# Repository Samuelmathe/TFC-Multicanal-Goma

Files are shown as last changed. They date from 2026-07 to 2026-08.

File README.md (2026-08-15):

# TFC Multicanal Goma

Système embarqué IoT de sous-comptage électrique multicanal (ESP32),
développé dans le cadre d'un Travail de Fin de Cycle (ULPGL) : un boîtier
mesure et facture séparément la consommation électrique de plusieurs
locataires branchés sur une même installation, avec coupure automatique par
crédit prépayé et consultation via une application mobile Flutter.

## État du projet

- **Maquette physique** : construite, soudée sur carte perforée et
  **validée sur matériel réel** (4 canaux : 1 bailleur + 3 locataires,
  capteurs simulés par des potentiomètres). C'est cette maquette qui a servi
  à la validation présentée dans le mémoire.
- **Application mobile Flutter** : développée et testée en conditions
  réelles (connexion Wi-Fi à l'ESP32 depuis un téléphone Android).
- **PCB (circuit imprimé, 8 canaux, capteurs ACS712/ZMPT101B réels)** :
  conçu sous KiCad (dossier `kicad/`) — **routage non terminé, il reste 10
  pistes à tracer** ; non encore fabriqué ni assemblé. Le firmware cible pour
  ce PCB (`firmware_pcb_capteurs_reels/`) est écrit et compile, mais n'a donc
  pas pu être testé sur le matériel réel.

## Structure du dépôt

```
firmware/                      -> firmware de la maquette physique (4 canaux,
                                   potentiometres) - construit et valide
firmware_pcb_capteurs_reels/    -> firmware cible pour le PCB (8 canaux,
                                    ACS712 + ZMPT101B) - PCB pas encore
                                    fabrique, code non teste sur materiel reel
application/                     -> application mobile Flutter (Android/iOS)
kicad/                            -> conception du circuit imprime (PCB, 8 canaux)
rapport/                           -> memoire de TFC
presentation/                       -> support de soutenance
```

Chaque dossier de firmware a son propre `README.md` avec le détail de ce qui
a été testé ou non.

## Démarrer

- Firmware maquette : `cd firmware && pio run --target upload` (ESP32 branché
  en USB) — voir `GUIDE_ASSEMBLAGE_ET_FLASH.md` et `GUIDE_MAQUETTE_BOITIER.md`
  à la racine pour le montage physique.
- Application mobile : `cd application && flutter run` (ou `build_apk.sh`
  pour générer un APK).

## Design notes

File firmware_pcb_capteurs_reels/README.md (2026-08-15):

# Firmware "capteurs reels" (ACS712 + ZMPT101B, 8 canaux) — PCB

**Statut : non testé sur matériel réel.** Le circuit imprimé conçu sous
KiCad (dossier `../kicad/`) n'a pas encore été fabriqué ni assemblé. Ce
firmware est le design cible pour ce PCB à 8 canaux (chapitre 2 du mémoire),
écrit et documenté, mais jamais exécuté sur les vrais capteurs ACS712 /
ZMPT101B.

Pour la version **réellement construite et validée** (maquette sur carte
perforée, 4 canaux, potentiomètres simulant les capteurs, cf. rapport
chapitre 3), voir le dossier voisin [`../firmware/`](../firmware/).

## Ce qui diffère de la maquette

| | `firmware/` (maquette, validée) | `firmware_pcb_capteurs_reels/` (ce dossier) |
|---|---|---|
| Canaux | 4 (1 bailleur + 3 locataires) | 8 (1 bailleur + 7 locataires) |
| Capteur de courant | Potentiomètre (tension DC proportionnelle) | ACS712-20A (signal AC réel, RMS calculé sur 40 échantillons/cycle 50 Hz) |
| Capteur de tension | Potentiomètre | ZMPT101B |
| cos(φ) | Fixé à 1 (simplification assumée) | Calculé réellement : `P/S` à partir de `P`, `S = I_eff x V_eff`, `Q = √(S²-P²)` |
| Broches ADC | Toutes sur ADC1 | Canaux 1 et 2 + tension sur ADC2 (cf. Tableau 2.2 du mémoire), avec gestion explicite du conflit ADC2/Wi-Fi (`lireADC2Securise`) |
| Matériel exécuté dessus | ESP32 réel, testé et flashé | Aucun — code seul, PCB non fabriqué |

L'algorithme d'acquisition (échantillonnage synchrone courant/tension,
calcul RMS, puissance active/apparente/réactive, cos(φ) réel) suit
exactement la description du mémoire, §2.7.

## Constantes à calibrer avant toute mise en service

Ces valeurs, dans `src/config.h`, sont des valeurs nominales de datasheet ou
des estimations — **pas des mesures faites sur le circuit réel** (qui
n'existe pas encore) :

- `ACS712_SENSIBILITE_V_PAR_A` (100 mV/A, valeur datasheet Allegro pour la
  variante 20A — la tolérance fabricant réelle peut différer de quelques %)
- `ZMPT_FACTEUR_CALIBRATION` (rapport tension secteur réelle / tension RMS
  mesurée à l'ADC — dépend du pont diviseur exact du module ZMPT101B utilisé,
  à déterminer par comparaison avec un multimètre/wattmètre une fois le PCB
  assemblé)

Les offsets DC (Vcc/2 par canal) sont recalibrés automatiquement à chaque
démarrage (`calibrerOffsets()`), en supposant qu'aucun courant ne circule
encore à l'allumage.

## Limitation connue : ADC2 et Wi-Fi

Les canaux 1, 2 et la mesure de tension (ZMPT101B) utilisent l'ADC2 de
l'ESP32, qui n'est pas utilisable pendant que le pilote Wi-Fi l'occupe (le
point d'accès de la maquette tourne en permanence). Le firmware détecte ce
cas via le code retour d'`adc2_get_raw()` et ignore simplement l'échantillon
concerné (plutôt que d'enregistrer une fausse valeur, piège classique
d'`analogRead()` sur ADC2). Cf. mémoire §1.4.3 pour la discussion complète de
cette contrainte matérielle et son impact réduit sur le PCB final par
rapport à la maquette (fenêtres ponctuelles plutôt que Wi-Fi permanent).

## Compiler

Comme pour `firmware/` : `pio run` (compilation seule, aucun upload possible
sans le matériel).

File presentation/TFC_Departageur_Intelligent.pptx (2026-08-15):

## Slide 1

UNIVERSITÉ ULPGL — FACULTÉ DE GÉNIE INFORMATIQUE

Conception d'un Système IoT de

Comptage et de Coupure Automatique

d'Énergie pour la Gestion Transparente

en Milieu Locatif Urbain

Travail de Fin de Cycle — G3 Génie Informatique

Présenté par : SAMUEL MATHE | Encadreur : Master VINGI| Année : 2025–2026

📍 Goma, RDC

Mots-clés : ESP32 — IoT — ACS712 — ZMPT101B — Énergie — Milieu locatif — Goma

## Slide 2

PLAN DE PRÉSENTATION

Problématique

Contexte énergétique en milieu locatif à Goma

01

Hypothèse

Solution proposée et résultats attendus

02

Méthodologie

Architecture, composants et implémentation

03

Résultats attendus

Validation et impact mesurable

04

Conclusion

Bilan et perspectives

05

Démonstration

Maquette et application testees en direct

06

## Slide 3

01 PROBLÉMATIQUE

CONTEXTE — GOMA

Alimentation électrique : SOCODEE / Virunga / NURU
Structure des concessions :
Un compteur principal (bailleur)
Des sous-compteurs prépayés (locataires)
Problème observé :
Le bailleur se branche AVANT les sous-compteurs — consomme sur le crédit des locataires sans être mesuré.

CONSÉQUENCES

Augmentation injustifiée des coûts de production pour les locataires

Baisse de la rentabilité des ménages locataires

Conflits récurrents bailleur–locataires non résolus

Absence totale de transparence dans la consommation partagée

Coupures imprévisibles sans notification préalable

💸

📉

⚔️

🌍

🔌

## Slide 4

01 PROBLÉMATIQUE — Question de recherche

Question de recherche

Comment la mise en place d'un système embarqué IoT
pourrait-elle assurer une gestion équitable, transparente
et automatique de la consommation électrique entre
bailleur et locataires dans une concession résidentielle ?

~$15

Coût sous-compteur actuel

sans coupure automatique

7–8

Locataires par concession

moyenne Goma

0

Outil transparent existant

marché local actuel

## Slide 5

02 HYPOTHÈSE

Hypothèse principale

Un système embarqué à base d'ESP32, équipé de capteurs ACS712 (courant) et ZMPT101B (tension), couplé à des relais optocoupleurs et une interface web locale, permet de mesurer avec précision la consommation individuelle de chaque locataire, d'assurer une coupure automatique au dépassement du crédit, et de garantir une transparence totale — sans modifier l'installation existante et pour un coût inférieur à $30.

⚡ Mesure précise

Courant (ACS712) × Tension réelle (ZMPT101B) = kWh exact

🔒 Coupure automatique

Relais ouvre quand crédit = 0 — aucune intervention manuelle

📱 Interface transparente

Locataire voit son crédit, historique et recharges en temps réel

💰 Coût accessible

<$30/unité* — partagé entre 8 personnes = <$3.75 chacun*

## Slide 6

03 MÉTHODOLOGIE — Architecture du système

⚡ ZONE 220V — Haute tension

HLK-PM01
220V→5V
$2

ZMPT101B
Mesure tension
$0.8

Relais 8ch
Pilotage ULN2003A
$2.5

Bornes sorties
À vis étiquetées
$1.5

━━━ CLOISON ISOLANTE PLASTIQUE ━━━━━━━━━━━━━━━━━━━━━━━━━━━━━━━━━━━━━━━━━━━━━━━━

Seuls les fils signal GPIO 3.3V traversent la cloison — isolation galvanique garantie

🔵 ZONE 5V — Basse tension

ESP32 DevKit
Dual Core Wi-Fi
$4

ACS712 ×8
Mesure courant
$6.4

TP4056
Charge LiPo
$0.5

LiPo 2000mAh
Alimentation cont.
$2.5

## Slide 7

03 MÉTHODOLOGIE — Composants et budget

Composant | Rôle | Qté | Prix unit. | Total
ESP32 DevKit V1 | Centrale Wi-Fi + logique | 1 | $4.00 | $4.00
Relais 8 canaux optocoupleur | Coupure automatique | 1 | $2.50 | $2.50
ACS712 20A | Mesure courant par locataire | 8 | $0.80 | $6.40
ZMPT101B | Mesure tension réseau réelle | 1 | $0.80 | $0.80
HLK-PM01 220V→5V | Alimentation isolée | 1 | $2.00 | $2.00
TP4056 + protection | Charge batterie LiPo | 1 | $0.50 | $0.50
LiPo 3.7V 2000mAh | Alimentation continue | 1 | $2.50 | $2.50
Bornes à vis + câblage | Connexions sorties | 1 kit | $3.50 | $3.50
Boîtier électrique | Protection + sécurité | 1 | $4.00 | $4.00
TOTAL MATÉRIEL | | | | ~$26.20

💡 <$3.75* / personne
*à l'échelle de 100 unités — prototype unique : 60-90$
(8 personnes : bailleur + 7 locataires)

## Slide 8

03 MÉTHODOLOGIE — Firmware et calcul kWh

kWh = P active × Temps (h) ÷ 1000 (P calculee, cos(φ) jamais suppose)

Formule de calcul — Énergie consommée

Lecture capteurs

- ZMPT101B → ADC2 GPIO25
- Tension réelle (pas 220V fixe)
- ACS712 ×8 → ADC1 GPIO36-39,32-35
- Courant par locataire
- Filtrage : moyenne de 8 mesures

Logique de coupure

- Calcul kWh chaque seconde
- Déduction du crédit locataire
- Crédit = 0 → relais OUVRE
- Coupure automatique immédiate, ou volontaire (absence)
- Alerte Wi-Fi vers interface

Sauvegarde NVS

- kWh sauvegardé toutes les 5 sec
- Batterie ≤25% → sauvegarde forcée
- Résistant aux coupures 220V
- Données jamais perdues
- Historique 30 jours conservé

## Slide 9

03 MÉTHODOLOGIE — Interface web locale

📶 ESP32 Access Point — SSID: Departageur — Aucun internet requis

🔐 Bailleur — Accès sécurisé

Route : /admin

- Mot de passe requis côté ESP32
- Ajout du courant de locataire
- Saisie crédit kWh par locataire
- Date et heure de chaque recharge
- Vue globale tous locataires
- Coupure / rétablissement manuel
- Configuration du système

👁 Locataires — Lecture seule

Route : /L1 à /L7

- Crédit restant en kWh — temps réel
- Consommation actuelle (Watts)
- Conversion kwh restant-monnaie visuelle
- Historique recharges avec dates
- Peut comparer avec facture bailleur
- Alerte crédit faible automatique
- Historique jour / semaine / mois

🔒 Sécurité : vérification mot de passe côté ESP32 (pas en JavaScript) — Reset physique si oublié — Boîtier fermé à clé

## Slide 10

04 RÉSULTATS ATTENDUS

❌ AVANT — Situation actuelle

- Bailleur consomme sans être mesuré
- Aucune transparence sur la consommation
- Coupure manuelle par le bailleur uniquement
- Conflits récurrents non résolus
- Sous-compteur $15 sans coupure auto
- Locataire ne peut pas vérifier sa consommation

✅ APRÈS — Avec le système

- Chaque consommation mesurée individuellement
- Interface web — historique transparent
- Coupure automatique au dépassement du crédit
- Conflits résolus par preuves numériques
- Coût partagé <$3.75* par personne
- Locataire voit son crédit en temps réel

→

Perspectives : V2 — 16 canaux | App Flutter (APK fonctionnel, testee sur maquette physique) | Partenariat revendeur agréé (PayIt/Fondeka) pour intégration SOCODEE/Virunga/NURU

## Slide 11

05 CONCLUSION

Ce projet démontre qu'un système IoT embarqué à faible coût peut résoudre un problème social et économique réel vécu quotidiennement à Goma — sans infrastructure internet, sans modification de l'installation existante, avec une transparence totale pour toutes les parties.

🔬

Technique

ESP32 + C++
ACS712 + ZMPT101B
Firmware complet
App Flutter (3 profils, testee)

💰

Économique

<$30/unité*
<$3.75* chacun
ROI immédiat

🤝

Social

Fin des conflits
Transparence totale
Équité énergétique

🚀

Perspective

V2 16 canaux
Notifications SMS (GSM)
Partenariat PayIt/Fondeka

Merci pour votre attention — Questions et suggestions bienvenues

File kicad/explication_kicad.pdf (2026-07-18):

# Explication et guide KiCad — TFC Système Multicanal

### Notions de base + pas-à-pas pour dessiner le schéma

### Document préparé pour Samuel Mumbere Mathe — ULPGL

### Juillet 2026

## Table des matières

Introduction | 1
Partie 1 — Les bases de KiCad et de l’électronique qu’il faut connaître | 1
Partie 2 — Guide pas-à-pas : dessiner le schéma | 3

## Introduction

Ce document a deux parties : d’abord les notions de base pour comprendre ce qu’on fait dans KiCad (utile même si tu ne dessines rien toi-même, pour répondre au jury), puis le guide pratique, pas-à-pas, pour redessiner le schéma de ton système à 8 canaux.

## Partie 1 — Les bases de KiCad et de l’électronique qu’il faut connaître

### C’est quoi KiCad ?

KiCad est un logiciel gratuit de conception électronique (on dit “EDA” : Electronic Design Automation). Il sert à transformer une idée de circuit en un vrai fichier de fabrication qu’une usine peut lire pour produire un circuit imprimé (PCB). Il y a deux grands outils dans KiCad :

1. Schematic Editor (éditeur de schéma) — où on dessine le schéma électrique : quels composants, et comment ils sont reliés entre eux (comme un plan, pas encore un objet physique).
2. PCB Editor (éditeur de circuit imprimé) — où on transforme ce schéma en un vrai dessin de plaque, avec l’emplacement physique de chaque composant et le tracé des pistes de cuivre qui les relient.

Ton mémoire (§2.5) couvre les deux : le schéma (§2.5.1-2.5.2) puis le PCB (§2.5.3-2.5.4). Ce guide se concentre sur le schéma d’abord — le PCB est l’étape suivante, une fois le schéma solide (voir le document séparé explication_pcb.pdf).

### C’est quoi un “symbole” ?

Un symbole, c’est la représentation graphique standardisée d’un composant sur un schéma — un rectangle avec des pattes numérotées pour une puce, un zigzag pour une résistance, etc. Ce n’est pas un dessin réaliste du composant, juste une convention universelle pour que n’importe quel ingénieur comprenne le schéma. Chaque symbole est identifié par un nom, rangé dans une bibliothèque (un fichier .kicad_sym qui contient plusieurs symboles apparentés, par exemple tous les microcontrôleurs Espressif).

### C’est quoi une “empreinte” (footprint) ?

Une empreinte, c’est le dessin de l’emplacement physique réel des pattes d’un composant sur le circuit imprimé (les petits rectangles de cuivre où on soudera le composant). Un même symbole électrique (par exemple une résistance) peut avoir plusieurs empreintes possibles, selon la taille physique du composant qu’on va réellement souder. On choisit l’empreinte à l’étape PCB, pas à l’étape schéma.

### C’est quoi un “netlist” ?

Une fois le schéma terminé, KiCad peut en extraire une liste de toutes les connexions électriques prévues (“la broche 3 du composant A est reliée à la broche 1 du composant B”, etc.) — c’est le netlist. C’est ce fichier qui fait le pont entre le schéma et le PCB : KiCad l’utilise pour savoir quelles pistes de cuivre tracer.

### C’est quoi l’ERC (Electrical Rules Check) ?

Un vérificateur automatique qui relit ton schéma et signale les erreurs probables : une broche qui n’est reliée à rien, deux sorties reliées directement entre elles (conflit électrique), etc. Toujours le lancer avant de continuer — c’est l’équivalent d’un correcteur orthographique, mais pour un circuit.

### Zone haute tension / basse tension, isolation galvanique

Ton système manipule à la fois du 230V (secteur) et du 3.3V/5V (électronique de l’ESP32). Physiquement séparer ces deux zones sur le schéma et sur le circuit imprimé (avec une distance de sécurité suffisante entre les pistes) est une exigence de sécurité, pas juste d’organisation — un défaut du côté 230V ne doit jamais pouvoir atteindre la partie que l’utilisateur touche (l’ESP32, le port USB…). C’est exactement ce que rappelle ton mémoire en §1.3.4 et §2.5.1, et que les capteurs ACS712/ZMPT101B assurent physiquement (isolation galvanique = aucune connexion électrique directe entre les deux côtés, seulement un couplage magnétique ou optique).

## Partie 2 — Guide pas-à-pas : dessiner le schéma

Tu peux commencer avant d’avoir l’ESP32 physique — rien ici ne demande le matériel en main.
État au 17 juillet : d’après ton fichier multical.kicad_sch, il te manque un deuxième ULN2003A (tu n’en as qu’un, avec 7 sorties pour 8 relais — voir étape 3 ci-dessous) et le câblage n’est pas encore fait — voir la correction du Tableau 2.2 à l’étape 5 avant de commencer à câbler.

### Étape 0 — Lancer KiCad

Deux installations existent sur cette machine : une snap (KiCad 9.0.7, périmée) et une flatpak (KiCad 10.0.4, la version stable actuelle, vérifiée en juillet 2026). Utilise la flatpak :

flatpak run org.kicad.KiCad

(ou depuis le menu applications — si deux icônes “KiCad” apparaissent, vérifie dans Aide → À propos que tu ouvres bien la 10.0.4)

### Étape 1 — Créer le projet

1. Fichier → Nouveau projet
2. Nomme-le multicanal_goma (évite les espaces/accents dans le nom de fichier — KiCad n’aime pas toujours ça)
3. Sauvegarde-le directement dans : ~/Documents/TFC-Multicanal-Goma/kicad/ (là où se trouve déjà ce guide et le symbole zmpt101b.kicad_sym, à côté du firmware et de l’application)
4. Double-clique sur l’icône Schematic Editor (feuille bleue) dans la fenêtre du projet

### Étape 2 — Format de feuille

Fichier → Propriétés de la feuille → choisis A3 (le schéma a beaucoup de composants, A4 sera trop serré). Remplis le cartouche (titre, date, ton nom, “Encadreur: Patrick Nzanzu Vingi” — retrouvé dans un ancien fichier de travail).

### Étape 3 — Placer les composants

Touche A (ou icône “Placer un symbole”) ouvre le sélecteur. Tape le nom exact ci-dessous dans la barre de recherche.

Important : un ancien fichier de travail contenait des noms de composants qui n’existent pas réellement dans les bibliothèques KiCad — c’est probablement pour ça qu’il ne s’ouvrait plus. Chaque nom ci-dessous a été vérifié individuellement contre les vraies bibliothèques installées sur ta machine, dans les deux versions de KiCad présentes (9.0.7 et 10.0.4 — identiques sur ce point).

Cherche exactement | Bibliothèque réelle | Combien | Où le placer
ESP32-WROOM-32 | RF_Module | 1 | Centre
ACS712xLCTR-20A | Sensor_Current | 8 | Colonne de gauche,
| | | zone BT

Cherche exactement | Bibliothèque réelle | Combien | Où le placer
ULN2003A | Transistor_Array | 2 | Entre ESP32 et
| | | relais (chacun pilote
| | | jusqu’à 7 sorties, 2
| | | suffisent pour 8
| | | relais — tu n’en as
| | | qu’1 pour l’instant)
Relay_SPDT | Relay | 8 | Colonne de droite,
| | | zone HT (voir note
| | | ci-dessous)
HLK-PM01 | Converter_ACDC | 1 | Zone HT →
| | | alimentation
AMS1117-3.3 | Regulator_Linear | 1 | Zone BT, juste après
| | | le HLK-PM01
D (diode générique) | Device | 8 | Une en parallèle de
| | | chaque relais (roue
| | | libre)
R | Device | 5 | Pull-up strapping
| | | pins + limitation
| | | courant
C | Device | 5 | Découplage (près
| | | des VCC ACS712 et
| | | ESP32)
Conn_01x02_Pin | Connector | 9 | Un par canal +
| | | alimentation secteur

ZMPT101B — pas dans les bibliothèques standard

Ce capteur n’existe dans aucune bibliothèque KiCad officielle (normal, c’est un module très “communauté Arduino”, pas un composant industriel référencé). Un symbole personnalisé valide existe déjà dans ~/Documents/TFC-Multicanal-Goma/kicad/zmpt101b.kicad_sym (6 broches : L, N, GND, GND, VCC, OUT — correspond au vrai module), et tu l’as déjà importé avec succès (visible sur ton schéma actuel, U12).

Relais SLA-05VDC-SL-A — pas de symbole exact non plus

Le nom précis “SLA-05VDC-SL-A” (celui des modules relais tout faits pour Arduino) n’a pas de symbole officiel KiCad. Le symbole générique Relay_SPDT (déjà utilisé sur ton schéma pour K1-K8) est fonctionnellement identique — bobine 5V + contact inverseur. Pense à changer le champ Valeur de “Relay_SPDT” à “SLA-05VDC-SL-A” dans les propriétés de chaque relais pour que ta nomenclature (BOM) reste exacte.

### Étape 4 — Séparer les zones HT et BT (§2.5.1 du mémoire)

C’est le point que ton mémoire promet déjà — respecte-le visuellement dans le schéma, pas juste dans le texte. Sur ton schéma actuel, les 8 relais/diodes sont déjà groupés à droite et l’électronique basse tension à gauche, ce qui va dans le bon sens, mais il manque encore la séparation explicite :

- Zone haute tension (230V), à droite ou en haut de la feuille : arrivée secteur (Conn_01x02_Pin), les 8 relais, le HLK-PM01.
- Zone basse tension (3.3V/5V), à gauche ou en bas : ESP32, les 8 ACS712, l’AMS1117, les ULN2003A.

- Le ZMPT101B et les ACS712 sont la frontière (isolation galvanique, cf. §1.3.4) — dessine une ligne ou une boîte en pointillés entre les deux zones sur la feuille, avec une annotation “ISOLATION GALVANIQUE” comme rappel visuel pour le jury.

### Étape 5 — Câblage : reprends le Tableau 2.2 (corrigé) du mémoire

Correction importante : contrairement à ce qui était dit dans une version précédente de ce guide, le symbole ESP32-WROOM-32 que tu utilises (vérifié directement dans la bibliothèque KiCad) n’a pas non plus les broches GPIO37/GPIO38 — elles n’existent pas sur ce module, DevKitC ou pas. Il n’y a donc que 6 broches ADC1 réellement utilisables (36, 39, 32, 33, 34,
35) pour 8 canaux. Les canaux 2 et 3 sont déplacés sur ADC2 (GPIO26, GPIO27), sur le même principe déjà utilisé pour le ZMPT101B (lecture pendant les fenêtres où le Wi-Fi est inactif, cf. §1.4.3 du mémoire — désormais 3 signaux à gérer ainsi au lieu d’1, mais aucun composant supplémentaire nécessaire) :
Canal | ACS712 → ESP32 ADC | Relais → ESP32 (via ULN2003A)
1 (bailleur) GPIO36 | ADC1 GPIO4
2 | GPIO26 | ADC2 GPIO5
3 | GPIO27 | ADC2 GPIO13
4 | GPIO39 | ADC1 GPIO14
5 | GPIO32 | ADC1 GPIO16
6 | GPIO33 | ADC1 GPIO17
7 | GPIO34 | ADC1 GPIO18
8 | GPIO35 | ADC1 GPIO19

ZMPT101B → GPIO25 (ADC2).
Évite ces broches pour toute nouvelle affectation (broches de configuration au démarrage, dites “strapping pins”, déjà notées en §2.5.2 du mémoire) : GPIO0, GPIO2, GPIO12, GPIO15.
Pour tracer un fil : touche W (wire), clique départ, clique arrivée. Pour nommer un fil (utile pour les signaux qui se répètent, ex. CANAL1_ACS) : sélectionne-le puis touche L (label). Donner le même nom à deux bouts de fil différents les relie électriquement, sans avoir à tracer un trait continu à travers toute la feuille — pratique pour éviter un schéma illisible avec des lignes qui se croisent partout.

### Étape 6 — Vérifier avant de continuer

Inspecter → Vérification des règles électriques (ERC) — lance-le, corrige les erreurs (broches non connectées, conflits de type de pin). Ne passe au routage du circuit imprimé (PCB, §2.5.3 du mémoire) qu’une fois l’ERC propre.

### Étape 7 — Sauvegarder correctement

Ctrl+S régulièrement. KiCad enregistre automatiquement les définitions complètes des symboles utilisés dans le fichier — tant que tu passes par le vrai logiciel (et pas un script), un fichier cassé comme l’ancien ne peut pas se reproduire.

### Et après ?

Une fois le schéma terminé et l’ERC propre, l’étape suivante est le routage du circuit imprimé — voir le document séparé explication_pcb.pdf, déjà prêt pour cette étape.

Reviens vers moi avec une capture d’écran ou une description si tu bloques sur un placement ou un câblage précis — je peux aussi lire un export PDF du schéma directement si tu me donnes le chemin du fichier.

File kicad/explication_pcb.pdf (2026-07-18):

# Explication et guide PCB — TFC Système Multicanal

### Notions de base + pas-à-pas pour router le circuit imprimé (§2.5.3-2.5.4)

### Document préparé pour Samuel Mumbere Mathe — ULPGL

### Juillet 2026

## Table des matières

Introduction | 1
Partie 1 — Les bases du PCB qu’il faut connaître | 1
Partie 2 — Pas-à-pas pour ta carte | 3

## Introduction

Ce guide couvre l’étape suivante du schéma déjà expliqué dans explication_kicad.pdf : transformer le schéma terminé en un vrai circuit imprimé (PCB) routé, prêt à envoyer en fabrication. Lis-le une fois ton schéma terminé et son ERC propre (cf. guide précédent, étape 6).

## Partie 1 — Les bases du PCB qu’il faut connaître

### Du schéma au PCB : le netlist

Quand tu ouvres le PCB Editor depuis un projet dont le schéma est terminé, KiCad propose Mettre à jour le PCB depuis le schéma (icône avec une flèche verte, ou Outils → Mettre à jour le PCB depuis le schéma). Cette action lit le netlist (déjà défini en Partie 1 du guide précédent) et fait apparaître, en vrac sur le côté de la feuille PCB, tous les composants du schéma sous forme d’empreintes (footprints) — reliés entre eux par des fils fantômes appelés ratsnest (“nid de rat” — les lignes droites qui indiquent quelles pattes doivent finir connectées, avant que tu traces les vraies pistes).

### Les couches (layers)

Un circuit imprimé est fait de plusieurs couches empilées. Pour un projet comme le tien, une carte 2 couches suffit largement (plus simple et moins chère qu’une carte 4+ couches, qui serait nécessaire pour un projet beaucoup plus dense) :

- F.Cu (couche cuivre du dessus) et B.Cu (couche cuivre du dessous) : où passent les pistes électriques
- F.SilkS / B.SilkS : la sérigraphie (texte et repères imprimés en blanc sur la carte, pour identifier les composants)
- F.Mask / B.Mask : le masque de soudure (la couche verte/autre couleur qui protège le cuivre, avec des trous là où on doit souder)
- Edge.Cuts : le contour de la carte (sa forme découpée)

### Empreinte (footprint) : le lien manquant

Chaque symbole du schéma doit avoir une empreinte assignée avant de passer au PCB — sinon KiCad ne sait pas quel dessin physique utiliser. Les composants “standards” (résistance, condensateur, ESP32…) ont souvent une empreinte par défaut déjà liée. Mais pour les composants génériques ou personnalisés de ton projet — le Relay_SPDT (renommé “SLA-05VDC-SL-A”) et le zmpt101b personnalisé — il faudra assigner une empreinte toi-même :
1. Outils → Attribuer les empreintes (ou Éditeur d'associations d'empreintes)
2. Pour chaque composant sans empreinte, cherche dans la bibliothèque une empreinte dont l’espacement de pattes correspond à ton composant réel (mesure au pied à coulisse si tu as le composant en main, ou regarde la fiche technique du vendeur)

### Largeur des pistes : pas la même partout

Une piste de cuivre trop fine chauffe et peut griller si elle transporte trop de courant — l’équivalent d’un fil électrique trop fin dans une installation domestique. KiCad a un outil intégré : Outils → Calculateur d’impédance des pistes / Calculateur PCB (Track Width Calculator), qui donne la largeur minimale nécessaire selon le courant à faire passer et l’échauffement toléré.

Deux catégories bien différentes sur ta carte : - Pistes de signal (GPIO, communication) : très fines, quelques dixièmes de mm suffisent, aucun souci de courant. - Pistes de puissance (230V secteur, alimentation des relais, retour des ACS712) : dimensionne-les pour le courant maximal réel du canal (rappel de ton mémoire : ACS712 20A, mais la charge réelle par canal sera probablement bien inférieure — utilise le courant que tu attends vraiment, pas la pleine échelle du capteur). Une piste plus large que nécessaire n’est jamais un problème, seulement plus étroite que nécessaire.

### Distance de sécurité HT/BT (creepage)

C’est le point le plus important de ton PCB, déjà annoncé au chapitre 2.5.1 de ton mémoire. Il n’existe pas “une seule valeur magique” — la distance nécessaire dépend de la tension, de l’épaisseur du vernis, de l’altitude, etc. (normes IEC 60664-1 / IPC-2221 pour qui veut creuser). En pratique, pour un projet de ce type (230V, usage intérieur, carte grand public) :

- Beaucoup de conception “prosumer” retiennent une distance minimale de l’ordre de 6 à

### 8 mm entre une piste 230V et n’importe quelle piste basse tension, comme point de dé-

part raisonnable et cité couramment dans la littérature hobbyiste/prosumer — vérifie et documente cette valeur dans ton mémoire comme une hypothèse de sécurité, pas comme une certification, ton travail n’ayant pas été testé/certifié par un laboratoire.
- Pour renforcer visuellement et physiquement cette séparation, une pratique courante est de découper une fente (slot) dans la carte entre les deux zones (juste un rectangle vide dans le PCB) — ça augmente la distance réelle que le courant devrait parcourir en cas de défaut, au-delà de la simple distance en ligne droite.
- Le fabricant de PCB que tu utiliseras (JLCPCB ou autre) publie ses propres règles minimales de fabrication (largeur de piste, espacement, diamètre de perçage) — vérifie-les avant de finaliser, elles peuvent être plus contraignantes que ce que KiCad accepte par défaut.

### DRC (Design Rules Check) — l’ERC du PCB

Comme l’ERC pour le schéma, le DRC vérifie le PCB : pistes trop proches, composants qui se chevauchent, trous mal dimensionnés, zones non connectées. Toujours lancer le DRC avant d’exporter les fichiers de fabrication (Inspecter → Vérification des règles de conception).

### Via

Un via, c’est un petit trou métallisé qui fait passer une piste d’une couche de cuivre à l’autre (du dessus vers le dessous de la carte). Utile quand une piste ne peut pas continuer tout droit sur la même face à cause d’un autre composant ou d’une autre piste sur son chemin.

### Fichiers de fabrication (Gerber, drill, BOM) — §2.5.4 du mémoire

Une fois le routage terminé et le DRC propre :

- Fichier → Fabrication → Fichiers Gerber : génère un fichier par couche (cuivre dessus, cuivre dessous, sérigraphie, masque de soudure…) — le format universel que toutes les usines de PCB comprennent.
- Fichier → Fabrication → Fichier de perçage : la position et le diamètre de chaque trou.
- Outils → Générer la nomenclature (BOM) : la liste de tous les composants avec leurs références, pour commander/assembler.

La plupart des fabricants (JLCPCB, PCBWay…) acceptent directement un .zip contenant tous ces fichiers.

## Partie 2 — Pas-à-pas pour ta carte

### Étape 1 — Ouvrir l’éditeur PCB et importer le schéma

Depuis la fenêtre du projet KiCad, double-clique sur PCB Editor, puis Outils → Mettre à jour le PCB depuis le schéma. Tous tes composants apparaissent en tas sur le côté, reliés par le ratsnest.

### Étape 2 — Dessiner le contour de la carte

Sélectionne la couche Edge.Cuts (en bas de la fenêtre), puis dessine un rectangle (ou la forme voulue) avec l’outil ligne/rectangle. Prévois de la place pour 8 canaux + les composants d’alimentation — commence par une carte assez grande (tu pourras réduire à une version future si besoin).

### Étape 3 — Placer les empreintes en respectant les zones HT/BT

Reprends exactement la même logique que sur le schéma (§2.5.1 du mémoire, déjà appliquée dans le guide précédent) : place les composants haute tension (relais, HLK-PM01, bornier secteur) d’un côté de la carte, et les composants basse tension (ESP32, ACS712, AMS1117, ULN2003A) de l’autre — avec une bande vide (la distance de sécurité, cf. Partie 1) qui les sépare visuellement sur la carte, pas seulement sur le schéma.

Touche M pour déplacer une empreinte sélectionnée, R pour la faire pivoter.

### Étape 4 — Router les pistes

Touche X (ou icône piste) pour commencer une piste depuis une pastille ou un ratsnest, clic pour poser un point, clic droit ou Échap pour terminer. Utilise le calculateur de largeur de piste (Partie 1) avant de router les lignes de puissance — change la largeur de piste active avant de commencer à tracer (barre d’outils en haut, “Largeur de piste actuelle”).

Conseil pratique : route d’abord les pistes de puissance (plus larges, plus contraignantes à placer), puis les pistes de signal (plus fines, plus faciles à faire passer entre les autres).

### Étape 5 — Vérifier

Inspecter → Vérification des règles de conception (DRC) — corrige tout ce qui est signalé avant de continuer. Regarde aussi la vue 3D (Affichage → Visualiseur 3D) pour repérer visuellement un composant mal placé ou qui se chevauche avec un autre.

### Étape 6 — Exporter pour la fabrication

Une fois le DRC propre : génère les Gerber, le fichier de perçage et la BOM (Partie 1). Regroupe-les dans un .zip et c’est prêt à envoyer chez le fabricant.

Reviens vers moi une fois le schéma terminé, avant de commencer le routage — je peux relire un export du PCB (image ou PDF) et repérer un souci de placement ou de distance HT/BT avant que tu envoies en fabrication.

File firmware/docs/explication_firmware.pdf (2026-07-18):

# Explication du firmware — TFC Système Multicanal

### Guide pas-à-pas pour quelqu’un qui ne connaît pas le C++

### Document préparé pour Samuel Mumbere Mathe — ULPGL

### Juillet 2026

## Table des matières

Introduction | 2
Partie 1 — Les bases du C++ qu’il faut connaître | 2
Partie 2 — config.h : les réglages du système | 3
Partie 3 — Vue d’ensemble de main.cpp | 4
Partie 4 — Explication détaillée, bloc par bloc | 5
Partie 5 — Comment tout s’articule (résumé visuel) | 11
Glossaire rapide | 12

## Introduction

Ce document explique, ligne par ligne et sans rien supposer connu, le fichier src/main.cpp du projet firmware (et son fichier de réglages src/config.h). Ce code fait tourner ton système à 5 canaux sur l’ESP32 : il lit les potentiomètres, calcule courant/puissance/énergie, gère les crédits, coupe les canaux, sauvegarde les données, et sert une API web.

Tu n’as pas besoin de tout retenir. L’objectif est qu’en relisant ton code tu puisses répondre si un membre du jury demande “qu’est-ce que fait cette ligne ?” — pas de devenir développeur C++ en une lecture.

## Partie 1 — Les bases du C++ qu’il faut connaître

Le C++ est le langage utilisé pour programmer les microcontrôleurs comme l’ESP32 (via l’environnement Arduino/PlatformIO). Voici uniquement les notions utilisées dans ton fichier — pas tout le langage.

### Une variable

Une variable, c’est une boîte étiquetée qui contient une valeur. En C++, il faut dire de quel type est la valeur avant de pouvoir l’utiliser :
int | age = 25; | // int = nombre entier
float | tension = 3.3; | // float = nombre a virgule (decimal)
bool | allume = true; | // bool = vrai ou faux (true/false)
String nom = "Samuel"; | // String = texte

Dans ton fichier, tu verras énormément int, float, bool, String — ce sont juste les types de boîtes.

### Une constante

const veut dire “cette boîte ne changera jamais après avoir été remplie”. static const int PIN_TENSION = 25; veut dire : la broche du capteur de tension, c’est GPIO25, et ça ne changera pas pendant l’exécution.

### Un tableau

Un tableau, c’est une rangée de boîtes numérotées à partir de 0 :

int notes[3] = {12, 15, 9};
// notes[0] = 12
// notes[1] = 15
// notes[2] = 9

Dans config.h, PIN_COURANT[NUM_CANAUX] est un tableau de 5 cases, une par canal, qui contient le numéro de broche GPIO de chaque potentiomètre.

### Une fonction

Une fonction, c’est une recette : elle prend des ingrédients (les “paramètres”), fait des opérations, et parfois rend un résultat.

float doubler(float x) { // "doubler" prend un float, rend un float
return x * 2;
}

void veut dire “cette fonction ne rend rien, elle fait juste une action”. La plupart des fonctions de ton fichier sont void.

### Une structure (struct)

Une structure, c’est une fiche avec plusieurs champs regroupés sous un même nom. Ton fichier définit CanalEtat : la fiche d’un canal, avec son courant, sa puissance, son crédit, etc. — tout regroupé, comme une fiche de renseignements pour chaque locataire.

struct CanalEtat {
float courant_A;
float credit_USD;
};
CanalEtat canaux[5]; | // 5 fiches, une par canal
canaux[0].credit_USD = 10; | // remplir le champ credit_USD de la fiche 0

### Boucles et conditions

- for (int i = 0; i < 5; i++) { ... } = répète ce qui est entre accolades, pour i allant de 0 à 4 (5 fois). C’est ce qui permet de traiter les 5 canaux avec un seul bout de code au lieu d’écrire 5 fois la même chose.
- if (condition) { ... } = si la condition est vraie, fais ceci.
- for (;;) { ... } = boucle infinie, ne s’arrête jamais (utilisé dans chaque tâche : elle tourne pour toujours tant que l’ESP32 est allumé).

#include

#include <WiFi.h> = “j’ai besoin des outils du Wi-Fi, va les chercher”. C’est comme importer une bibliothèque de fonctions déjà écrites par quelqu’un d’autre (Espressif, la communauté Arduino…), pour ne pas réinventer la gestion du Wi-Fi, du JSON, etc. depuis zéro.

### Le pointeur * et la référence & (juste pour ne pas être surpris)

Tu verras void *param ou AsyncWebServerRequest *request. Un pointeur, c’est une variable qui contient l’adresse d’une autre donnée, plutôt que la donnée elle-même — un peu comme une adresse postale au lieu de la maison. Tu n’as pas besoin de savoir manipuler ça toi-même pour ce TFC : retiens juste que * est présent quand une fonction accède à quelque chose d’externe (par exemple, la requête HTTP envoyée par un navigateur).

## Partie 2 — config.h : les réglages du système

Ce fichier ne fait rien tout seul — c’est une liste de constantes utilisées partout ailleurs, regroupées à un seul endroit pour être faciles à changer.

#define NUM_CANAUX 5

#define remplace littéralement NUM_CANAUX par 5 partout dans le code avant la compilation. C’est le nombre de canaux de la maquette (1 bailleur + 4 locataires, cf. mémoire §3.6.1).

static const int PIN_COURANT[NUM_CANAUX] = {36, 39, 34, 35, 32};

Le tableau des broches GPIO où sont branchés les 5 potentiomètres “courant” (qui simulent les ACS712). PIN_COURANT[0] = 36 = le canal 0 (bailleur) est lu sur la broche GPIO36. static const int PIN_TENSION = 25;

La broche du potentiomètre “tension” (qui simule le ZMPT101B) — un seul, partagé par tous les canaux.
static const int PIN_RELAIS[NUM_CANAUX] = {4, 5, 13, 14, 16};

Les broches qui commandent les LED (qui simulent les relais). static const float COURANT_MAX_A = 20.0f;
static const float TENSION_MAX_V = 250.0f;

Les valeurs maximales simulées : quand un potentiomètre est tourné à fond, on considère que ça représente 20 A (courant) ou 250 V (tension). Le f à la fin veut juste dire “c’est un float, pas un entier”.
static const float TARIF_USD_PAR_KWH = 0.20f;
static const float CREDIT_INITIAL_USD = 0.05f;

Le prix du kWh (0,20 USD) et le crédit de départ de chaque canal (volontairement très bas — 0,05 USD — pour que la coupure automatique se déclenche vite pendant une démonstration, sans avoir à attendre longtemps).

static const uint32_t PERIODE_ACQUISITION_MS = 500;

uint32_t = encore un type de nombre entier (toujours positif, sur 32 bits — détail technique sans importance ici). Cette ligne dit : on relit les capteurs toutes les 500 millisecondes (0,5 seconde).

## Partie 3 — Vue d’ensemble de main.cpp

Avant les détails, voici le plan général du fichier :

1. Includes — les bibliothèques utilisées (Wi-Fi, serveur web, JSON, système de fichiers, mémoire NVS)
2. La structure CanalEtat — la “fiche” d’un canal
3. Les variables globales — la mémoire partagée du programme
4. Deux fonctions de sauvegarde/chargement (NVS)
5. Cinq tâches FreeRTOS — les 5 “ouvriers” qui tournent en parallèle (Acquisition, Calcul, Crédits, Persistance, Serveur API) — c’est le cœur du programme, détaillé en Partie 4
6. setup() — tout ce qui se lance une seule fois, au démarrage
7. loop() — presque vide ici, parce que tout le travail se fait dans les tâches, pas dans la boucle principale classique Arduino

### C’est quoi une “tâche FreeRTOS” ?

Sur un Arduino classique, il n’y a qu’une seule boucle loop() qui répète tout, l’une après l’autre. L’ESP32 est plus puissant : il a deux cœurs de calcul, et un système appelé FreeR-TOS qui permet de faire tourner plusieurs programmes “en même temps” (en réalité, ils se partagent le temps très rapidement, comme un chef qui bascule entre 5 casseroles sur le feu). Chaque tâche est une fonction avec une boucle infinie for(;;) à l’intérieur, qui tourne indépendamment des autres.

Ton système a 5 tâches — c’est comme avoir 5 employés qui travaillent en parallèle plutôt qu’un seul qui fait tout à la suite : un lit les capteurs, un autre calcule, un autre gère les crédits, un autre sauvegarde, un autre répond aux requêtes du téléphone.

### C’est quoi un “mutex” ?

Les 5 tâches doivent parfois lire ou modifier les mêmes données (le tableau canaux). Si deux tâches essayaient d’écrire dedans exactement au même instant, ça pourrait corrompre les données (un peu comme deux personnes qui écrivent sur la même feuille en même temps).

Un mutex (mutexCanaux dans ton code) est comme une clé unique d’une salle : une tâche doit “prendre la clé” (xSemaphoreTake) avant d’entrer modifier les données, et la “rendre” (xSemaphoreGive) en sortant. Si une autre tâche veut entrer pendant ce temps, elle attend son tour. Ça garantit qu’il n’y a jamais deux tâches en train d’écrire au même moment.

## Partie 4 — Explication détaillée, bloc par bloc

### Les includes (lignes 8-16)

#include <Arduino.h> | // le coeur du framework Arduino (pinMode, digitalRead...)

#include <WiFi.h> | // gerer le point d'acces Wi-Fi de l'ESP32

#include <AsyncTCP.h> | // moteur reseau bas niveau utilise par le serveur web

#include <ESPAsyncWebServer.h>// le serveur web lui-meme (routes /admin, /api/etat...)

#include <ArduinoJson.h> | // creer et lire des donnees au format JSON

#include <LittleFS.h> | // systeme de fichiers dans la memoire flash de l'ESP32

#include <Preferences.h> | // memoire NVS (survit aux coupures/redemarrages)

#include "config.h" | // ton fichier de reglages (Partie 2)

Chaque #include avec des chevrons <...> vient d’une bibliothèque installée (par PlatformIO). #include "config.h" avec des guillemets veut dire “ce fichier est dans mon propre projet, pas une bibliothèque externe”.

### La structure CanalEtat (lignes 18-29)

struct CanalEtat {
int brutCourant;
float tensionADC_V;
float courant_A;
float puissance_W;
float energie_kWh;
float energie_prev_kWh;
float credit_USD;
bool relaisFerme;
String dernierEvenement;
unsigned long dernierHorodatageMs;
};

C’est la fiche complète d’un seul canal. Chaque champ correspond directement à une colonne du Tableau 3.1/3.2/3.5/3.6 de ton mémoire :

Champ du code | Ce que ça représente
brutCourant | La valeur brute lue sur l’ADC (0 à 4095),
| avant tout calcul
tensionADC_V | Cette valeur brute convertie en volts (0 à
| 3,3V)
courant_A | Le courant calculé en ampères
puissance_W | La puissance calculée en watts
energie_kWh | L’énergie cumulée depuis la dernière
| recharge
energie_prev_kWh | La valeur d’énergie au tour précédent (sert à
| calculer la différence)
credit_USD | Le crédit restant du canal
relaisFerme | true = alimenté, false = coupé
dernierEvenement | Texte : "recharge", "coupure",
| "retablissement", "demarrage"
dernierHorodatageMs | À quel instant (en millisecondes depuis le
| démarrage) le dernier événement a eu lieu

### Les variables globales (lignes 31-37)

static CanalEtat canaux[NUM_CANAUX];

Un tableau de 5 fiches CanalEtat — une par canal. C’est LA donnée centrale de tout le programme : toutes les tâches lisent ou modifient ce tableau.

static int brutTension = 0;
static float tensionSecteur_V = 0.0f;

La lecture brute et la valeur convertie du capteur de tension (un seul, partagé — pas besoin d’un tableau).
static float tarifCourant = TARIF_USD_PAR_KWH;

Le tarif actuel, initialisé à la valeur de config.h mais qui pourrait être modifié plus tard (pas encore fait dans ce firmware).
static SemaphoreHandle_t mutexCanaux;

La “clé unique” expliquée en Partie 3.

static AsyncWebServer server(80);

Crée le serveur web, qui écoutera sur le port 80 (le port standard du web — c’est pour ça qu’on tape juste http://192.168.4.1 sans préciser de numéro de port dans le navigateur).

### Sauvegarde et chargement NVS (lignes 42-66)

static void chargerEtatDepuisNVS() {
Preferences prefs;
for (int i = 0; i < NUM_CANAUX; i++) { char ns[16];
snprintf(ns, sizeof(ns), "canal%d", i);
prefs.begin(ns, true);
canaux[i].credit_USD = prefs.getFloat("credit", CREDIT_INITIAL_USD);

canaux[i].energie_kWh = prefs.getFloat("energie", 0.0f); prefs.end();
}
}

Au démarrage, cette fonction relit dans la mémoire NVS (une petite zone de la puce qui garde ses données même sans électricité) le crédit et l’énergie de chaque canal, pour reprendre exactement où on s’était arrêté avant la dernière coupure de courant — c’est directement lié à ton mémoire §1.5.3 : “les coupures fréquentes justifient une sauvegarde non volatile”.

- char ns[16] : une petite chaîne de caractères (16 cases) pour construire un nom du genre "canal0", "canal1"…
- snprintf(ns, sizeof(ns), "canal%d", i) : écris dans ns le texte “canal” suivi du numéro
i. C’est comme un printf (afficher du texte formaté) mais qui écrit dans une variable au lieu de l’écran.
- prefs.getFloat("credit", CREDIT_INITIAL_USD) : va chercher la valeur stockée sous le nom “credit” ; si elle n’existe pas encore (premier démarrage), utilise CRE-DIT_INITIAL_USD par défaut.

static void sauverCanalDansNVS(int i) { ... }

La fonction inverse : elle écrit le crédit et l’énergie actuels du canal i dans la mémoire NVS.

### Tâche 1 — Acquisition des capteurs (lignes 71-83)

void TacheAcquisitionCapteurs(void *param) {
for (;;) {
if (xSemaphoreTake(mutexCanaux, pdMS_TO_TICKS(50)) == pdTRUE) { for (int i = 0; i < NUM_CANAUX; i++) {
canaux[i].brutCourant = analogRead(PIN_COURANT[i]);
}
xSemaphoreGive(mutexCanaux);
}
brutTension = analogRead(PIN_TENSION); vTaskDelay(pdMS_TO_TICKS(PERIODE_ACQUISITION_MS));
}
}

Cette tâche ne fait qu’une seule chose, en boucle infinie (for(;;)) : - Elle prend la clé du mutex (attend au maximum 50 ms si quelqu’un d’autre l’a déjà) - Elle lit les 5 broches de courant avec analogRead(...) (fonction Arduino standard : lit une tension et la convertit en nombre de 0 à 4095) et range chaque résultat dans canaux[i].brutCourant - Elle rend la clé - Elle lit aussi la tension (en dehors du mutex, car un seul capteur, pas besoin de protection ici) - Elle attend 500 ms (PERIODE_ACQUISITION_MS) avant de recommencer

C’est la tâche la plus prioritaire (priorité 3 dans setup()) car acquérir les mesures régulièrement est le plus critique pour la précision.

### Tâche 2 — Calcul de la puissance (lignes 88-123)

C’est ici que les valeurs brutes deviennent des grandeurs électriques utilisables. Reprenons le calcul principal :

float v = (canaux[i].brutCourant / (float)ADC_RESOLUTION) * ADC_VREF;

Convertit la valeur brute (0-4095) en volts (0-3,3V) : c’est une simple règle de trois. (float)ADC_RESOLUTION force la division à se faire en nombres décimaux (sinon C++ ferait une division entière et perdrait la précision).

float ecart = (v - (ADC_VREF / 2.0f)) / (ADC_VREF / 2.0f);
canaux[i].courant_A = fabsf(ecart) * COURANT_MAX_A;

Le signal simulé est centré sur la moitié de la tension d’alimentation (1,65V), correspondant à 0 A — comme le vrai ACS712 (cf. mémoire §1.3.1). ecart mesure de combien on s’écarte du centre, en proportion (-1 à +1). fabsf(...) = valeur absolue (on ne garde que l’écart, sans signe, car on ne s’intéresse qu’à la magnitude du courant ici). On multiplie ensuite par le courant maximal simulé (20A) pour avoir le résultat en ampères.

canaux[i].puissance_W = tensionSecteur_V * canaux[i].courant_A;

La formule P = V × I directement (cf. mémoire §1.3.3, avec cos(φ) ≈ 1 pour une charge résistive).
float dt_h = (PERIODE_CALCUL_MS / 1000.0f) / 3600.0f;
canaux[i].energie_kWh += (canaux[i].puissance_W / 1000.0f) * dt_h;

dt_h = la durée entre deux calculs, convertie en heures (500 ms → environ 0,000139 heure). += veut dire “ajoute ceci à la valeur actuelle” — on accumule l’énergie petit bout par petit bout, à chaque passage de la boucle, exactement comme le ferait un vrai compteur électrique.

La deuxième partie de la tâche (le Serial.println/Serial.printf) affiche un tableau dans le moniteur série toutes les 2 secondes (PERIODE_AFFICHAGE_MS) — c’est ce tableau que tu lis pour remplir les Tableaux 3.5/3.6 de ton mémoire.

### Tâche 3 — Gestion des crédits (lignes 128-150)

float delta_kWh = canaux[i].energie_kWh - canaux[i].energie_prev_kWh; if (delta_kWh > 0.0f) {
canaux[i].credit_USD -= delta_kWh * tarifCourant;
canaux[i].energie_prev_kWh = canaux[i].energie_kWh;
}

Calcule combien d’énergie a été consommée depuis le dernier passage de cette tâche (delta_kWh), et déduit le coût correspondant du crédit (-= = “soustrait ceci de la valeur actuelle”). On mémorise ensuite la nouvelle valeur d’énergie pour le prochain calcul de différence.

bool doitEtreFerme = canaux[i].credit_USD > 0.0f;
if (doitEtreFerme != canaux[i].relaisFerme) {
canaux[i].relaisFerme = doitEtreFerme;
canaux[i].dernierEvenement = doitEtreFerme ? "retablissement" : "coupure"; canaux[i].dernierHorodatageMs = millis();
}
digitalWrite(PIN_RELAIS[i], canaux[i].relaisFerme ? HIGH : LOW);

Décide si le canal doit être alimenté (credit_USD > 0). != veut dire “est différent de” : si l’état a changé depuis le dernier passage (le canal vient d’être coupé ou vient d’être rétabli), on enregistre l’événement et l’heure. Enfin, digitalWrite(...) allume ou éteint physiquement la broche du relais/LED : HIGH = alimenté, LOW = coupé.

doitEtreFerme ? "retablissement" : "coupure" est un raccourci pour : “si doitEtreFerme est vrai, utilise le texte ‘retablissement’, sinon utilise ‘coupure’ ” — ça s’appelle un opérateur ternaire, c’est juste un if/else compact.

### Tâche 4 — Persistance LittleFS + NVS (lignes 155-181)

for (;;) {
vTaskDelay(pdMS_TO_TICKS(PERIODE_PERSISTANCE_MS));
for (int i = 0; i < NUM_CANAUX; i++) { sauverCanalDansNVS(i);

JsonDocument doc;
doc["canal"] = i;
doc["energie_cumulee_kWh"] = canaux[i].energie_kWh; ...
File f = LittleFS.open(path, "w");
if (f) {
serializeJson(doc, f);
f.close();
}
}
}

Toutes les 5 secondes (PERIODE_PERSISTANCE_MS), cette tâche : 1. Sauvegarde le crédit et l’énergie de chaque canal en NVS (fonction déjà vue plus haut) 2. Construit un petit objet JSON (JsonDocument doc) avec l’historique du canal (format défini en Annexe A.3 de ton mémoire) 3. Ouvre un fichier /canal0.json, /canal1.json, etc. sur LittleFS en écriture ("w"), y écrit le JSON avec serializeJson, puis le ferme

JsonDocument, doc["canal"] = i : ArduinoJson te permet de construire un objet JSON comme un dictionnaire — doc["nom_du_champ"] = valeur. Quand tu appelles serialize-Json(doc, ...), ça transforme cet objet en texte JSON classique, comme {"canal": 0, "energie_cumulee_kWh": 0.002, ...}.

construireJsonEtat() (lignes 187-209)

Cette fonction n’est pas une tâche, c’est une fonction “utilitaire” appelée par la tâche 5 à chaque fois qu’un téléphone demande l’état du système. Elle construit un seul gros JSON avec la tension secteur, le tarif, et un tableau (JsonArray) contenant la fiche complète de chaque canal. C’est exactement le JSON que lit l’application Flutter (api_client.dart, fonction fetchEtat()) et le JavaScript des pages web (app.js, fonction fetchEtat()) — les deux consomment la même source, ce qui garantit qu’ils affichent toujours les mêmes valeurs (cf. mémoire §2.10).

### Tâche 5 — Serveur API (lignes 216-271)

server.on("/api/etat", HTTP_GET, [](AsyncWebServerRequest *request) { request->send(200, "application/json", construireJsonEtat());
});

server.on(chemin, méthode, fonction) : “quand quelqu’un visite cette adresse avec cette méthode HTTP, exécute cette fonction”. Ici : si quelqu’un fait une requête GET sur /api/etat, on répond avec le code 200 (= “tout va bien”, le code HTTP standard de succès) et le JSON de construireJsonEtat().

La partie [](AsyncWebServerRequest *request) { ... } est ce qu’on appelle une fonction lambda : une fonction définie directement sur place, sans lui donner de nom, parce qu’on ne l’utilise qu’à cet endroit. C’est comme écrire “quand ça arrive, fais ceci” directement, plutôt que de devoir écrire une fonction séparée ailleurs et la nommer.

server.on("/api/recharge", HTTP_GET, [](AsyncWebServerRequest *request) {
if (!request->authenticate("bailleur", ADMIN_PASSWORD)) {
return request->requestAuthentication();
}
});

request->authenticate(...) vérifie le mot de passe côté ESP32, pas dans le navigateur — c’est le point de sécurité mentionné en mémoire §2.10 (“jamais en JavaScript”). Si le mot de passe est faux, requestAuthentication() renvoie une demande d’identification au navigateur, et le code s’arrête là (return) sans aller plus loin.

int idx = request->getParam("canal")->value().toInt();
float montant = request->getParam("montant")->value().toFloat();

Récupère les paramètres envoyés dans l’URL (par exemple /api/recharge?canal=1&montant=5) et les convertit en nombre (toInt(), toFloat()) — ils arrivent d’abord sous forme de texte.

La boucle suivante crée dynamiquement les routes /L0, /L1, … /L4 (une par canal), pour que chaque locataire ait sa propre adresse.
server.begin();
for (;;) {
vTaskDelay(pdMS_TO_TICKS(60000));
}

server.begin() démarre vraiment le serveur (une seule fois). Ensuite, cette tâche n’a plus rien à faire activement — le serveur web répond tout seul en arrière-plan dès qu’une requête arrive (c’est ce que veut dire “événementiel” dans le commentaire du code) — donc la tâche se contente d’attendre 60 secondes en boucle, juste pour rester vivante sans consommer de ressources inutilement.

### setup() — ce qui se passe au démarrage (lignes 273-309)

Serial.begin(115200);

Active la communication série (le moniteur série dans VS Code/Wokwi) à 115200 bauds (vitesse de transmission standard pour l’ESP32).
if (!LittleFS.begin(true)) { ... }

Monte le système de fichiers LittleFS. true veut dire “si ça échoue, formate automatiquement”. ! devant veut dire “si ce n’est PAS vrai” — donc ce bloc s’exécute seulement si le montage a échoué.

for (int i = 0; i < NUM_CANAUX; i++) {
pinMode(PIN_RELAIS[i], OUTPUT);
digitalWrite(PIN_RELAIS[i], LOW);
}

Configure chaque broche de relais/LED comme une sortie (OUTPUT, par opposition à une entrée qui lirait un signal), et l’éteint au démarrage par sécurité.

mutexCanaux = xSemaphoreCreateMutex();
chargerEtatDepuisNVS();

Crée la “clé” du mutex, puis recharge le crédit/énergie sauvegardés.

WiFi.softAP(WIFI_SSID, WIFI_PASSWORD);

Démarre le point d’accès Wi-Fi de l’ESP32 (il devient lui-même un routeur Wi-Fi, cf. mémoire
§2.9 — “sans dépendance à une connexion Internet externe”).

xTaskCreatePinnedToCore(TacheAcquisitionCapteurs, "Acquisition", 4096, NULL, 3, NULL, 1);

C’est la ligne qui crée et démarre chaque tâche. Les paramètres, dans l’ordre : 1. Le nom
de la fonction à exécuter en boucle 2. Un nom texte pour la reconnaître dans les outils de debug 3. La taille de la pile mémoire allouée à cette tâche (4096 octets) 4. Un paramètre optionnel passé à la tâche (NULL = aucun ici) 5. La priorité (plus le chiffre est grand, plus la tâche est prioritaire quand plusieurs veulent s’exécuter en même temps) 6. Un identifiant de tâche optionnel (NULL = non utilisé) 7. Le cœur du processeur sur lequel la coincer (0 ou 1 — l’ESP32 en a deux, cf. mémoire §1.4.2)

C’est la traduction directe de l’Annexe A.1 de ton mémoire.

### loop() — la boucle Arduino classique (lignes 311-313)

void loop() {
vTaskDelay(pdMS_TO_TICKS(1000));
}

Sur un programme Arduino simple, tout le travail se ferait ici. Mais comme tout ton travail est déjà fait par les 5 tâches créées dans setup(), loop() n’a plus rien à faire — elle attend juste 1 seconde en boucle, sans jamais s’arrêter (FreeRTOS a besoin qu’elle existe, même vide, car c’est elle-même une tâche cachée créée automatiquement par le framework Arduino).

## Partie 5 — Comment tout s’articule (résumé visuel)

┌─────────────────────────┐
│ | mutexCanaux (la cle) | │
│ | canaux[0..4] (fiches) │
└───────────┬─────────────┘
│
┌────────────────┬──────────┼──────────┬─────────────────┐
│ | | │ | │ | │ | │
▼ | | ▼ | ▼ | ▼ | ▼
Tache 1 | | Tache 2 | Tache 3 | Tache 4 | Tache 5
Acquisition | → | Calcul | → Credits | → Persistance | Serveur API
(lit ADC) | | (P, kWh) | (coupe/ | (NVS + JSON) | (repond aux
retablit) | requetes)
│
| | | | | ▼
| | | | | Flutter (api_client.dart)
| | | | | Pages web (app.js)

Chaque tâche lit et/ou modifie les mêmes fiches canaux[], toujours en passant par le mutex pour ne jamais se marcher dessus. C’est exactement l’architecture décrite au chapitre 2.6 de ton mémoire — ce document ne fait que “dérouler” en langage courant ce que le code fait ligne par ligne.

## Glossaire rapide

Mot | Signification simple
ADC | Convertisseur qui transforme une tension
| (analogique) en nombre (0-4095)
GPIO | Une broche physique de l’ESP32
Tâche (task) | Un mini-programme qui tourne en boucle, en
| parallèle des autres
Mutex | Une clé unique qui empêche deux tâches
| d’écrire en même temps
JSON | Un format texte standard pour échanger des
| données structurées
NVS | Une petite mémoire de la puce qui garde ses
| données sans électricité
LittleFS | Un vrai système de fichiers (comme des
| dossiers/fichiers) sur la puce
Route (server.on) | Une adresse web à laquelle le serveur
| répond (ex : /admin)
Lambda ([](...){...}) | Une fonction écrite directement sur place,
| sans nom
static | La variable garde sa valeur d’un appel de
| fonction à l’autre
const | La valeur ne change jamais après sa création

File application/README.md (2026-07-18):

# tfc_multicanal_app

A new Flutter project.

## Getting Started

This project is a starting point for a Flutter application.

A few resources to get you started if this is your first Flutter project:

- [Learn Flutter](https://docs.flutter.dev/get-started/learn-flutter)
- [Write your first Flutter app](https://docs.flutter.dev/get-started/codelab)
- [Flutter learning resources](https://docs.flutter.dev/reference/learning-resources)

For help getting started with Flutter development, view the
[online documentation](https://docs.flutter.dev/), which offers tutorials,
samples, guidance on mobile development, and a full API reference.

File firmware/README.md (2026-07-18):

# TFC Multicanal - Maquette Wokwi (5 canaux)

Firmware de démonstration correspondant au chapitre 2 du mémoire (architecture
FreeRTOS à 5 tâches, cf. Annexe A) et au chapitre 3, §3.1-3.6 (validation par
simulation Wokwi puis sur maquette physique). Le firmware **compile déjà**
(vérifié avec `pio run`) — il ne reste qu'à le simuler pour obtenir les
chiffres des tableaux 3.1, 3.2 et 3.5.

## Correction apportée par rapport au mémoire : broches GPIO37/GPIO38

Le Tableau 2.2 (et le Tableau 3.4) assignent les canaux 2 et 3 aux broches
**GPIO37** et **GPIO38**. Ces deux broches existent sur la puce ESP32 mais ne
sont **pas sorties sur le connecteur d'un ESP32 DevKitC standard** (ni dans
Wokwi) — ce n'est pas une erreur de câblage, c'est une limitation physique du
connecteur de ce type de carte.

- Sur le **PCB final** (chapitre 2.5, module WROOM-32 nu et non une carte
  DevKitC toute faite), tu peux tout à fait router GPIO37/38 toi-même : le
  Tableau 2.2 n'a pas besoin de changer pour cette partie-là.
- Pour la **maquette breadboard** (§3.6.2, qui utilise un "ESP32 DevKit V1")
  et pour **cette simulation Wokwi**, ces deux broches sont physiquement
  inaccessibles. J'ai donc réaffecté les canaux 2 et 3 aux broches GPIO34 et
  GPIO35 (elles aussi en ADC1, donc sans conflit Wi-Fi, cf. §1.4.3).

Nouveau mapping utilisé ici (à reporter dans le Tableau 3.4 si tu veux que le
mémoire corresponde exactement à cette maquette) :

| Canal | Rôle | Potentiomètre (courant) | LED (sortie) |
|---|---|---|---|
| 0 | Bailleur | GPIO36 (VP) | GPIO4 |
| 1 | Locataire 1 | GPIO39 (VN) | GPIO5 |
| 2 | Locataire 2 | GPIO34 | GPIO13 |
| 3 | Locataire 3 | GPIO35 | GPIO14 |
| 4 | Locataire 4 | GPIO32 | GPIO16 |

Le potentiomètre de tension (ZMPT101B simulé) reste sur GPIO25, inchangé.

## Comment lancer la simulation (VS Code + extension Wokwi)

1. Dans VS Code, installe l'extension **"Wokwi Simulator"** (en plus de
   PlatformIO déjà installé sur cette machine).
2. Ouvre le dossier `tfc-multicanal` dans VS Code.
3. `Ctrl+Shift+P` → **"Wokwi: Start Simulator"** (ou l'icône lecture en haut
   à droite du fichier `diagram.json`). Ça compile automatiquement via
   PlatformIO puis lance la simulation.
4. Ouvre le **moniteur série** intégré à Wokwi (icône dans le panneau de
   simulation) : c'est là que tu liras les valeurs pour les tableaux.

> Remarque : le simulateur Wokwi ne charge pas encore d'image LittleFS (c'est
> une limitation connue de Wokwi, pas un bug de ce firmware). Les pages web
> (`/`, `/admin`, `/L0`...) ne s'afficheront donc pas en simulation, seulement
> sur le vrai ESP32. **Ça n'empêche pas de remplir les tableaux 3.1/3.2**, qui
> se lisent entièrement depuis le moniteur série.

## Remplir le Tableau 3.1 (grandeurs électriques)

Le moniteur série affiche toutes les 2 secondes un tableau comme :

```
--- Canal | V_secteur(V) | I(A) | P(W) | E_cumulee(kWh) | Credit(USD) | Relais ---
0     | 220.50       | 3.120 | 688.29| 0.00191        | 0.0490     | FERME
...
```

Pour chaque canal : clique sur le potentiomètre correspondant dans la vue
Wokwi, fais-le glisser vers une position connue, note la valeur affichée dans
`courant_A`/`I(A)`. Le "courant attendu (calcul théorique)" du Tableau 3.1
est simplement `I = |position_pot - 50%| / 50% x 20 A` (cf. `config.h`,
`COURANT_MAX_A`) — compare-le à la valeur `I(A)` imprimée par le firmware.

## Remplir le Tableau 3.2 (coupure / rétablissement)

Le crédit initial est **volontairement bas** (`CREDIT_INITIAL_USD = 0.05` USD
dans `config.h`) pour que la coupure arrive vite en simulation. Laisse tourner
la simulation quelques dizaines de secondes en écartant un potentiomètre de
courant du centre (donc en simulant une consommation) : tu verras la colonne
`Credit(USD)` descendre puis la colonne `Relais` passer de `FERME` à
`OUVERT`, et la LED correspondante s'éteindre dans la vue Wokwi. C'est
exactement le scénario du Tableau 3.2 — note les instants observés.

## Tableau 3.5 (maquette physique réelle)

Une fois que tu as un vrai ESP32 DevKitC : même firmware, même
`platformio.ini`. Étapes supplémentaires propres au matériel réel :

```bash
pio run --target uploadfs   # copie data/ (pages HTML) sur la puce
pio run --target upload     # flashe le firmware
pio device monitor          # équivalent du moniteur série Wokwi
```

Les pages web (`http://192.168.4.1/`, `/admin`, `/L0`...) fonctionneront
cette fois, contrairement à la simulation Wokwi.

## Identifiants de démonstration

- Wi-Fi : SSID `TFC-Multicanal-Goma`, mot de passe `12345678`
- Admin HTTP (Basic Auth sur `/admin` et `/api/recharge`) : utilisateur
  `bailleur`, mot de passe `bailleur2026`

Ces valeurs sont dans `src/config.h`, à changer avant toute utilisation
au-delà de la démonstration.

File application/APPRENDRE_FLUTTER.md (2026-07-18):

# Apprendre Flutter pour ce projet (depuis zéro)

Tu connais déjà la programmation (C++ Arduino, Python) — ce qui te manque
c'est juste la syntaxe Dart et le modèle "widgets" de Flutter. Ce n'est pas
un framework énorme à maîtriser en entier : ce guide se limite à ce dont
**cette app précise** a besoin, pas à "apprendre Flutter" en général.

**Statut actuel** : l'app compile, passe `flutter analyze` sans erreur, et
`flutter test` passe. Elle a 2 écrans fonctionnels (locataire, admin) qui
consomment déjà `/api/etat` et `/api/recharge` — exactement l'API du
firmware. Ce n'est pas un tutoriel vide : c'est du code qui marche, à lire
et à faire évoluer.

**Important** : c'est un objectif secondaire par rapport au matériel et à la
rédaction (deadline < 1 mois, cf. mémoire §3.5 qui explique déjà que
l'interface web suffit comme preuve de concept). Ne sacrifie pas le
câblage/les mesures physiques pour Flutter. Vois ça comme un bonus si tu as
3-5 jours devant toi après le reste.

## Avant de commencer

Flutter est déjà installé sur cette machine (`~/development/flutter`),
ajouté au PATH (`~/.bashrc`). Le SDK Android est aussi déjà configuré.
Vérifie que tout va bien :

```bash
flutter doctor
```

Pour lancer l'app rapidement (sans émulateur Android, juste pour voir
l'interface tourner) :

```bash
cd ~/Documents/TFC-Multicanal-Goma/application
flutter run -d chrome     # le plus rapide pour tester en developpant
# ou : flutter run -d linux
```

Pour tester "pour de vrai" comme dans le mémoire (§3.5, émulateur Android) :
Android Studio n'est pas installé, mais tu peux créer un émulateur en ligne
de commande, ou plus simple : brancher ton téléphone Android en USB avec le
mode développeur + débogage USB activé, puis `flutter run` détectera le
téléphone directement — plus rapide qu'un émulateur sur cette machine.

## Plan sur 4-5 jours (2-3h/jour)

### Jour 1 — Bases du langage Dart
Dart ressemble à un mélange de Java/C++ et de JavaScript moderne. Fais le
tour officiel (1h30-2h), en pratiquant dans DartPad (aucune install requise,
dans le navigateur) :
- Dart Tour : https://dart.dev/language
- DartPad (bac à sable) : https://dartpad.dev

Concentre-toi sur : variables/types, fonctions, classes, `async`/`await`
et `Future` (c'est l'équivalent direct des callbacks/promesses que tu as
déjà croisés en JS pour l'app web, ou du non-bloquant en C++).

### Jour 2 — Widgets et mise en page
Lis `lib/screens/home_screen.dart` de ce projet ligne par ligne, en
t'aidant du codelab officiel en parallèle :
- Write your first Flutter app : https://docs.flutter.dev/get-started/codelab

Concepts clés à comprendre (déjà utilisés dans le code) :
- `StatelessWidget` vs `StatefulWidget` (= un écran qui ne change jamais vs
  un écran qui doit se redessiner quand une donnée change)
- `setState(() { ... })` = "je viens de changer une valeur, redessine
  l'écran" (équivalent de la mise à jour du DOM après un `fetch()` dans
  `app.js` de l'interface web)
- `Scaffold`, `Column`, `Row`, `Padding` = les briques de mise en page
  (comme des `<div>` avec flexbox en CSS)

Fais des petites modifications toi-même dans `home_screen.dart` (change un
texte, une couleur, ajoute un bouton) et observe le "hot reload" (`r` dans
le terminal `flutter run`, ou sauvegarde dans l'IDE) — c'est la boucle de
développement Flutter, très rapide une fois qu'on l'a en main.

### Jour 3 — Appels HTTP et JSON
Lis `lib/models.dart` et `lib/api_client.dart` : c'est la traduction directe
de ce que fait déjà `app.js` (`fetch("/api/etat")` + `JSON.parse`) mais en
Dart typé. Documentation du package `http` :
- https://pub.dev/packages/http

Exercice concret : lance le firmware (Wokwi ou vrai ESP32), note l'IP, mets
cette IP dans le champ de `HomeScreen`, lance `flutter run -d chrome`, et
vérifie que l'écran locataire affiche les vraies valeurs du firmware.

### Jour 4 — Comprendre `tenant_screen.dart` et `admin_screen.dart`
Ce sont les deux écrans complets. Repère :
- `Timer.periodic` = équivalent de `setInterval()` (rafraîchit toutes les
  2 secondes, comme `app.js`)
- `initState()` / `dispose()` = code qui s'exécute à l'ouverture / à la
  fermeture de l'écran (annuler le Timer dans `dispose()` est important,
  sinon il continue de tourner après avoir quitté l'écran)
- `FutureBuilder` n'est pas utilisé ici (on a préféré `setState` + Timer,
  plus simple à suivre pour un premier projet) — tu peux le découvrir plus
  tard si tu veux une version "plus Flutter idiomatique"

### Jour 5 (optionnel, marge) — Captures d'écran pour le mémoire
Le mémoire a des emplacements réservés `[Insérer ici la maquette de
l'application mobile Flutter...]` (§2.9) et `[Insérer ici une capture
d'écran de l'application mobile Flutter...]` (§3.5). Une fois l'app testée
contre le vrai ESP32 (§3.6), fais ces captures et remplace les placeholders.

## Si tu bloques sur quelque chose de précis

Reviens vers moi avec l'erreur exacte (copie le message du terminal) plutôt
que de chercher à tout comprendre d'un coup — c'est comme ça qu'on avance
vite sur un nouveau langage.

## Ressources de secours (si tu préfères la vidéo)
- Chaîne YouTube officielle Flutter : https://www.youtube.com/@flutterdev
- freeCodeCamp "Flutter Course for Beginners" (gratuit, complet, en anglais)

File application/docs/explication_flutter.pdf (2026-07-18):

# Explication de l’application Flutter — TFC Système Multicanal

### Guide pas-à-pas pour quelqu’un qui ne connaît pas Dart/Flutter

### Document préparé pour Samuel Mumbere Mathe — ULPGL

### Juillet 2026

## Table des matières

Introduction | 1
Partie 1 — Les bases de Dart qu’il faut connaître | 2
Partie 2 — models.dart : la traduction du JSON en objets Dart | 4
Partie 3 — api_client.dart : parler au firmware | 4
Partie 4 — Les écrans | 5
Partie 5 — Comment tout s’articule | 8
Glossaire rapide | 8

## Introduction

Ce document explique le code de l’application mobile (application/lib/), fichier par fichier, sans rien supposer connu en Dart (le langage de Flutter). Comme pour le firmware, l’objectif n’est pas de te transformer en développeur Flutter, mais que tu puisses expliquer devant le jury ce que fait chaque écran et comment l’application parle au firmware.

L’application a 6 fichiers, organisés ainsi :

lib/

├── main.dart | point d'entree de l'application
├── models.dart | les "fiches" de donnees (miroir du JSON du firmware)
├── api_client.dart | les appels reseau vers l'ESP32
└── screens/
├── home_screen.dart | ecran d'accueil (choix locataire/admin)
├── tenant_screen.dart | ecran locataire (lecture seule)
└── admin_screen.dart | ecran bailleur/admin (vue + recharge)

## Partie 1 — Les bases de Dart qu’il faut connaître

### Une variable typée, comme en C++

int canal = 0;
double courant = 3.2;
String role = "locataire";
bool relaisFerme = true;

Même principe qu’en C++ (vu dans le document firmware) : le type est écrit avant le nom. double = nombre décimal (équivalent du float en C++, juste plus précis).

final et const

final veut dire “cette variable ne changera plus une fois remplie” — similaire à const en C++, mais peut être calculée au moment de l’exécution (const en Dart doit être connu à l’avance, avant même de lancer le programme).

final String baseUrl; // rempli une fois, ne change plus

### Les classes

Une classe, c’est la version Dart d’une struct C++, mais en plus complet : elle peut aussi contenir des fonctions (appelées “méthodes”).

class CanalEtat {
final int canal;
final double courantA;

CanalEtat({required this.canal, required this.courantA});
}

CanalEtat({required this.canal, ...}) est le constructeur : la recette pour fabriquer un objet CanalEtat. required veut dire “ce champ est obligatoire à la création”.

async, await, Future

Un appel réseau (demander une page à l’ESP32) prend du temps — l’écran ne doit pas se figer en attendant la réponse. Dart gère ça avec :

- Future<T> : “une valeur de type T qui arrivera plus tard” (le temps que la requête réseau se termine)
- async : marque une fonction comme “contient des opérations qui prennent du temps”
- await : “attends que ce Future soit prêt avant de continuer, mais sans bloquer le reste de l’application pendant ce temps”

Future<EtatSysteme> fetchEtat() async {
final reponse = await http.get(uri); | // attend la reponse du serveur
return EtatSysteme.fromJson(...); | // s'execute apres la reponse
}

C’est l’équivalent direct de fetch(...).then(...) ou async/await en JavaScript, si tu as déjà vu ça dans app.js de l’interface web.

### Le point d’interrogation ? et le point d’exclamation ! (null safety)

Dart oblige à dire explicitement si une variable peut être vide (null, “rien”) ou non :

CanalEtat? _canal; | // peut valoir null (pas encore de donnees recues)
String? _erreur; | // peut valoir null (pas d'erreur actuellement)

Le ? après le type veut dire “cette variable peut être null”. Le ! utilisé plus loin (ex: _erreur!) veut dire “je te garantis que ce n’est pas null ici, fais-moi confiance”. C’est une protection intégrée au langage contre un type d’erreur très fréquent dans d’autres langages (“null pointer exception”).

### L’interpolation de texte $variable

Text("Canal ${c.canal} (${c.role})")

$variable ou ${expression} à l’intérieur d’un texte insère directement la valeur — équivalent des f-strings en Python (f"Canal {c.canal}") ou des template strings en JavaScript (`Canal ${c.canal}`).

Les widgets : StatelessWidget et StatefulWidget

En Flutter, tout ce qui s’affiche à l’écran est un “widget” — un bouton, un texte, une mise en page, un écran entier. Il y a deux familles :

- StatelessWidget : un widget qui ne change jamais après avoir été dessiné (ex : le petit widget _Ligne dans tenant_screen.dart, qui affiche juste un label et une valeur fixes).
- StatefulWidget : un widget qui peut changer en réaction à un événement (une réponse réseau qui arrive, un bouton cliqué…). Il est toujours accompagné d’une classe “State” associée (ex : _HomeScreenState), qui contient les données qui peuvent changer.
class TenantScreen extends StatefulWidget { ... } | // la "coquille"
class _TenantScreenState extends State<TenantScreen> { // les donnees + l'affichage CanalEtat? _canal; // change quand une nouvelle reponse arrive
}

setState(() { ... })

C’est LA instruction centrale de Flutter : elle dit “j’ai changé une donnée, redessine l’écran maintenant”. Sans elle, même si la donnée a changé en mémoire, l’écran resterait affiché tel quel.
setState(() {
_canal = canal; | // change la donnee...
}); | // ...et Flutter redessine automatiquement l'ecran

build(BuildContext context)

Chaque widget a une méthode build qui décrit “à quoi ressemble cet écran, en fonction des données actuelles”. Flutter l’appelle automatiquement à chaque setState. C’est le cœur de chaque fichier d’écran — un grand arbre de widgets imbriqués les uns dans les autres (Scaffold contient Padding, qui contient Column, qui contient des Text, etc.), comme des poupées russes.

## Partie 2 — models.dart : la traduction du JSON en objets Dart

class CanalEtat {
final int canal;
final String role;
final double courantA;
}

Reproduit exactement les champs que le firmware renvoie dans /api/etat (voir document firmware, fonction construireJsonEtat()). Chaque objet CanalEtat = une fiche d’un canal. factory CanalEtat.fromJson(Map<String, dynamic> json) {
return CanalEtat(
canal: json['canal'] as int,
courantA: (json['courant_A'] as num).toDouble(), ...
);
}

Un factory est une façon spéciale de construire un objet. fromJson prend une Map (l’équivalent Dart d’un dictionnaire — ce que devient un objet JSON une fois lu) et va chercher chaque champ par son nom (json['courant_A']) pour remplir un vrai objet CanalEtat typé. as int, as num : convertit/vérifie le type de la valeur lue.

EtatSysteme fait la même chose, mais pour l’objet englobant qui contient la tension secteur, le tarif, et la liste de tous les CanalEtat :
final liste = (json['canaux'] as List)
.map((c) => CanalEtat.fromJson(c as Map<String, dynamic>))
.toList();

.map(...) = “pour chaque élément de la liste, applique cette transformation” — ici, transforme chaque bout de JSON brut en un vrai objet CanalEtat. .toList() referme le résultat en une vraie liste Dart. C’est l’équivalent de .map() en JavaScript, ou d’une compréhension de liste [f(x) for x in liste] en Python.

## Partie 3 — api_client.dart : parler au firmware

class ApiClient {
final String baseUrl;
ApiClient(this.baseUrl);

baseUrl = l’adresse de l’ESP32 (par exemple http://192.168.4.1), donnée à la création de l’objet. ApiClient(this.baseUrl) est un constructeur raccourci : this.baseUrl veut dire

“prends le paramètre reçu et mets-le directement dans le champ baseUrl de l’objet”.

Future<EtatSysteme> fetchEtat() async {
final uri = Uri.parse('$baseUrl/api/etat');
final reponse = await http.get(uri).timeout(const Duration(seconds: 5)); if (reponse.statusCode != 200) {
throw Exception('Erreur serveur : ${reponse.statusCode}');
}
final data = jsonDecode(reponse.body) as Map<String, dynamic>;
return EtatSysteme.fromJson(data);
}
- Uri.parse(...) construit l’adresse complète, ex : http://192.168.4.1/api/etat
- http.get(uri) envoie une requête HTTP GET (comme quand ton navigateur charge une page) — exactement la même requête que fait fetch() dans app.js côté web
- .timeout(...) : abandonne et signale une erreur si l’ESP32 ne répond pas en 5 secondes (évite que l’appli reste bloquée indéfiniment)
- reponse.statusCode != 200 : vérifie que le serveur a bien répondu “succès” (code 200) et pas une erreur
- throw Exception(...) : déclenche une erreur qui sera attrapée plus loin par un bloc try/catch (voir Partie 4)
- jsonDecode(...) transforme le texte JSON reçu en Map, puis EtatSysteme.fromJson(...) la transforme en objet Dart utilisable
Future<void> recharger(int canal, double montant) async {
final uri = Uri.parse('$baseUrl/api/recharge?canal=$canal&montant=$montant'); final reponse = await http.get(uri, headers: _headersAdmin).timeout(...);
}

Même principe, mais pour la recharge : construit l’URL avec les paramètres canal et montant directement dedans (comme dans un navigateur), et ajoute les en-têtes d’authentification :

Map<String, String> get _headersAdmin {
final creds = base64Encode(utf8.encode('$adminUser:$adminPass'));
return {'Authorization': 'Basic $creds'};
}

Ceci construit l’en-tête HTTP d’authentification “Basic Auth” attendu par le firmware (request->authenticate(...) côté ESP32, voir document firmware) : le couple utilisateur/mot de passe est encodé en base64 (un simple encodage de texte, pas un chiffrement) et envoyé dans l’en-tête Authorization.

## Partie 4 — Les écrans

home_screen.dart — l’écran d’accueil

final TextEditingController _baseUrlController =
TextEditingController(text: "http://192.168.4.1");

Un TextEditingController retient ce que l’utilisateur tape dans un champ de texte (ici, l’adresse IP du serveur) et permet de le relire.
Wrap(
children: List.generate(nombreCanaux, (i) {
return OutlinedButton(

onPressed: () { Navigator.push(context, MaterialPageRoute( builder: (_) => TenantScreen(baseUrl: baseUrl, canalIndex: i), )); },
child: Text(i == 0 ? "Canal 0 (bailleur)" : "Canal $i"),
);
}),
)

List.generate(5, (i) => ...) crée 5 boutons d’un coup (un par canal), sans les écrire à la main un par un — équivalent d’une boucle for qui construirait une liste.

Navigator.push(context, MaterialPageRoute(builder: (_) => TenantScreen(...))) c’est la navigation entre écrans en Flutter. Navigator.push empile un nouvel écran par-dessus l’actuel (comme ouvrir une nouvelle page — et il y a un bouton retour automatique). MaterialPageRoute(builder: ...) décrit quel écran construire (ici, TenantScreen, en lui passant l’IP du serveur et le numéro du canal choisi).

tenant_screen.dart — l’écran locataire

@override
void initState() {
super.initState();
_api = ApiClient(widget.baseUrl);
_rafraichir();
_timer = Timer.periodic(const Duration(seconds: 2), (_) => _rafraichir());
}

initState() s’exécute une seule fois, quand l’écran s’ouvre. Ici : crée le client API, va chercher les données une première fois (_rafraichir()), puis programme un rafraîchissement automatique toutes les 2 secondes avec Timer.periodic — l’équivalent Dart de setInterval() en JavaScript.
@override
void dispose() {
_timer?.cancel();
super.dispose();
}

dispose() s’exécute quand l’écran se ferme. _timer?.cancel() : ?. veut dire “si _timer n’est pas null, appelle .cancel() dessus” — arrête le rafraîchissement automatique pour ne pas continuer à faire des requêtes réseau inutiles une fois l’écran quitté (ça gaspillerait de la batterie et des ressources).
Future<void> _rafraichir() async {
try {
final etat = await _api.fetchEtat();
final canal = etat.canaux.firstWhere((c) => c.canal == widget.canalIndex); if (!mounted) return;
setState(() { _canal = canal; _erreur = null; });
} catch (e) {
if (!mounted) return;
setState(() => _erreur = "Connexion impossible : $e"); }
}

- try { ... } catch (e) { ... } : “essaie ce bloc ; s’il y a une erreur, exécute plutôt le bloc catch au lieu de planter l’application” — indispensable pour le réseau, qui peut échouer à tout moment (Wi-Fi hors de portée, ESP32 éteint…)
- .firstWhere((c) => c.canal == widget.canalIndex) : “trouve, dans la liste de tous les canaux reçus, celui dont le numéro correspond à l’écran actuel”
- if (!mounted) return; : vérifie que l’écran est toujours affiché avant de le mettre à jour (si l’utilisateur a déjà quitté l’écran pendant que la requête réseau était en cours, on ne fait rien — sinon Flutter afficherait une erreur)

Le build() de cet écran utilise un opérateur ternaire imbriqué (déjà vu en C++ : condition ? siVrai : siFaux) pour choisir entre trois affichages : message d’erreur, roue de chargement (CircularProgressIndicator), ou les vraies données.

### admin_screen.dart — l’écran bailleur/admin

Même structure que tenant_screen.dart (initState, Timer.periodic, _rafraichir), avec en plus le formulaire de recharge :
Future<void> _envoyerRecharge() async {
final montant = double.tryParse(_montantController.text);
if (montant == null || montant <= 0) return;
try {
await _api.recharger(_canalSelectionne, montant); _montantController.clear();
await _rafraichir();
} catch (e) { ... }
}

double.tryParse(texte) essaie de convertir le texte tapé en nombre ; il rend null si ce n’est pas un nombre valide (au lieu de planter). On vérifie ensuite que le montant est positif avant d’envoyer la recharge. Après succès, _montantController.clear() vide le champ de texte, et _rafraichir() recharge immédiatement les données affichées (au lieu d’attendre le prochain passage automatique du Timer).
ScaffoldMessenger.of(context).showSnackBar(
const SnackBar(content: Text("Recharge enregistree")),
);

Affiche un petit message temporaire en bas de l’écran (une “snackbar”) — la confirmation visuelle que la recharge a bien été prise en compte.

...etat.canaux.map(_carteCanal),

... (spread operator) : “insère chaque élément de cette liste directement ici, plutôt que la liste elle-même” — nécessaire car ListView attend une liste de widgets, et .map(_carteCanal) produit justement une carte par canal (fonction définie plus bas dans le même fichier).

### main.dart — le point de départ

void main() {
runApp(const TfcApp());
}

class TfcApp extends StatelessWidget { @override

Widget build(BuildContext context) {
return MaterialApp(
title: 'TFC Multicanal',
theme: ThemeData(colorScheme: ColorScheme.fromSeed(seedColor: Colors.blue)), home: const HomeScreen(),
);
}
}

main() est la toute première fonction exécutée (comme setup() côté firmware, mais pour l’application). runApp(...) démarre Flutter avec le widget racine TfcApp. MaterialApp configure les réglages globaux (thème de couleurs, titre) et indique que le premier écran affiché (home) est HomeScreen.

## Partie 5 — Comment tout s’articule

main.dart
│ lance TfcApp -> HomeScreen
▼
HomeScreen ──────────────┬───────────────────┐
(saisie IP du serveur) | │ | │
▼ | ▼
TenantScreen | AdminScreen
(lecture seule) | (lecture + recharge)
│ | │
| | └─────────┬──────────┘
▼
api_client.dart
(fetchEtat / recharger)
│
▼ | requetes HTTP
| | ESP32 : /api/etat, /api/recharge
│
▼
models.dart
(transforme le JSON en objets Dart)
│
▼
affichage via setState() + build() Chaque écran (Tenant/Admin) suit le même cycle : initState() lance un Timer qui rappelle _rafraichir() toutes les 2 secondes ; _rafraichir() appelle api_client.dart ; la réponse JSON est transformée en objets par models.dart ; setState() déclenche le redessin de l’écran avec les nouvelles valeurs.

## Glossaire rapide

Mot | Signification simple
Widget | Tout élément affiché à l’écran (bouton, texte, écran entier)

Mot | Signification simple
StatelessWidget | Un widget qui ne change jamais après
| affichage
StatefulWidget | Un widget qui peut changer (et se
| redessiner)
setState(...) | “J’ai changé une donnée, redessine l’écran”
build(...) | La méthode qui décrit à quoi ressemble un
| widget
Future<T> | Une valeur de type T qui arrivera plus tard
| (opération asynchrone)
async / await | Marque et attend une opération qui prend du
| temps (réseau…)
Map<String, dynamic> | L’équivalent Dart d’un dictionnaire (issu d’un
| JSON)
factory | Une façon spéciale de construire un objet
Navigator.push(...) | Ouvre un nouvel écran par-dessus l’actuel
Timer.periodic(...) | Répète une action toutes les X secondes
try / catch | Essaie un bloc, récupère l’erreur si ça
| échoue au lieu de planter
? après un type | Cette variable peut être vide (null)
$variable dans un texte | Insère la valeur directement dans le texte
| affiché

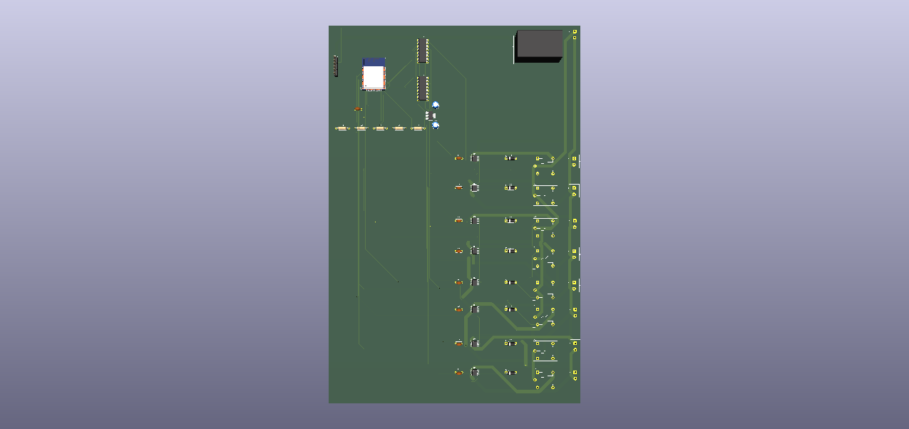
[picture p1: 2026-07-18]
kicad/multical/multical.png

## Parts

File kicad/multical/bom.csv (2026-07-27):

Références | Valeur | Empreinte | Qté
C1-C9 | C | Capacitor_THT:C_Disc_D5.0mm_W2.5mm_P5.00mm | 9
C10,C11 | C | Capacitor_THT:CP_Radial_D5.0mm_P2.00mm | 2
D1-D8 | D | Diode_THT:D_DO-41_SOD81_P7.62mm_Horizontal | 8
J10-J17 | Screw_Terminal_01x02 | TerminalBlock:TerminalBlock_MaiXu_MX126-5.0-02P_1x02_P5.00mm | 8
J18 | Screw_Terminal_01x02 | TerminalBlock_MaiXu_MX126-5.0-02P_1x02_P5.00mm | 1
K1-K8 | Relay_SPDT | Relay_THT:Relay_SPDT_Hongfa_JQC-3FF_0XX-1Z | 8
R1-R5 | R | Resistor_THT:R_Axial_DIN0207_L6.3mm_D2.5mm_P10.16mm_Horizontal | 5
U1 | ESP32-WROOM-32 | RF_Module:ESP32-WROOM-32 | 1
U2-U9 | ACS712xLCTR-20A | Package_SO:SOIC-8_3.9x4.9mm_P1.27mm | 8
U10 | HLK-PM01 | Converter_ACDC:Converter_ACDC_Hi-Link_HLK-PMxx | 1
U11 | AMS1117-3.3 | Package_TO_SOT_SMD:SOT-223-3_TabPin2 | 1
U12 | zmpt101b | Connector_PinHeader_2.54mm:PinHeader_1x06_P2.54mm_Vertical | 1
U13,U14 | ULN2003A | Package_DIP:DIP-16_W7.62mm | 2

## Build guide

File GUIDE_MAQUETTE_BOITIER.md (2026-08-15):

# Guide — Câblage et boîtier de la maquette (sur carte perforée)

Objectif : assembler la maquette (ESP32 + 6 potentiomètres + 5 LED) en
soudant sur une carte perforée à trous isolés (perfboard), puis la loger
dans un boîtier en bois — solide et présentable pour la soutenance.

**Carte perforée à trous isolés** : contrairement à une carte à bandes
(stripboard/veroboard), chaque trou est indépendant — aucune connexion
n'existe entre les trous au départ. Tout ce qui doit être relié (les bus
3V3 et GND en particulier) doit être ponté toi-même, avec un fil ou une
goutte de soudure entre pastilles voisines. C'est plus de travail qu'une
carte à bandes, mais plus flexible : aucun risque de connexion parasite
entre deux pastilles qui ne devraient pas être reliées.

## 1. Liste des composants (devis)

| Composant | Quantité | Valeur / précision |
|---|---|---|
| Carte perforée (perfboard) | 1 | trous isolés, pas 2,54 mm, assez grande pour les 2 barrettes ESP32 + bus 3V3/GND |
| Potentiomètres | 6 | 10 kΩ, linéaire (5 courant + 1 tension commune) |
| Résistances | 5 | 220 à 330 Ω, ¼ W (une par LED) |
| LED | 5 | 5 mm (ou 3 mm selon disponibilité) |
| Barrette(s) femelle | 2 x 19 broches | pas 2,54 mm — pour enficher l'ESP32 sans le souder |
| Fil de câblage | selon besoin | souple/multibrin, fin (~AWG24-26) |
| Gaine thermo ou scotch électrique | selon besoin | isoler chaque soudure |
| Colle chaude | un peu | strain relief + fixation dans le boîtier |

Alimentation : **3,3V via le port USB de l'ESP32** (régulateur embarqué sur
la carte) — pas d'alimentation externe nécessaire, la consommation totale
(≈30-35 mA) est très en dessous de ce que le régulateur peut fournir.

## 2. Monter l'ESP32 sans le souder

Coupe ta barrette femelle en deux morceaux de 19 broches (l'ESP32 DevKit a
deux rangées séparées par l'espace occupé par la puce/le port USB — une
seule barrette continue de 38 ne peut pas être utilisée telle quelle).

Positionne les deux morceaux sur la carte perforée, à l'écartement exact
des deux rangées de pattes de l'ESP32 (vérifie avec l'ESP32 lui-même
avant de souder quoi que ce soit). **Soude chaque broche des barrettes
dans son trou**, côté cuivre — c'est ce qui ancre les barrettes à la
carte. Une fois les barrettes fixées et le câblage terminé, enfiche
l'ESP32 dedans : il n'est jamais soudé directement, tu peux le retirer
pour le reprogrammer ou le remplacer sans tout dessouder.

Vérifie l'écartement des deux barrettes par rapport à la grille de la
carte perforée : selon le pas de ta carte (normalement 2,54 mm comme les
barrettes), les deux rangées de trous où elles doivent aller ne
correspondent pas toujours pile à l'écartement réel de l'ESP32. Pose
l'ESP32 à plat sur la carte avant de souder pour repérer où percer/souder
exactement.

## 3. Schéma de câblage

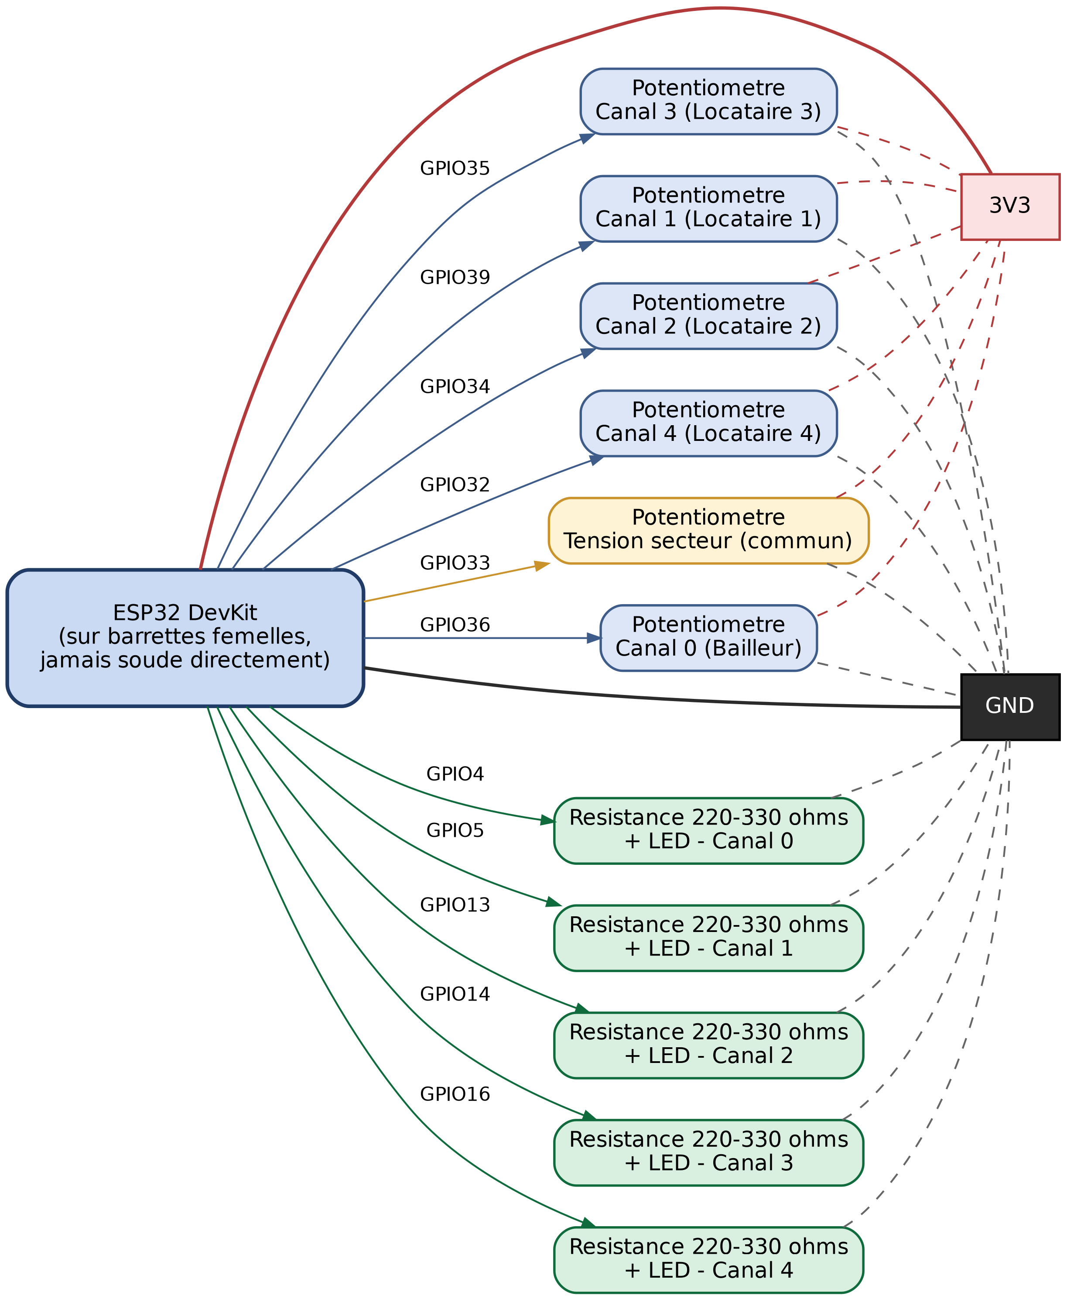
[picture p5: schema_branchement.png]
Schema de branchement


| Canal | Potentiomètre → broche | LED (avec résistance) → broche |
|---|---|---|
| 0 (bailleur) | GPIO36 | GPIO4 |
| 1 (locataire 1) | GPIO39 | GPIO5 |
| 2 (locataire 2) | GPIO34 | GPIO13 |
| 3 (locataire 3) | GPIO35 | GPIO14 |
| 4 (locataire 4) | GPIO32 | GPIO16 |
| Tension secteur (commun, 1 seul potentiomètre) | **GPIO33** | — |

**Important** : le potentiomètre de tension doit être sur GPIO33 (ADC1), pas
GPIO25 — GPIO25 est sur l'ADC2, inutilisable en continu dès que le point
d'accès Wi-Fi de la maquette est actif, ce qui bloque la lecture de tension
(et donc puissance/énergie/crédit, qui en dépendent).

- Potentiomètre : pattes extérieures sur **3V3** et **GND**, curseur (broche
  du milieu) sur la broche GPIO indiquée
- LED : anode (patte longue) vers la broche GPIO **à travers la résistance
  220-330Ω**, cathode (patte courte, méplat sur le boîtier) vers **GND**

## 4. Méthode de soudure sur carte perforée

- **Un canal à la fois** : câble et teste le canal 0 en entier avant de
  passer au canal 1. Plus facile de repérer une erreur sur un seul canal
  que sur cinq à la fois.
- **Construis d'abord les bus 3V3 et GND** : choisis une ligne de trous
  le long d'un bord de la carte pour le 3V3, une autre pour le GND.
  Comme les trous sont isolés, relie-les entre eux toi-même — soit avec
  un bout de fil rigide (une chute de patte de résistance dénudée fait
  très bien l'affaire) soudé d'un trou à l'autre en ligne, soit avec une
  goutte de soudure entre deux pastilles voisines si elles se touchent
  presque. Vérifie au multimètre (mode continuité) que toute la ligne est
  bien reliée d'un bout à l'autre avant de brancher quoi que ce soit
  dessus.
- **Une fois les bus faits**, chaque composant (potentiomètre, LED,
  résistance, broche ESP32) se raccorde par un fil court vers le bus
  concerné, ou directement de trou à trou pour les connexions signal
  (curseur de potentiomètre → GPIO, etc.).
- **Isole quand même chaque soudure** côté cuivre (gaine thermo ou
  vernis/scotch électrique) — une carte perforée réduit le risque de
  court-circuit accidentel par rapport au point-à-point dans le vide,
  mais des rognures de fil qui traînent entre deux pastilles voisines
  restent possibles.
- **Un peu de mou sur chaque fil** qui sort vers les potentiomètres/LED
  du panneau (ne tire pas les fils bien droits) et un point de colle
  chaude à la base de chaque soudure pour la protéger si le fil bouge.
- **Étiquette chaque fil** (scotch + numéro de canal) au fur et à mesure,
  pas à la fin.

## 5. Le boîtier en bois

**Dimensions** : prévois large — la contrainte principale est la hauteur de
l'ESP32 monté sur ses barrettes (~2,5 cm) et l'accès USB. Une boîte
15x10x5cm est confortable.

**Panneau avant** (celui que le jury regarde) :
- 5 trous pour les axes de potentiomètre (Ø ~7mm selon le modèle)
- 5 trous pour les LED (Ø ~5mm, ou 3mm selon la taille de tes LED)
- **Étiquette au-dessus de chaque paire** : « Bailleur », « Locataire 1 »,
  « Locataire 2 », « Locataire 3 », « Locataire 4 » — au feutre fin, à la
  pyrogravure si tu as l'outil, ou étiquette imprimée collée

**Panneau arrière ou latéral** :
- Une découpe pour le port USB de l'ESP32 (accès direct au câble sans
  ouvrir la boîte)

**Fixation interne** :
- Fixe le montage soudé avec des points de colle chaude aux coins/points
  d'ancrage (assez solide pour une maquette, facile à décoller si besoin
  de réparer)
- Ne colle/visse les potentiomètres et LED sur le panneau qu'**après**
  avoir vérifié que tout fonctionne

## 6. Ordre de travail recommandé

1. Coupe et prépare les barrettes femelles (2 x 19 broches), soude-les
   sur la carte perforée, puis construis les bus 3V3 et GND (teste au
   multimètre avant de continuer)
2. Câble un canal complet, teste-le (flash déjà fait sur l'ESP32)
3. Répète pour les canaux 1 à 4, puis le potentiomètre de tension
4. Perce le panneau avant du boîtier (mesure deux fois, perce une fois)
5. Monte potentiomètres et LED sur le panneau, relie-les avec des fils
   assez longs pour pouvoir sortir le panneau si besoin
6. Reteste tout **avant** de refermer définitivement la boîte
7. Ajoute les étiquettes
8. Referme, fais un dernier test complet (flash + Wi-Fi + appli) une fois
   la boîte assemblée

---

Si tu bloques sur une étape demande-moi avant de souder ou de percer — plus
facile de corriger un plan qu'une soudure déjà faite ou un trou dans le bois.

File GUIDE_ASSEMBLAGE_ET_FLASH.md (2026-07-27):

# Guide — De la réception des composants au premier flashage de l'ESP32

Ce guide couvre trois étapes : vérifier les composants à leur arrivée, les
souder correctement, puis téléverser le firmware sur l'ESP32 et vérifier
que tout fonctionne. À suivre dans cet ordre.

## 1. À la réception des composants

- Coche chaque référence contre la nomenclature (Tableau 2.3 du mémoire,
  ou `kicad/multical/bom.csv` si tu veux la liste brute).
- Vérifie visuellement : rien de plié, de cassé, ou qui a l'air corrodé.
- Vérifie les valeurs marquées sur les composants (résistances 10kΩ,
  condensateurs 0,1µF pour C1-C9, 10-22µF pour C10/C11) — une erreur de
  valeur à cette étape est bien plus facile à corriger qu'une fois soudée.
- Range les composants par canal (ACS712 + condensateur + diode + relais
  + bornier) si tu assembles à la main, ça évite les erreurs de câblage.

## 2. Assemblage (soudure)

**Ordre recommandé** (du plus plat au plus haut, pour pouvoir poser la
carte à plat sur la table à chaque étape) :

1. Résistances (R1-R5), diodes (D1-D8) — attention au sens des diodes
   (bande = cathode, cf. discussion sur le montage roue libre)
2. Circuits intégrés : ULN2003A (U13, U14), régulateur AMS1117 (U11)
3. Capteurs ACS712 (U2-U9) — CMS, soudure plus délicate, prends ton temps
4. Condensateurs — attention à la polarité des C10/C11 (électrolytiques,
   patte longue = +)
5. ESP32 (U1), HLK-PM01 (U10)
6. En dernier : relais (K1-K8), borniers à vis (J10-J18) — ce sont les
   plus hauts/gros, plus faciles à souder sans gêner l'accès aux autres

**Précautions** :

- Fer à souder autour de 350°C, pas plus — les CMS (ACS712) chauffent vite.
- Ne reste pas plus de 2-3 secondes sur une même pastille.
- Après chaque composant : inspecte à l'œil (ou à la loupe) qu'il n'y a
  pas de pont de soudure entre deux pastilles voisines, surtout sur les
  ACS712 (pastilles à 1,27mm d'écart, très serrées).

## 3. Vérifications AVANT toute mise sous tension

Avec un multimètre en mode continuité (bip sonore), **avant de brancher
quoi que ce soit** :

- Teste entre `P5V` et `GND` → ne doit **pas** biper (sinon court-circuit
  quelque part, à chercher avant d'aller plus loin)
- Teste entre `PHASE_BUS` et `NEUTRE_BUS` → ne doit pas biper non plus
- Revérifie une dernière fois le sens des composants polarisés (diodes,
  condensateurs électrolytiques, relais)

## 4. Première mise sous tension — SANS le secteur

Ne branche **pas** le 220V à cette étape.

1. Alimente la carte en 5V uniquement (via le port USB de l'ESP32, ou une
   alimentation externe basse tension raccordée après le HLK-PM01)
2. Mesure la sortie de l'AMS1117 (broche VO, U11) → doit indiquer ~3,3V
3. Vérifie que l'ESP32 démarre normalement (pas de redémarrage en boucle)

Si tout est correct, tu peux passer au flashage. Sinon, coupe
l'alimentation et cherche l'erreur avant de continuer.

## 5. Téléverser le firmware sur l'ESP32

PlatformIO est déjà installé sur cette machine. Deux choses à envoyer sur
l'ESP32, dans cet ordre : **le firmware** (le code) et **le système de
fichiers LittleFS** (les pages web `admin.html`, `locataire.html`, etc.
utilisées par l'interface embarquée §2.10 du mémoire) — ce sont deux
étapes séparées, il ne faut pas oublier la seconde.

```bash
cd ~/Documents/TFC-Multicanal-Goma/firmware

# 1) Branche l'ESP32 en USB, puis vérifie qu'il est détecté :
ls /dev/ttyUSB* /dev/ttyACM* 2>/dev/null

# 2) Téléverse le firmware (le code C++) :
pio run --target upload

# 3) Téléverse le système de fichiers (les pages web) :
pio run --target uploadfs

# 4) Ouvre le moniteur série pour voir ce que fait l'ESP32 :
pio device monitor
```

**Si l'upload échoue** (erreur de type "Failed to connect") : certains
modules ESP32 nus (pas les cartes DevKit) n'ont pas l'auto-reset —
maintiens le bouton **BOOT** appuyé pendant les 2-3 premières secondes de
l'upload, relâche quand ça commence à écrire ("Writing at...").

**Pour quitter le moniteur série** : `Ctrl+C`.

## 6. Après le premier flash — vérifications

Dans les logs du moniteur série, tu dois voir apparaître (dans cet
ordre à peu près) :
- Le montage du système de fichiers LittleFS (sans erreur)
- Le démarrage des 5 tâches FreeRTOS (Acquisition, Calcul, Crédits,
  Persistance, ServeurAPI)
- Le point d'accès Wi-Fi qui s'active, avec son nom (SSID) affiché

Ensuite :
1. Depuis ton téléphone/PC, connecte-toi au Wi-Fi diffusé par l'ESP32
2. Ouvre un navigateur, va sur `http://192.168.4.1` (adresse par défaut
   d'un point d'accès ESP32) → tu dois voir la page d'accueil
3. Teste `/admin` (mot de passe défini dans `config.h`) et l'espace
   locataire
4. Installe l'APK Flutter déjà compilé sur ton téléphone, connecte-le au
   même Wi-Fi, vérifie qu'il affiche bien les données

## 7. Seulement après tout ça : test avec le secteur 220V

- **Coupe toujours le disjoncteur** avant de toucher au câblage secteur
- Ne touche jamais les borniers phase/neutre sous tension
- Teste **un seul canal à la fois** la première fois, avec une charge
  simple (une lampe) avant de brancher un vrai sous-compteur
- Vérifie la coupure automatique et le rétablissement après recharge
  (même protocole que le Tableau 3.6 du mémoire, mais en conditions
  réelles cette fois)

---

Si un problème survient à une étape, arrête-toi et redemande-moi avant de
continuer — plus facile de corriger avant l'étape suivante qu'après.

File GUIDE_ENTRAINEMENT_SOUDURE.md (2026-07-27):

# Guide d'entraînement — Bien souder

Ce guide est fait pour progresser par exercices courts, pas juste "souder
au hasard". Fais chaque exercice dans l'ordre, sur des composants de
récupération (pas ceux de ta maquette), avant de passer au suivant.

## Matériel nécessaire

- Fer à souder (température réglable si possible, sinon un fer simple
  fonctionne aussi avec un peu plus de patience)
- Fil de soudure (idéalement avec âme de flux à l'intérieur — c'est écrit
  sur la bobine, "flux core" ou "rosin core")
- Éponge humide ou laine de laiton (pour nettoyer la panne)
- Quelques résistances, fils, et une petite plaque à trous de
  récupération pour t'entraîner — pas tes composants de projet
- Une pince fine (pour tenir les petites pièces)

## Avant de commencer : prépare le fer

1. Allume le fer, laisse-le chauffer 2-3 minutes
2. Nettoie la panne sur l'éponge humide (ou la laine de laiton)
3. **Étame la panne** : dépose un petit filet de soudure directement
   dessus, essuie l'excédent. La panne doit être brillante, pas noire.
   Répète ce nettoyage régulièrement pendant que tu travailles.

## La technique correcte

1. Positionne le fer pour toucher **à la fois** la patte du composant et
   la pastille/le fil sur lequel tu soudes — jamais l'un sans l'autre
2. Compte 1 à 2 secondes pour que **le joint** (pas le fer) devienne assez
   chaud
3. Apporte le fil de soudure directement sur le joint chauffé (pas sur la
   panne du fer) — la chaleur du joint doit faire fondre la soudure
4. Dès qu'un petit cône brillant s'est formé autour du joint, retire
   d'abord la soudure, puis le fer
5. Ne bouge rien pendant 2-3 secondes le temps que ça refroidisse

**Règle des 3 secondes** : ne reste jamais plus de 3 secondes sur un même
joint. Si ce n'est pas assez chaud après 3 secondes, retire le fer,
laisse refroidir un peu, renettoie la panne, réessaie — plutôt que de
insister et cuire le composant.

## Exercice 1 — Contrôle de la chaleur (fils seuls)

Prends deux bouts de fil électrique dénudés, torsade-les ensemble à la
main, puis soude la torsade.

- **Objectif** : obtenir un joint brillant et lisse, pas granuleux
- Recommence 5 fois avec 5 torsades différentes
- Auto-évaluation après chaque essai : brillant et lisse = réussi ;
  terne/granuleux = raté, regarde le tableau de dépannage plus bas

## Exercice 2 — Composants sur plaque à trous

Sur une plaque à trous de récupération, soude 5 résistances, une par une.

- Insère la résistance, plie légèrement les pattes côté opposé pour
  qu'elle ne tombe pas
- Soude chaque patte (2 par résistance = 10 joints au total)
- **Objectif** : 10 joints propres d'affilée, pas juste 1 ou 2 réussis
  par hasard

## Exercice 3 — Composant sensible à la chaleur (LED)

Les LED n'aiment pas la chaleur prolongée — c'est un bon test de vitesse
et de précision.

- Soude une LED sur la plaque (2 pattes)
- Respecte la règle des 3 secondes strictement ici
- Si la LED grille ou change de couleur légèrement après soudure, tu es
  resté trop longtemps — recommence avec une autre LED en étant plus
  rapide

## Exercice 4 — Dessouder (compétence sous-estimée)

Utile pour corriger tes erreurs sans tout jeter.

- Reprends une résistance déjà soudée à l'exercice 2
- Fais fondre la soudure existante avec le fer, puis retire le composant
  à la pince pendant que c'est encore liquide (ou utilise une pompe à
  dessouder / tresse à dessouder si tu en as une)
- **Objectif** : retirer le composant sans arracher la pastille de la
  plaque

## Tableau de dépannage — reconnaître et corriger tes joints

| Aspect du joint | Cause probable | Correction |
|---|---|---|
| Terne, gris, granuleux | Soudure froide : pas assez chaud, ou bougé trop tôt | Rechauffe le joint, refais fondre, ne bouge plus pendant le refroidissement |
| Boule qui ne colle pas | Tu as fait fondre la soudure sur le fer, pas sur le joint | Apporte la soudure directement sur le joint chauffé, pas sur la panne |
| Trop de soudure, aspect de tas | Trop de fil apporté, ou pas assez chaud pour que ça coule bien | Utilise moins de soudure, vérifie que le joint est bien chaud avant d'apporter le fil |
| Pastille qui se décolle de la plaque | Trop de chaleur trop longtemps au même endroit | Respecte la règle des 3 secondes, laisse refroidir entre deux essais |
| Bon joint | Brillant, lisse, petit cône net | — rien à corriger, continue comme ça |

## Quand tu es prêt pour la vraie maquette

Passe à l'exercice suivant seulement quand tu obtiens des joints propres
de façon répétée (pas juste une fois sur deux). Une fois à l'aise, reprends
le `GUIDE_MAQUETTE_BOITIER.pdf` pour souder le vrai circuit — tu auras
beaucoup moins de mauvaises surprises.

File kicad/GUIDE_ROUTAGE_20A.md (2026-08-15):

# Guide — Terminer le routage 20 A par canal

Objectif : finir de router `multical.kicad_pcb` après la révision pour
20 A par canal (2 oz de cuivre, pistes 6,5 mm, carte agrandie à
236 x 461,5 mm). L'essentiel du travail a déjà été fait automatiquement
(repositionnement des 8 grappes de canaux, agrandissement de la carte,
cuivre 2 oz déclaré) ; il reste **15 connexions non conformes sur plus de
200** à router à la main dans l'interface graphique de KiCad — beaucoup
plus rapide et fiable que de batailler avec l'automatisation en ligne de
commande.

**État au 11 août** : `multical.kicad_pcb` est dans un état sûr et vérifié
par DRC (aucune régression), mais avec l'ancien routage 2,5 mm / 1 oz
encore en place partout. Les fichiers de sauvegarde
`multical.kicad_pcb.before-20A.bak` et `multical.kicad_pcb.before-replan.bak`
(dans le même dossier) permettent de revenir en arrière à tout moment si
besoin — n'y touche pas, ce sont des filets de sécurité.

## 0. Lancer KiCad

Utilise la flatpak (10.0.4, pas la snap 9.0.7 périmée) :

```bash
flatpak run org.kicad.KiCad
```

Ouvre le projet `multical.kicad_pro` (dossier
`kicad/multical/`), puis double-clique sur **PCB Editor**.

## 1. Vérifier l'état actuel

1. **Inspecter → Vérification des règles de conception (DRC)** → lance-le.
   Tu dois voir uniquement les 12 erreurs `drill_out_of_range` déjà
   connues (perçage 0,2 mm au lieu de 0,3 mm sur des pastilles GND de
   U1) — rien de plus grave. Si tu vois des courts-circuits, arrête-toi
   et reviens à `multical.kicad_pcb.before-replan.bak`.
2. Regarde le chevelu (ratsnest) : les lignes blanches fines qui
   traversent la carte sont les connexions pas encore routées. Vu le
   nombre (~15), elles devraient être concentrées près des canaux les
   plus serrés (regarde en particulier les canaux 5 à 8, en bas de la
   carte, qui ont été les plus difficiles à router lors du test
   automatique).

## 2. Router avec Freerouting (en mode graphique, pas en ligne de commande)

Le mode CLI de Freerouting utilisé pour la tentative automatique n'a pas
de bouton "sauvegarder" fiable une fois lancé sans interface — le mode
graphique n'a pas ce problème : tu vois la progression et tu cliques
"stop" puis "sauvegarder" quand tu es content du résultat.

1. Dans KiCad PCB Editor : **Fichier → Exporter → Spécification Specctra
   (.dsn)**. Sauvegarde-le à côté du projet, par exemple
   `multical.dsn`.
2. Lance Freerouting en mode graphique (double-clique sur le fichier
   `.jar`, ou en terminal) :
   ```bash
   java -jar kicad/tools/freerouting-2.1.0.jar
   ```
3. Dans la fenêtre Freerouting : **File → Open** → sélectionne ton
   `multical.dsn`.
4. Avant de lancer l'auto-routeur, vérifie les règles des nets de
   puissance : les 18 nets `CANAL1_HT` à `CANAL8_OUT` doivent être en
   classe **CANAL_20A** (largeur 6,5 mm, dégagement 3 mm), et
   `PHASE_BUS` / `NEUTRE_BUS` en classe **BUS_ENTREE** (largeur 10 mm,
   dégagement 3 mm) — ces classes ont déjà été injectées dans le
   fichier `.dsn` si tu es reparti d'un export frais généré après le
   script `kicad/tools/fix_dsn_widths_20A.py` ; sinon relance ce script
   sur ton `.dsn` avant de l'ouvrir dans Freerouting :
   ```bash
   python3 kicad/tools/fix_dsn_widths_20A.py
   ```
5. Clique sur **Autoroute** (bouton play). Laisse tourner — ça se
   stabilise généralement en 1 à 2 minutes à ~15 connexions non
   routées et n'ira probablement pas plus loin tout seul (les 15
   restantes sont les endroits où la carte est encore trop dense pour
   la nouvelle largeur de piste).
6. Clique sur **Stop** une fois que le compteur de connexions non
   routées ne bouge plus.

## 3. Router les 15 dernières connexions à la main

Pour celles que l'auto-routeur n'a pas réussi à placer :

1. Reste dans Freerouting (ou repasse par KiCad si tu préfères router à
   la main dans le PCB Editor directement, avec la touche **X** pour
   démarrer une piste).
2. Zoome sur chaque connexion non routée (surlignée en rouge dans
   Freerouting, ou visible comme ligne de chevelu dans KiCad).
3. Le plus souvent, il suffit d'écarter légèrement deux composants
   voisins (dans KiCad, sélectionne le composant et déplace-le de
   quelques millimètres) pour libérer la place, puis relance
   l'auto-routeur sur ce qui reste, ou trace la piste manuellement.
4. Pour une piste manuelle en 6,5 mm : sélectionne l'outil piste, puis
   avant de cliquer, tape la largeur voulue dans le champ en haut de
   l'écran (ou clic droit → **Largeur de piste → 6,5 mm** une fois la
   piste commencée).

## 4. Réimporter dans KiCad

1. Dans Freerouting : **File → Export Specctra Session File (.ses)**.
2. Dans KiCad PCB Editor : **Fichier → Importer → Spécification
   Specctra (.ses)** → sélectionne le fichier généré.
3. Relance le DRC (étape 1) pour confirmer que tout est propre.
4. Sauvegarde le projet.

## 5. Les deux points qui ne se règlent pas en routant

Router plus large ne suffit pas à rendre la carte prête pour 20 A — deux
décisions restent à prendre avant fabrication (détaillées dans le
rapport, section 2.5.5) :

- **Relais K1-K8** : actuellement des Hongfa JQC-3FF (10 A). Il faut les
  remplacer par un modèle 15-20 A de même empreinte THT (le schéma les
  a déjà renommés `Relay_SPDT_20A_A_CONFIRMER` pour ne pas l'oublier).
  Vérifie la disponibilité locale à Goma avant de figer le choix.
- **Bus d'entrée (PHASE_BUS / NEUTRE_BUS)** : si les 8 canaux tirent 20 A
  en même temps, ça fait 160 A à faire passer — aucune piste de circuit
  imprimé ne peut raisonnablement porter ça. La piste de 10 mm sur la
  carte ne doit être vue que comme un talon de connexion ; le vrai
  chemin de puissance doit passer par une barre de cuivre ou un câble de
  forte section, câblé en externe entre le bornier secteur et chaque
  relais.

## 6. Une fois le routage terminé

- Relance le DRC une dernière fois, zéro erreur hors les 12
  `drill_out_of_range` connues (ou corrige aussi celles-là en élargissant
  le perçage des pastilles GND de U1 à 0,3 mm).
- Régénère les fichiers de fabrication (Gerbers, perçage, BOM) via
  **Fichier → Fabrication** dans KiCad.
- Mets à jour la section 2.5.5 du rapport (`rapport/59Travail_...docx` ou
  `rapport/TFC_Complet-2.docx` selon lequel tu continues) pour dire que
  le routage est terminé, et remplace la phrase sur les "15 connexions
  restantes" par le résultat final.

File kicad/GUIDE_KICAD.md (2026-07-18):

# Guide KiCad — Schéma du système multicanal (8 canaux)

Objectif : redessiner le schéma décrit au chapitre 2.5 de ton mémoire, à la
main, dans le vrai KiCad — l'ancien fichier `energie_locatif.kicad_sch`
(archivé dans `ancien-fichier-casse/` à côté de ce guide, pour référence
uniquement) est cassé et ne s'ouvre pas, mais sa liste de composants
ci-dessous est fiable, reprends-la telle quelle.

Tu peux commencer **avant** d'avoir l'ESP32 physique — rien ici ne demande
le matériel en main.

**État au 17 juillet** : d'après ton fichier `multical.kicad_sch`, il te
manque un deuxième `ULN2003A` (tu n'en as qu'un, avec 7 sorties pour 8
relais — voir étape 3 ci-dessous) et le câblage n'est pas encore fait —
voir la correction du Tableau 2.2 à l'étape 5 avant de commencer à câbler.

## 0. Lancer KiCad

Deux installations existent sur cette machine : une snap (KiCad 9.0.7,
périmée) et une flatpak (KiCad 10.0.4, la version stable actuelle,
vérifiée en juillet 2026). Utilise la flatpak :

```bash
flatpak run org.kicad.KiCad
```
(ou depuis le menu applications — si deux icônes "KiCad" apparaissent,
vérifie dans Aide → À propos que tu ouvres bien la 10.0.4)

## 1. Créer le projet

1. **Fichier → Nouveau projet**
2. Nomme-le `multicanal_goma` (évite les espaces/accents dans le nom de
   fichier — KiCad n'aime pas toujours ça)
3. Sauvegarde-le directement dans ce dossier :
   `~/Documents/TFC-Multicanal-Goma/kicad/` (là où se trouve déjà ce guide
   et le symbole `zmpt101b.kicad_sym`, à côté du firmware et de l'appli)
4. Double-clique sur l'icône **Schematic Editor** (feuille bleue) dans la
   fenêtre du projet

## 2. Format de feuille

**Fichier → Propriétés de la feuille** → choisis **A3** (le schéma a
beaucoup de composants, A4 sera trop serré). Remplis le cartouche (titre,
date, ton nom, "Encadreur: Patrick Nzanzu Vingi" — déjà retrouvé dans
l'ancien fichier).

## 3. Placer les composants

Touche **A** (ou icône "Placer un symbole") ouvre le sélecteur. Tape le nom
exact à droite ci-dessous dans la barre de recherche.

**Important** : la liste de composants trouvée dans l'ancien fichier cassé
contenait plusieurs noms qui n'existent pas réellement dans les
bibliothèques KiCad de ta machine (c'est probablement ce qui l'a cassé).
J'ai vérifié un par un le nom exact et la bibliothèque réelle de chaque
composant — utilise ce tableau-ci, pas celui du message précédent.

| Cherche exactement | Bibliothèque réelle | Combien | Où le placer |
|---|---|---|---|
| `ESP32-WROOM-32` | **RF_Module** (pas MCU_Espressif) | 1 | Centre |
| `ACS712xLCTR-20A` | **Sensor_Current** (pas Sensor) | 8 | Colonne de gauche, zone BT |
| `ULN2003A` | **Transistor_Array** (pas Driver) | 2 | Entre ESP32 et relais (chaque ULN2003A pilote jusqu'à 7 sorties, 2 suffisent pour 8 relais) |
| `Relay_SPDT` | Relay | 8 | Colonne de droite, zone HT — voir note ZMPT101B/relais ci-dessous |
| `HLK-PM01` | Converter_ACDC | 1 | Zone HT → alimentation |
| `AMS1117-3.3` | Regulator_Linear | 1 | Zone BT, juste après le HLK-PM01 |
| `D` (diode générique) | Device | 8 | Une en parallèle de chaque relais (roue libre) |
| `R` | Device | 5 | Pull-up strapping pins + limitation courant |
| `C` | Device | 5 | Découplage (près des VCC ACS712 et ESP32) |
| `Conn_01x02_Pin` | Connector | 9 | Un par canal + alimentation secteur |

### ZMPT101B — pas dans les bibliothèques standard

Ce capteur n'existe dans aucune bibliothèque KiCad officielle (normal,
c'est un module très "communauté Arduino", pas un composant industriel
référencé). Bonne nouvelle : tu as déjà un symbole personnalisé tout fait
et valide dans `~/Documents/TFC-Multicanal-Goma/kicad/zmpt101b.kicad_sym` (6 broches : L, N, GND,
GND, VCC, OUT — correspond bien au vrai module). Pour l'utiliser :

1. Dans l'éditeur de schéma : **Préférences → Gestionnaire de bibliothèques
   de symboles**
2. Onglet **Bibliothèque de projet**, clique **+**, choisis
   `~/Documents/TFC-Multicanal-Goma/kicad/zmpt101b.kicad_sym`
3. Il apparaîtra ensuite dans le sélecteur (touche A) sous le nom
   `zmpt101b`

### Relais SLA-05VDC-SL-A — pas de symbole exact non plus

Le nom précis "SLA-05VDC-SL-A" (celui des modules relais tout faits pour
Arduino) n'a pas de symbole officiel KiCad. Utilise le symbole générique
`Relay_SPDT` (fonctionnellement identique — bobine 5V + contact
inverseur) : place-le, puis dans ses propriétés change le champ **Valeur**
de "Relay_SPDT" à "SLA-05VDC-SL-A" pour que ta nomenclature (BOM) reste
correcte, même si le dessin du symbole est générique.

Astuce générale : place d'abord UN exemplaire de chaque, câble-le, puis
sélectionne-le et fais **Ctrl+C / Ctrl+V** pour dupliquer les 7 autres
canaux — beaucoup plus rapide que de rechercher 8 fois le même composant.

## 4. Séparer les zones HT et BT (§2.5.1 de ton mémoire)

C'est le point que ton mémoire promet déjà — respecte-le visuellement dans
le schéma, pas juste dans le texte :

- **Zone haute tension (220V)**, à droite ou en haut de la feuille : arrivée
  secteur (Conn_01x02_Pin), les 8 relais SLA-05VDC-SL-A, le HLK-PM01.
- **Zone basse tension (3.3V/5V)**, à gauche ou en bas : ESP32, les 8
  ACS712, l'AMS1117, les ULN2003A.
- Le ZMPT101B et les ACS712 sont la frontière (isolation galvanique,
  cf. §1.3.4) — dessine une ligne ou une boîte en pointillés entre les deux
  zones sur la feuille, avec une annotation "ISOLATION GALVANIQUE" comme
  rappel visuel pour le jury.

## 5. Câblage — reprends le Tableau 2.2 (corrigé) de ton mémoire

**Correction importante** : contrairement à ce que je t'avais dit au départ,
le symbole `ESP32-WROOM-32` que tu utilises (vérifié directement dans la
bibliothèque KiCad, pas juste supposé) **n'a pas non plus** les broches
GPIO37/GPIO38 — elles n'existent pas sur ce module, DevKitC ou pas. Il n'y a
donc que 6 broches ADC1 réellement utilisables (36, 39, 32, 33, 34, 35) pour
8 canaux. Les canaux 2 et 3 sont déplacés sur ADC2 (GPIO26, GPIO27), sur le
même principe déjà utilisé pour le ZMPT101B (lecture pendant les fenêtres
où le Wi-Fi est inactif, cf. §1.4.3 du mémoire — désormais 3 signaux à
gérer ainsi au lieu d'1, mais aucun composant supplémentaire nécessaire) :

| Canal | ACS712 → ESP32 | ADC | Relais → ESP32 (via ULN2003A) |
|---|---|---|---|
| 1 (bailleur) | GPIO36 | ADC1 | GPIO4 |
| 2 | GPIO26 | ADC2 | GPIO5 |
| 3 | GPIO27 | ADC2 | GPIO13 |
| 4 | GPIO39 | ADC1 | GPIO14 |
| 5 | GPIO32 | ADC1 | GPIO16 |
| 6 | GPIO33 | ADC1 | GPIO17 |
| 7 | GPIO34 | ADC1 | GPIO18 |
| 8 | GPIO35 | ADC1 | GPIO19 |

ZMPT101B → GPIO25 (ADC2).

**Évite ces broches pour toute nouvelle affectation** (strapping pins,
déjà notées dans ton mémoire §2.5.2) : GPIO0, GPIO2, GPIO12, GPIO15.

Pour tracer un fil : touche **W** (wire), clique départ, clique arrivée.
Pour nommer un fil (utile pour les signaux qui se répètent, ex.
`CANAL1_ACS`) : sélectionne-le puis touche **L** (label).

## 6. Vérifier avant de continuer

**Inspecter → Vérification des règles électriques (ERC)** — lance-le, corrige les erreurs
(broches non connectées, conflits de type de pin). Ne passe au routage du
circuit imprimé (PCB, §2.5.3 de ton mémoire) qu'une fois l'ERC propre — ce
sera la prochaine étape, une fois le schéma solide.

## 7. Sauvegarder correctement

**Ctrl+S** régulièrement. KiCad enregistre automatiquement les définitions
complètes des symboles utilisés dans le fichier — contrairement à l'ancien
fichier cassé, tant que tu passes par le vrai logiciel (et pas un script),
ce problème ne peut pas se reproduire.

---

Reviens vers moi avec une capture d'écran ou une description de ce que tu
as si tu bloques sur un placement ou un câblage précis — je peux lire un
export PDF du schéma directement si tu me donnes le chemin du fichier.

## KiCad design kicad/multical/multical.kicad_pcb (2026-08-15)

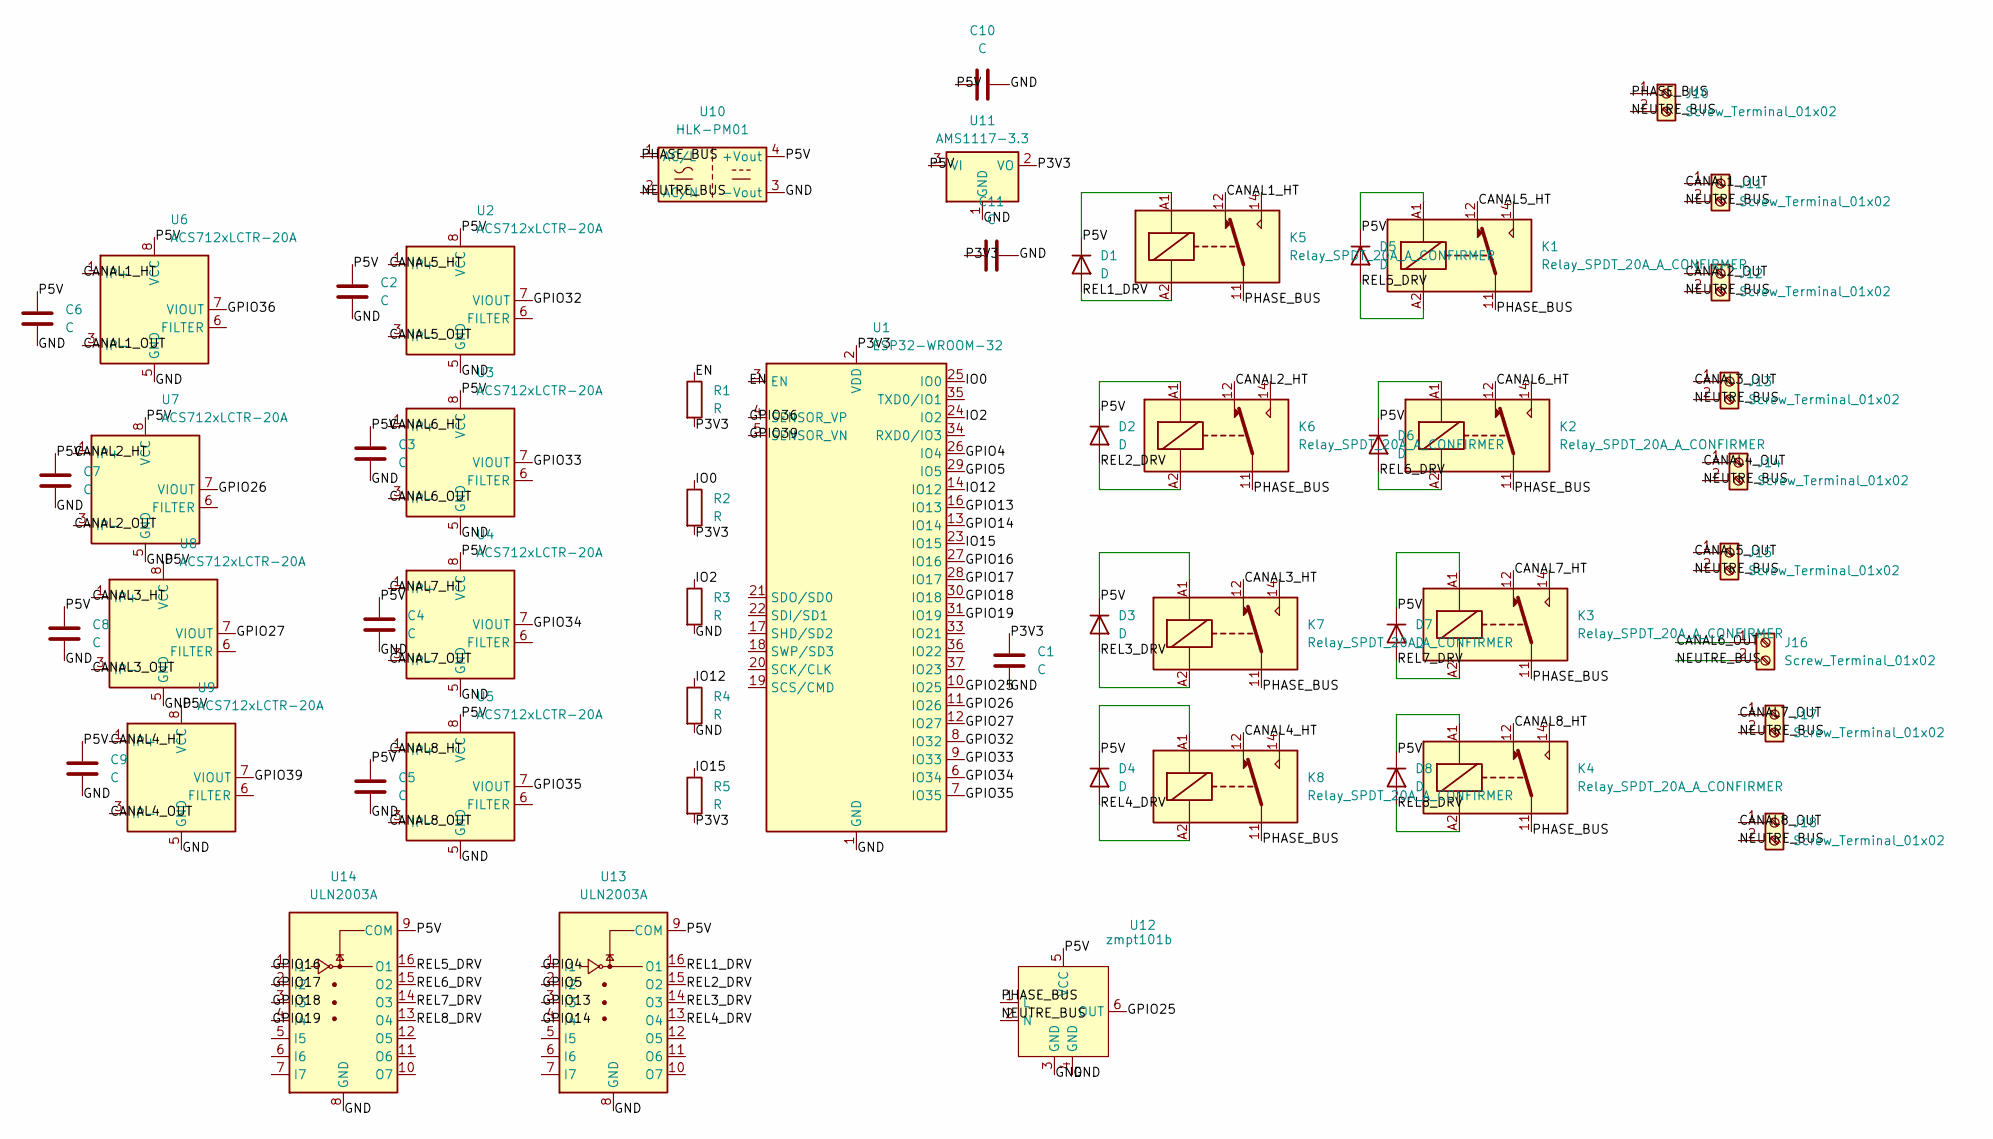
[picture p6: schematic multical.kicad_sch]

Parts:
C1, C2, C3, C4, C5, C6, C7, C8, C9: C; C_Disc_D5.0mm_W2.5mm_P5.00mm
C10, C11: C; CP_Radial_D5.0mm_P2.00mm
D1, D2, D3, D4, D5, D6, D7, D8: D; D_DO-41_SOD81_P7.62mm_Horizontal
J10, J11, J12, J13, J14, J15, J16, J17, J18: Screw_Terminal_01x02; TerminalBlock_MaiXu_MX126-5.0-02P_1x02_P5.00mm
K1, K2, K3, K4, K5, K6, K7, K8: Relay_SPDT_20A_A_CONFIRMER; Relay_SPDT_Hongfa_JQC-3FF_0XX-1Z
R1, R2, R3, R4, R5: R; R_Axial_DIN0207_L6.3mm_D2.5mm_P10.16mm_Horizontal
U1: ESP32-WROOM-32
U2, U3, U4, U5, U6, U7, U8, U9: ACS712xLCTR-20A; SOIC-8_3.9x4.9mm_P1.27mm
U10: HLK-PM01; Converter_ACDC_Hi-Link_HLK-PMxx
U11: AMS1117-3.3; SOT-223-3_TabPin2
U12: zmpt101b; PinHeader_1x06_P2.54mm_Vertical
U13, U14: ULN2003A; DIP-16_W7.62mm

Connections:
/CANAL1_HT: K5.12, U6.1 (IP+), U6.2 (IP+)
/CANAL1_OUT: J11.1, U6.3 (IP-), U6.4 (IP-)
/CANAL2_HT: K6.12, U7.1 (IP+), U7.2 (IP+)
/CANAL2_OUT: J12.1, U7.3 (IP-), U7.4 (IP-)
/CANAL3_HT: K7.12, U8.1 (IP+), U8.2 (IP+)
/CANAL3_OUT: J13.1, U8.3 (IP-), U8.4 (IP-)
/CANAL4_HT: K8.12, U9.1 (IP+), U9.2 (IP+)
/CANAL4_OUT: J14.1, U9.3 (IP-), U9.4 (IP-)
/CANAL5_HT: K1.12, U2.1 (IP+), U2.2 (IP+)
/CANAL5_OUT: J15.1, U2.3 (IP-), U2.4 (IP-)
/CANAL6_HT: K2.12, U3.1 (IP+), U3.2 (IP+)
/CANAL6_OUT: J16.1, U3.3 (IP-), U3.4 (IP-)
/CANAL7_HT: K3.12, U4.1 (IP+), U4.2 (IP+)
/CANAL7_OUT: J17.1, U4.3 (IP-), U4.4 (IP-)
/CANAL8_HT: K4.12, U5.1 (IP+), U5.2 (IP+)
/CANAL8_OUT: J18.1, U5.3 (IP-), U5.4 (IP-)
/EN: R1.1, U1.3 (EN)
/GND: C1.2, C2.2, C3.2, C4.2, C5.2, C6.2, C7.2, C8.2, C9.2, C10.2, C11.2, R3.2, R4.2, U1.1 (GND), U1.15 (GND), U1.38 (GND), U1.39 (GND), U2.5 (GND), U3.5 (GND), U4.5 (GND), U5.5 (GND), U6.5 (GND), U7.5 (GND), U8.5 (GND), U9.5 (GND), U10.3 (-Vout), U11.1 (GND), U12.3 (GND), U12.4 (GND), U13.8 (GND), U14.8 (GND)
/GPIO4: U1.26 (IO4), U13.1 (I1)
/GPIO5: U1.29 (IO5), U13.2 (I2)
/GPIO13: U1.16 (IO13), U13.3 (I3)
/GPIO14: U1.13 (IO14), U13.4 (I4)
/GPIO16: U1.27 (IO16), U14.1 (I1)
/GPIO17: U1.28 (IO17), U14.2 (I2)
/GPIO18: U1.30 (IO18), U14.3 (I3)
/GPIO19: U1.31 (IO19), U14.4 (I4)
/GPIO25: U1.10 (IO25), U12.6 (OUT)
/GPIO26: U1.11 (IO26), U7.7 (VIOUT)
/GPIO27: U1.12 (IO27), U8.7 (VIOUT)
/GPIO32: U1.8 (IO32), U2.7 (VIOUT)
/GPIO33: U1.9 (IO33), U3.7 (VIOUT)
/GPIO34: U1.6 (IO34), U4.7 (VIOUT)
/GPIO35: U1.7 (IO35), U5.7 (VIOUT)
/GPIO36: U1.4 (SENSOR_VP), U6.7 (VIOUT)
/GPIO39: U1.5 (SENSOR_VN), U9.7 (VIOUT)
/IO0: R2.1, U1.25 (IO0)
/IO2: R3.1, U1.24 (IO2)
/IO12: R4.1, U1.14 (IO12)
/IO15: R5.1, U1.23 (IO15)
/NEUTRE_BUS: J10.2, J11.2, J12.2, J13.2, J14.2, J15.2, J16.2, J17.2, J18.2, U10.2 (AC/N), U12.2 (N)
/P3V3: C1.1, C11.1, R1.2, R2.2, R5.2, U1.2 (VDD), U11.2 (VO)
/P5V: C2.1, C3.1, C4.1, C5.1, C6.1, C7.1, C8.1, C9.1, C10.1, D1.1 (K), D2.1 (K), D3.1 (K), D4.1 (K), D5.1 (K), D6.1 (K), D7.1 (K), D8.1 (K), K1.A1, K2.A1, K3.A1, K4.A1, K5.A1, K6.A1, K7.A1, K8.A1, U2.8 (VCC), U3.8 (VCC), U4.8 (VCC), U5.8 (VCC), U6.8 (VCC), U7.8 (VCC), U8.8 (VCC), U9.8 (VCC), U10.4 (+Vout), U11.3 (VI), U12.5 (VCC), U13.9 (COM), U14.9 (COM)
/PHASE_BUS: J10.1, K1.11, K2.11, K3.11, K4.11, K5.11, K6.11, K7.11, K8.11, U10.1 (AC/L), U12.1 (L)
/REL1_DRV: D1.2 (A), K5.A2, U13.16 (O1)
/REL2_DRV: D2.2 (A), K6.A2, U13.15 (O2)
/REL3_DRV: D3.2 (A), K7.A2, U13.14 (O3)
/REL4_DRV: D4.2 (A), K8.A2, U13.13 (O4)
/REL5_DRV: D5.2 (A), K1.A2, U14.16 (O1)
/REL6_DRV: D6.2 (A), K2.A2, U14.15 (O2)
/REL7_DRV: D7.2 (A), K3.A2, U14.14 (O3)
/REL8_DRV: D8.2 (A), K4.A2, U14.13 (O4)

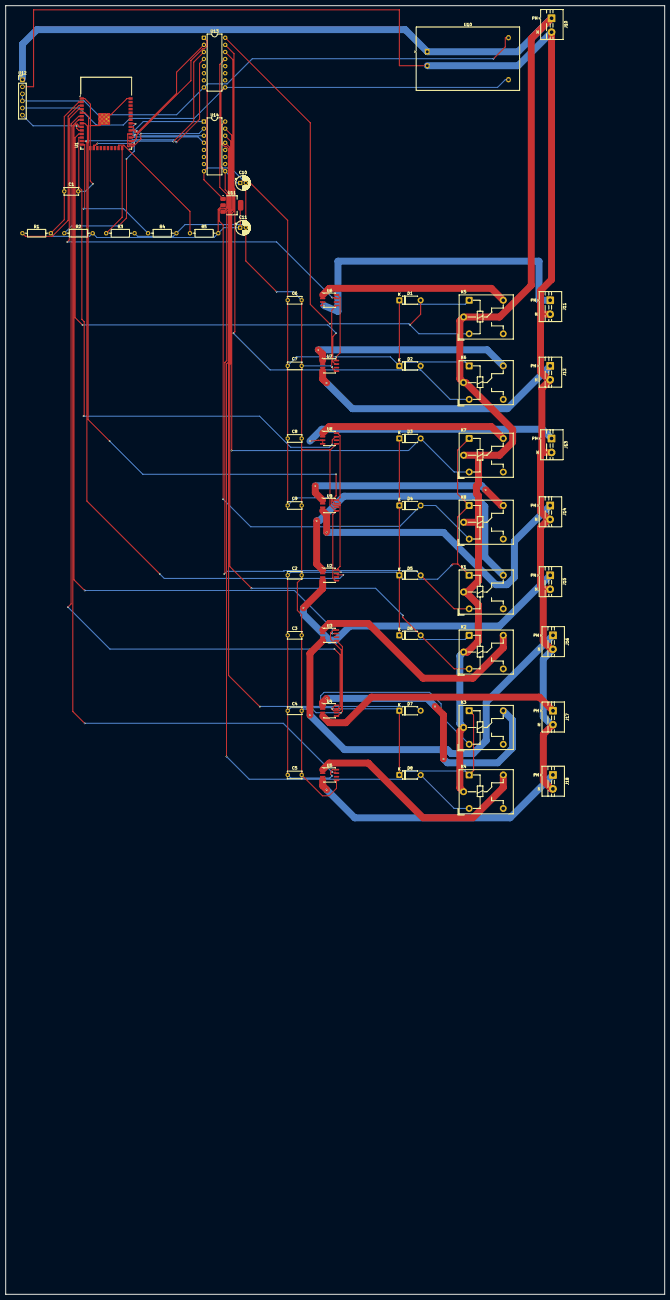
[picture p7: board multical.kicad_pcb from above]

Board: 2 copper layers, 236.0 x 461.5 mm, 55 parts (0 on the bottom side), 51 nets.

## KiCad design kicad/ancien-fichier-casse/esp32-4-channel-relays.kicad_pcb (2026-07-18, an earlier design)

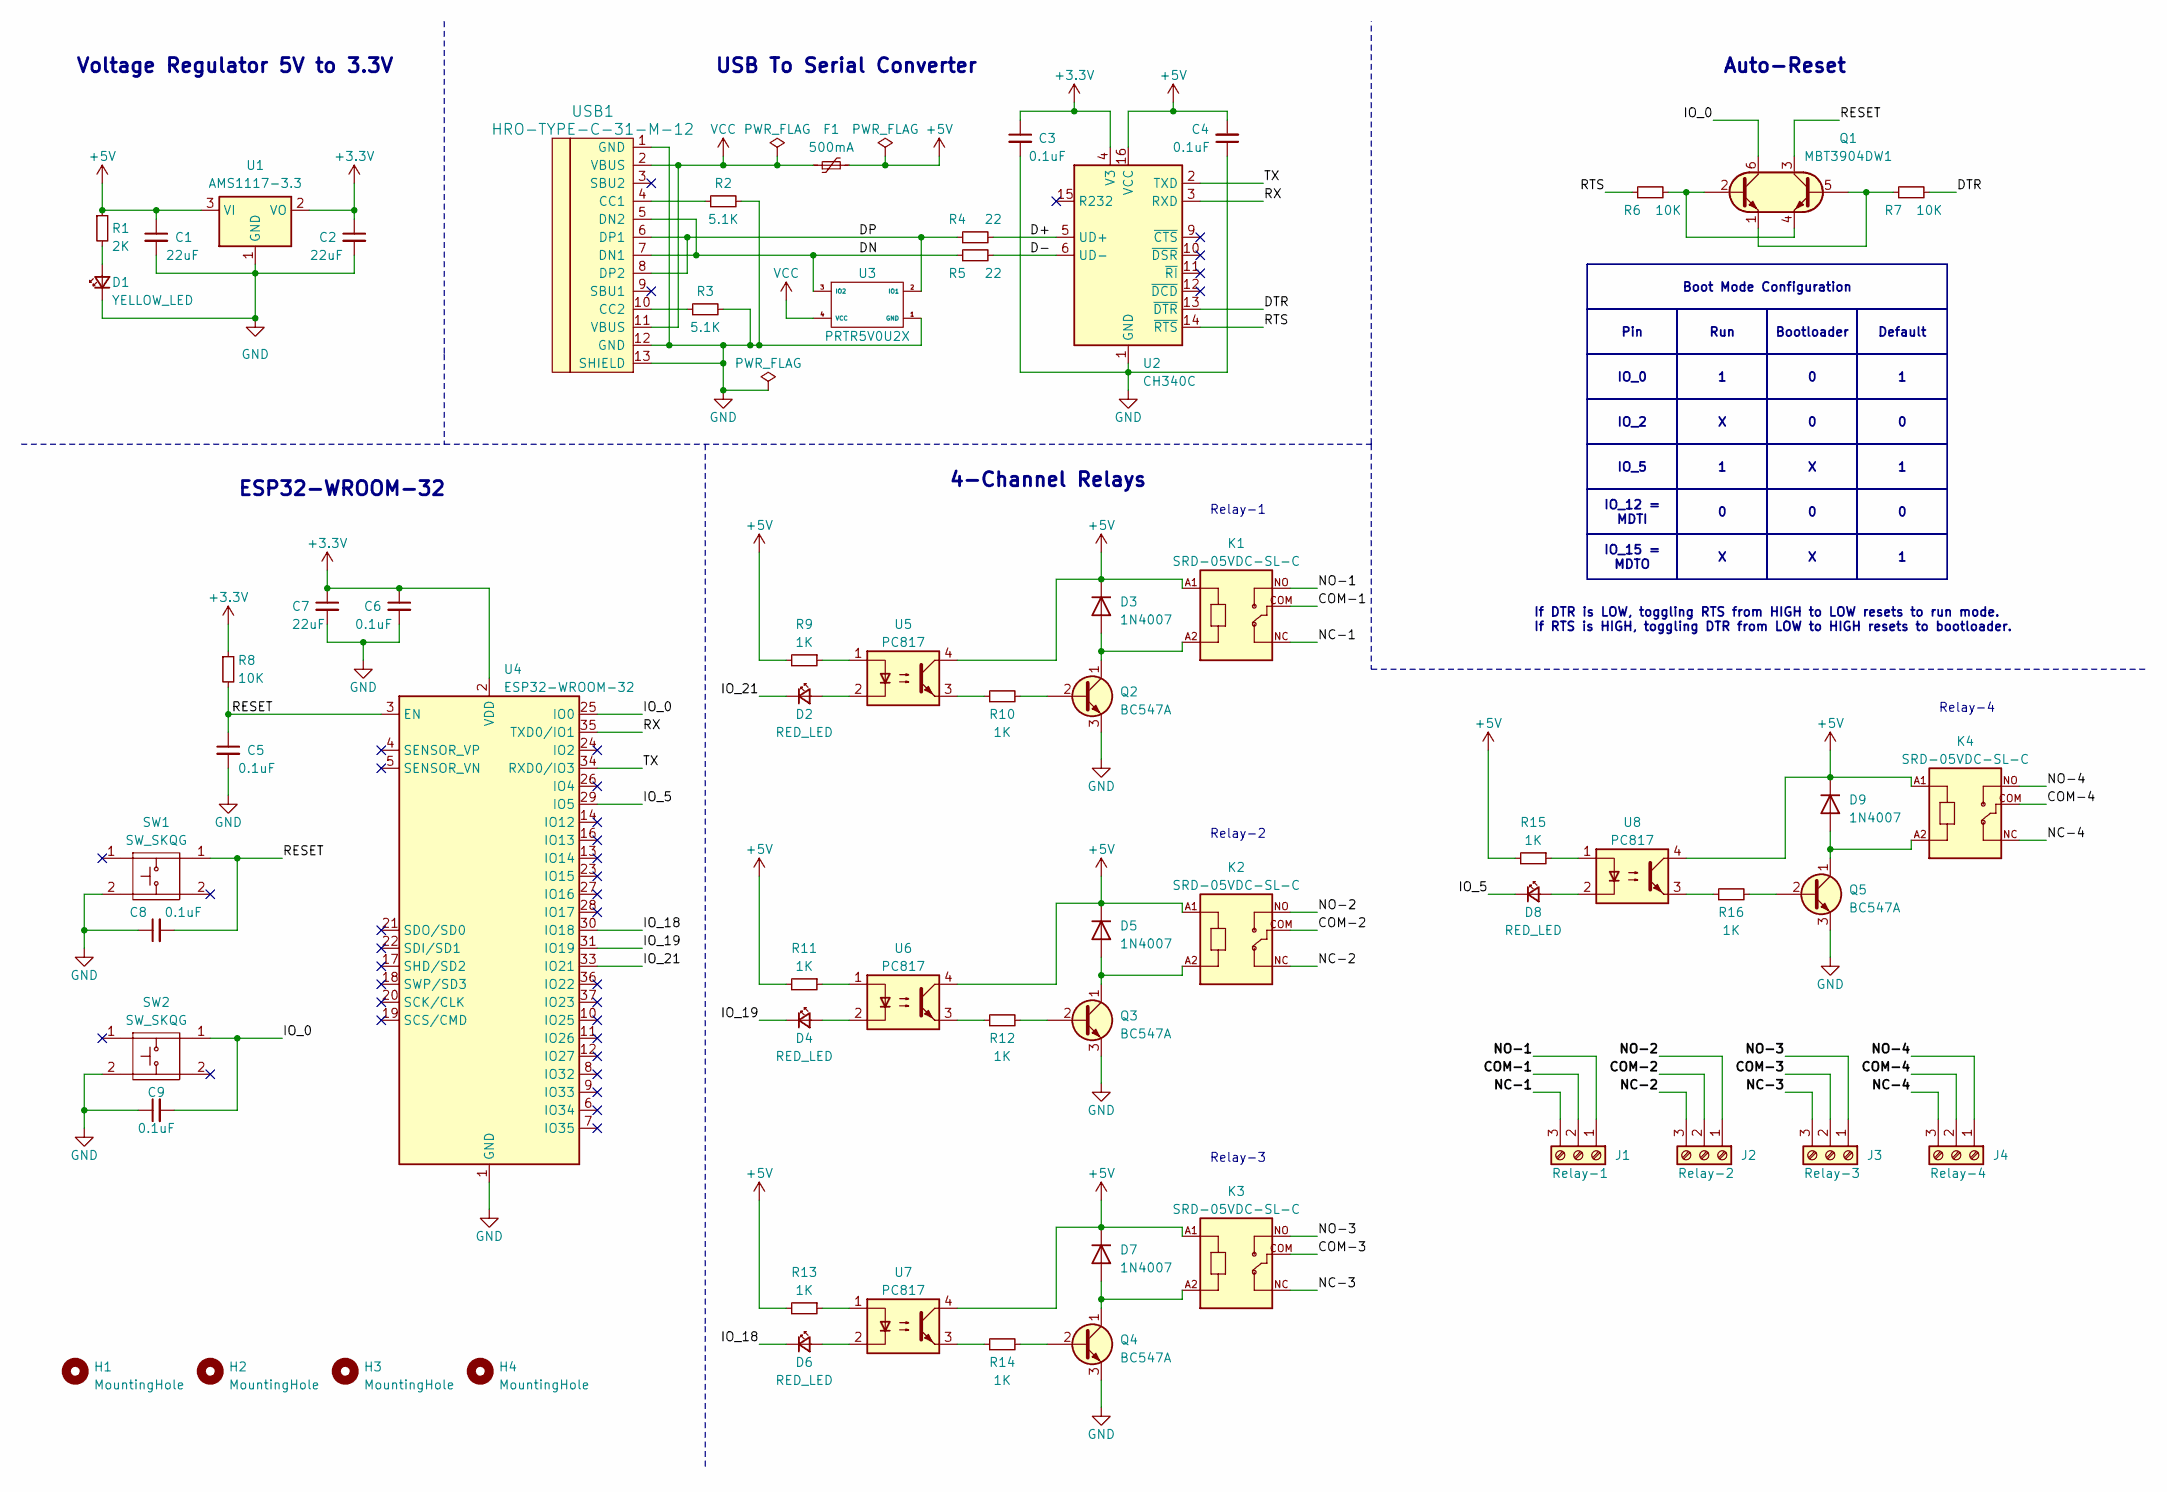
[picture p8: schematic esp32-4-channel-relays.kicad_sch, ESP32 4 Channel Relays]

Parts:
C1, C2, C7: 22uF; C_0805_2012Metric_Pad1.18x1.45mm_HandSolder
C3, C4, C5, C6, C8, C9: 0.1uF; C_0805_2012Metric_Pad1.18x1.45mm_HandSolder
D1: YELLOW_LED; LED_0805_2012Metric_Pad1.15x1.40mm_HandSolder
D2, D4, D6, D8: RED_LED; LED_0805_2012Metric_Pad1.15x1.40mm_HandSolder
D3, D5, D7, D9: 1N4007; D_MELF_Handsoldering
F1: 500mA; Fuse_1206_3216Metric_Pad1.42x1.75mm_HandSolder
H1, H2, H3, H4: MountingHole; MountingHole_3.2mm_M3
J1: Relay-1; TerminalBlock_Phoenix_MKDS-1,5-3-5.08_1x03_P5.08mm_Horizont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
J2: Relay-2; TerminalBlock_Phoenix_MKDS-1,5-3-5.08_1x03_P5.08mm_Horizont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
J3: Relay-3; TerminalBlock_Phoenix_MKDS-1,5-3-5.08_1x03_P5.08mm_Horizont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
J4: Relay-4; TerminalBlock_Phoenix_MKDS-1,5-3-5.08_1x03_P5.08mm_Horizont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
K1, K2, K3, K4: SRD-05VDC-SL-C; RELAY_SRD-05VDC-SL-C
Q1: MBT3904DW1; SOT-363_SC-70-6_Handsoldering
Q2, Q3, Q4, Q5: BC547A; TSOT-23_HandSoldering
R1: 2K; R_0805_2012Metric_Pad1.20x1.40mm_HandSolder
R2, R3: 5.1K; R_0805_2012Metric_Pad1.20x1.40mm_HandSolder
R4, R5: 22; R_0805_2012Metric_Pad1.20x1.40mm_HandSolder
R6, R7, R8: 10K; R_0805_2012Metric_Pad1.20x1.40mm_HandSolder
R9, R10, R11, R12, R13, R14, R15, R16: 1K; R_0805_2012Metric_Pad1.20x1.40mm_HandSolder
SW1, SW2: SW_SKQG; SW_SPST_SKQG_WithStem
U1: AMS1117-3.3; SOT-223-3_TabPin2
U2: CH340C; SOIC-16_3.9x9.9mm_P1.27mm
U3: PRTR5V0U2X; SOT-143_Handsoldering
U4: ESP32-WROOM-32
U5, U6, U7, U8: PC817; SMDIP-4_W7.62mm
USB1: HRO-TYPE-C-31-M-12; HRO-TYPE-C-31-M-12-HandSoldering

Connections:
+3.3V: C2.1, C3.1, C6.1, C7.1, R8.1, U1.2 (VO), U2.4 (V3), U4.2 (VDD)
+5V: C1.1, C4.2, D3.1 (K), D5.1 (K), D7.1 (K), D9.1 (K), F1.2, K1.A1, K2.A1, K3.A1, K4.A1, R1.1, R9.2, R11.2, R13.2, R15.2, U1.3 (VI), U2.16 (VCC), U5.4, U6.4, U7.4, U8.4
/COM-1: J1.2, K1.COM
/COM-2: J2.2, K2.COM
/COM-3: J3.2, K3.COM
/COM-4: J4.2, K4.COM
/D+: R4.2, U2.5 (UD+)
/D-: R5.2, U2.6 (UD-)
/DN: R5.1, U3.3 (IO2), USB1.5 (DN2), USB1.7 (DN1)
/DP: R4.1, U3.2 (IO1), USB1.6 (DP1), USB1.8 (DP2)
/DTR: R7.2, U2.13 (~DTR)
/IO_0: C9.2, Q1.6 (C1), SW2.1, U4.25 (IO0)
/IO_5: D8.1 (K), U4.29 (IO5)
/IO_18: D6.1 (K), U4.30 (IO18)
/IO_19: D4.1 (K), U4.31 (IO19)
/IO_21: D2.1 (K), U4.33 (IO21)
/NC-1: J1.3, K1.NC
/NC-2: J2.3, K2.NC
/NC-3: J3.3, K3.NC
/NC-4: J4.3, K4.NC
/NO-1: J1.1, K1.NO
/NO-2: J2.1, K2.NO
/NO-3: J3.1, K3.NO
/NO-4: J4.1, K4.NO
/RESET: C5.1, C8.2, Q1.3 (C2), R8.2, SW1.1, U4.3 (EN)
/RTS: R6.1, U2.14 (~RTS)
/RX: U2.3 (RXD), U4.35 (TXD0/IO1)
/TX: U2.2 (TXD), U4.34 (RXD0/IO3)
GND: C1.2, C2.2, C3.2, C4.1, C5.2, C6.2, C7.2, C8.1, C9.1, D1.1 (K), Q2.3 (E), Q3.3 (E), Q4.3 (E), Q5.3 (E), R2.2, R3.2, SW1.2, SW2.2, U1.1 (GND), U2.1 (GND), U3.1 (GND), U4.1 (GND), U4.15 (GND), U4.38 (GND), U4.39 (GND), USB1.1 (GND), USB1.12 (GND), USB1.13 (SHIELD)
unnamed: D1.2 (A), R1.2
unnamed: D2.2 (A), U5.2
unnamed: D3.2 (A), K1.A2, Q2.1 (C)
unnamed: D4.2 (A), U6.2
unnamed: D5.2 (A), K2.A2, Q3.1 (C)
unnamed: D6.2 (A), U7.2
unnamed: D7.2 (A), K3.A2, Q4.1 (C)
unnamed: D8.2 (A), U8.2
unnamed: D9.2 (A), K4.A2, Q5.1 (C)
unnamed: Q1.2 (B1), Q1.4 (E2), R6.2
unnamed: Q1.1 (E1), Q1.5 (B2), R7.1
unnamed: Q2.2 (B), R10.2
unnamed: Q3.2 (B), R12.2
unnamed: Q4.2 (B), R14.2
unnamed: Q5.2 (B), R16.2
unnamed: R9.1, U5.1
unnamed: R10.1, U5.3
unnamed: R11.1, U6.1
unnamed: R12.1, U6.3
unnamed: R13.1, U7.1
unnamed: R14.1, U7.3
unnamed: R15.1, U8.1
unnamed: R16.1, U8.3
unnamed: R2.1, USB1.4 (CC1)
unnamed: R3.1, USB1.10 (CC2)
VCC: F1.1, U3.4 (VCC), USB1.2 (VBUS), USB1.11 (VBUS)

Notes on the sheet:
Default
IO_2
IO_15 = MDTO
Bootloader
IO_0
IO_12 = MDTI
Run
Boot Mode Configuration
IO_5
Pin
Voltage Regulator 5V to 3.3V
4-Channel Relays
Relay-1
Relay-4
Relay-3
Relay-2
Auto-Reset
ESP32-WROOM-32
If DTR is LOW, toggling RTS from HIGH to LOW resets to run mode. If RTS is HIGH, toggling DTR from LOW to HIGH resets to bootloader.
USB To Serial Converter

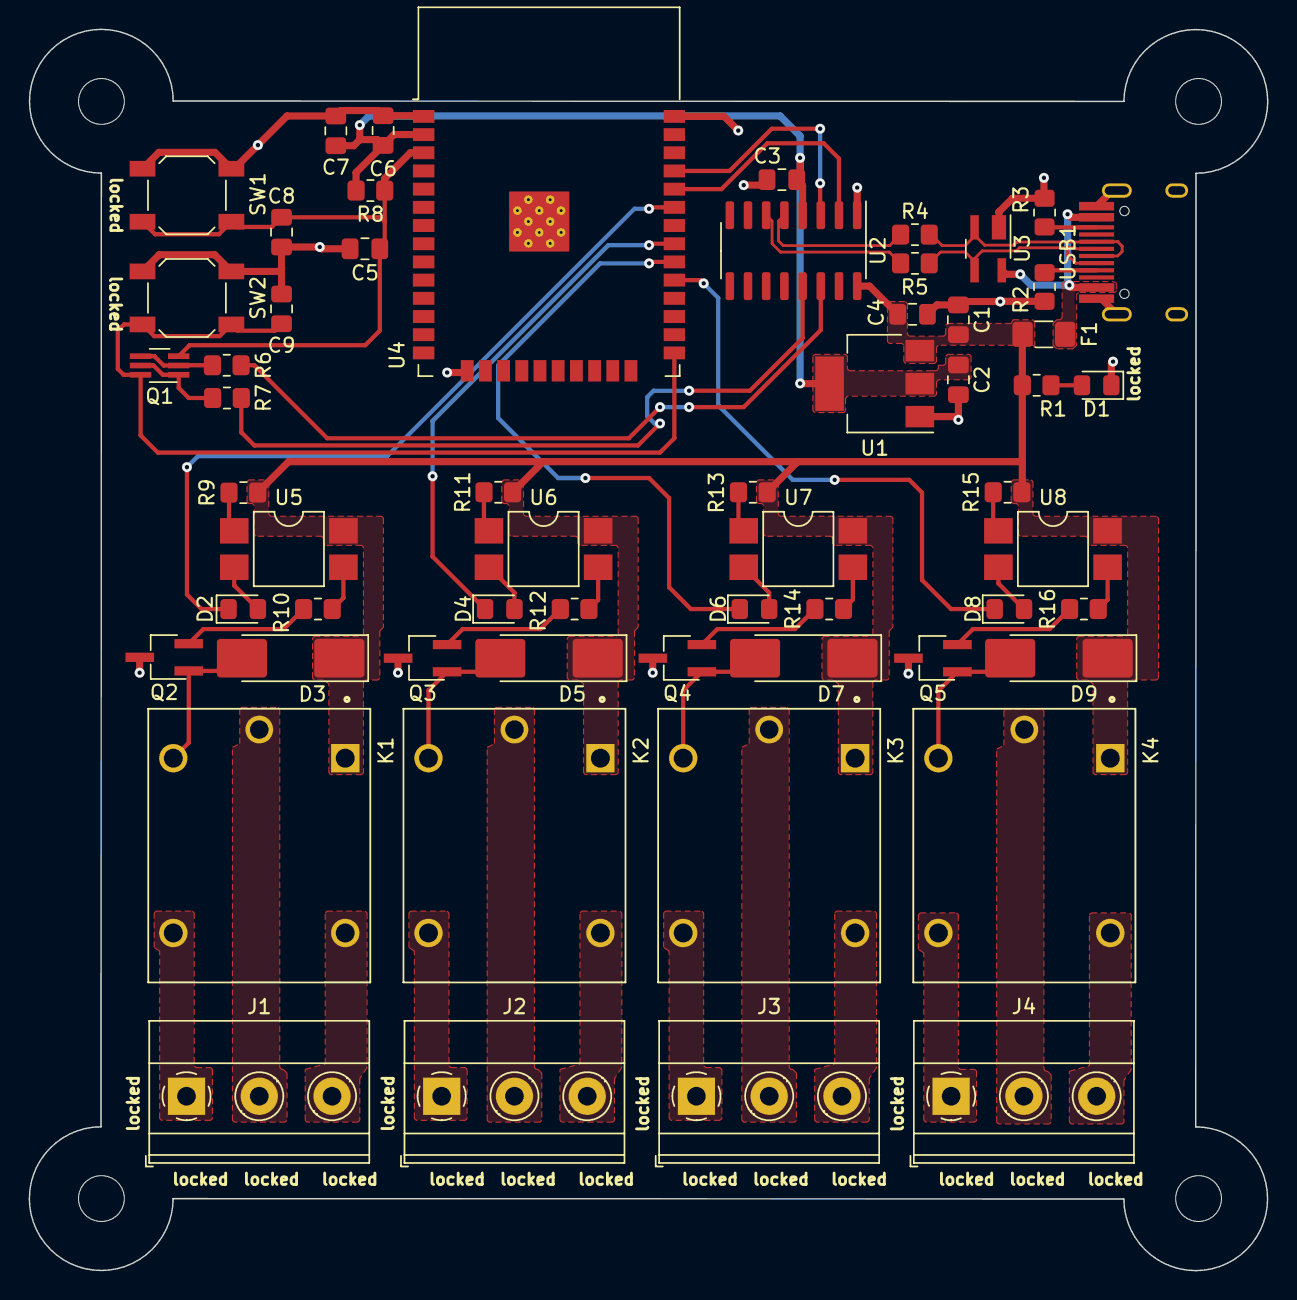
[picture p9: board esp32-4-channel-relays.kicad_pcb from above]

Board: 2 copper layers, 86.4 x 86.6 mm, 63 parts (0 on the bottom side), 55 nets.

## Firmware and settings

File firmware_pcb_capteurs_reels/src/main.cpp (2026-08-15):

// TFC ULPGL - Systeme embarque IoT multicanal de sous-comptage
// Firmware "capteurs reels" (ACS712 + ZMPT101B, 8 canaux) - PCB chapitre 2.
//
// NON TESTE SUR MATERIEL REEL : le PCB concu sous KiCad n'a pas encore ete
// fabrique ni assemble (cf. README.md de ce dossier et rapport §3.7). Ce
// firmware traduit fidelement l'algorithme et le brochage decrits dans le
// memoire (§2.7, Tableau 2.2). Les constantes de calibration (config.h) sont
// des valeurs nominales de datasheet a verifier sur le circuit reel.
//
// Cf. le dossier voisin firmware/ pour la version reellement construite et
// validee (maquette perfboard, 4 canaux, potentiometres simulant les capteurs).

#include <Arduino.h>
#include <WiFi.h>
#include <AsyncTCP.h>
#include <ESPAsyncWebServer.h>
#include <ArduinoJson.h>
#include <LittleFS.h>
#include <Preferences.h>
#include <vector>
#include <math.h>
#include "driver/adc.h"
#include "esp_timer.h"

#include "config.h"

struct CanalEtat {
  float courant_A;            // I_eff (A), calcule sur le dernier cycle secteur complet
  float puissance_W;          // P, puissance active
  float puissanceApparenteVA; // S = I_eff * V_eff
  float puissanceReactiveVAR; // Q = sqrt(S^2 - P^2)
  float cosPhi;                // P / S, calcule (pas suppose egal a 1)
  float energie_kWh;
  float energie_prev_kWh;
  float credit_USD;
  bool  relaisFerme;
  bool  coupureVolontaire;
  String nomAffiche;
  String dernierEvenement;
  unsigned long dernierHorodatageMs;
  unsigned long dernierCycleMs;  // pour Delta t reel entre deux cycles de calcul de CE canal
};

struct EvenementEnAttente {
  int canal;
  String type;
  float valeur;
  unsigned long horodatageMs;
};

static CanalEtat canaux[NUM_CANAUX];
static float tensionSecteur_V = 0.0f;   // V_eff du dernier canal mesure (commun, cf. §2.7)
static float tarifCourant = TARIF_USD_PAR_KWH;
static std::vector<EvenementEnAttente> evenementsEnAttente;

static float offsetCourant_V[NUM_CANAUX];
static float offsetTension_V = ADC_VREF / 2.0f;

static SemaphoreHandle_t mutexCanaux;
static SemaphoreHandle_t mutexEvenements;
static AsyncWebServer server(80);

// ---------------------------------------------------------------------------
// Persistance NVS (Preferences) : credit + energie par canal
// ---------------------------------------------------------------------------
static void chargerEtatDepuisNVS() {
  Preferences prefs;
  for (int i = 0; i < NUM_CANAUX; i++) {
    char ns[16];
    snprintf(ns, sizeof(ns), "canal%d", i);
    prefs.begin(ns, true);
    canaux[i].credit_USD        = prefs.getFloat("credit", CREDIT_INITIAL_USD);
    canaux[i].energie_kWh       = prefs.getFloat("energie", 0.0f);
    canaux[i].coupureVolontaire = prefs.getBool("coupvol", false);
    canaux[i].nomAffiche        = prefs.getString("nom", "");
    prefs.end();
    canaux[i].energie_prev_kWh    = canaux[i].energie_kWh;
    canaux[i].relaisFerme         = canaux[i].credit_USD > 0.0f && !canaux[i].coupureVolontaire;
    canaux[i].dernierEvenement    = "demarrage";
    canaux[i].dernierHorodatageMs = millis();
    canaux[i].dernierCycleMs      = 0; // 0 = pas encore de cycle valide (cf. TacheAcquisitionEtCalcul)
  }
  Preferences config;
  config.begin("config", true);
  tarifCourant = config.getFloat("tarif", TARIF_USD_PAR_KWH);
  config.end();
}

static void sauverCanalDansNVS(int i) {
  char ns[16];
  snprintf(ns, sizeof(ns), "canal%d", i);
  Preferences prefs;
  prefs.begin(ns, false);
  prefs.putFloat("credit", canaux[i].credit_USD);
  prefs.putFloat("energie", canaux[i].energie_kWh);
  prefs.putBool("coupvol", canaux[i].coupureVolontaire);
  prefs.putString("nom", canaux[i].nomAffiche);
  prefs.end();
}

static int authentifierRequete(AsyncWebServerRequest *request) {
  for (int i = 0; i < NUM_CANAUX; i++) {
    if (request->authenticate(CANAL_USER[i], CANAL_PASSWORD[i])) return i;
  }
  return -1;
}

static bool authentifierElectricien(AsyncWebServerRequest *request) {
  return request->authenticate(ELECTRICIEN_USER, ELECTRICIEN_PASSWORD);
}

static void mettreEnAttente(int canal, const String &type, float valeur) {
  if (xSemaphoreTake(mutexEvenements, pdMS_TO_TICKS(100)) == pdTRUE) {
    if (evenementsEnAttente.size() >= MAX_EVENEMENTS_EN_ATTENTE) {
      evenementsEnAttente.erase(evenementsEnAttente.begin());
    }
    evenementsEnAttente.push_back({canal, type, valeur, millis()});
    xSemaphoreGive(mutexEvenements);
  }
}

// ---------------------------------------------------------------------------
// Lecture ADC2 "securisee" : contrairement a analogRead() sur une broche
// ADC2 (qui peut silencieusement renvoyer 0 si le pilote Wi-Fi occupe l'ADC2
// - piege classique et documente de l'ESP32, cf. config.h), adc2_get_raw()
// renvoie un code d'erreur explicite qu'on peut traiter proprement : on
// laisse simplement tomber CET echantillon plutot que d'enregistrer une
// fausse valeur nulle qui fausserait le calcul RMS.
// ---------------------------------------------------------------------------
static bool lireADC2Securise(adc2_channel_t canal, int &valeurBrute) {
  int brut = 0;
  esp_err_t err = adc2_get_raw(canal, ADC_WIDTH_BIT_12, &brut);
  if (err != ESP_OK) return false;
  valeurBrute = brut;
  return true;
}

static adc2_channel_t adc2CanalCourant(int canal) {
  return (canal == 1) ? ADC2_CHANNEL_9 : ADC2_CHANNEL_7; // canal 1 -> GPIO26, canal 2 -> GPIO27
}

// ---------------------------------------------------------------------------
// Calibration des offsets DC (Vcc/2) au demarrage - cf. config.h,
// N_ECHANTILLONS_CALIBRATION. Suppose qu'aucun courant ne circule encore
// (mettre le systeme sous tension avant les charges, cf.
// GUIDE_ASSEMBLAGE_ET_FLASH.md du firmware maquette pour la procedure
// equivalente).
// ---------------------------------------------------------------------------
static void calibrerOffsets() {
  Serial.println(F("Calibration des offsets DC (Vcc/2) - aucun courant ne doit circuler..."));
  for (int i = 0; i < NUM_CANAUX; i++) {
    double somme = 0;
    int valides = 0;
    for (int k = 0; k < N_ECHANTILLONS_CALIBRATION; k++) {
      int brut;
      bool ok;
      if (i == 1 || i == 2) {
        ok = lireADC2Securise(adc2CanalCourant(i), brut);
      } else {
        brut = analogRead(PIN_COURANT_ADC1[i]);
        ok = true;
      }
      if (ok) { somme += brut; valides++; }
      delayMicroseconds(200);
    }
    offsetCourant_V[i] = valides > 0
        ? (somme / valides) / (float)ADC_RESOLUTION * ADC_VREF
        : ADC_VREF / 2.0f; // repli raisonnable si l'ADC2 est reste indisponible durant toute la calibration
  }

  double sommeT = 0;
  int validesT = 0;
  for (int k = 0; k < N_ECHANTILLONS_CALIBRATION; k++) {
    int brut;
    if (lireADC2Securise(ADC2_CHANNEL_8, brut)) { sommeT += brut; validesT++; }
    delayMicroseconds(200);
  }
  offsetTension_V = validesT > 0
      ? (sommeT / validesT) / (float)ADC_RESOLUTION * ADC_VREF
      : ADC_VREF / 2.0f;

  Serial.printf("Offsets calibres : tension=%.4fV\n", offsetTension_V);
}

// ---------------------------------------------------------------------------
// Acquisition + calcul RMS/puissance pour UN canal, sur un cycle secteur
// complet (N_ECHANTILLONS_CYCLE echantillons synchronises courant/tension,
// cf. memoire §2.7). Retourne false si trop d'echantillons ont ete perdus
// (fenetres Wi-Fi actif sur l'ADC2, cf. lireADC2Securise) pour produire une
// mesure fiable sur ce cycle - le canal garde alors sa derniere valeur
// connue plutot que d'afficher un resultat degrade silencieusement.
// ---------------------------------------------------------------------------
struct MesureCycle { float I_eff; float V_eff; float P; };

static bool acquerirCycleCanal(int canal, MesureCycle &resultat) {
  double sommeI2 = 0, sommeV2 = 0, sommeVI = 0;
  int valides = 0;
  bool courantSurADC2 = (canal == 1 || canal == 2);

  int64_t prochainEchantillon = esp_timer_get_time();
  for (int n = 0; n < N_ECHANTILLONS_CYCLE; n++) {
    while (esp_timer_get_time() < prochainEchantillon) { /* attente active, < 500us */ }
    prochainEchantillon += INTERVALLE_ECHANTILLON_US;

    int brutCourant = 0, brutTension = 0;
    bool okCourant = courantSurADC2
        ? lireADC2Securise(adc2CanalCourant(canal), brutCourant)
        : (brutCourant = analogRead(PIN_COURANT_ADC1[canal]), true);
    bool okTension = lireADC2Securise(ADC2_CHANNEL_8, brutTension); // ZMPT101B, toujours ADC2

    if (!okCourant || !okTension) continue; // echantillon perdu, cf. commentaire ci-dessus

    float vCourant = (brutCourant / (float)ADC_RESOLUTION) * ADC_VREF - offsetCourant_V[canal];
    float vTension = (brutTension / (float)ADC_RESOLUTION) * ADC_VREF - offsetTension_V;

    float i = vCourant / ACS712_SENSIBILITE_V_PAR_A;
    float v = vTension * ZMPT_FACTEUR_CALIBRATION;

    sommeI2 += (double)i * i;
    sommeV2 += (double)v * v;
    sommeVI += (double)v * i;
    valides++;
  }

  if (valides < N_ECHANTILLONS_CYCLE / 2) return false; // trop d'echantillons perdus sur ce cycle

  resultat.I_eff = sqrtf(sommeI2 / valides);
  resultat.V_eff = sqrtf(sommeV2 / valides);
  resultat.P     = sommeVI / valides;
  return true;
}

// ---------------------------------------------------------------------------
// Tache 1 - Acquisition sequentielle des 8 canaux + calcul RMS/puissance
// (fusion des taches "Acquisition" et "Calcul" de la maquette : ici les deux
// sont intrinsequement liees, cf. memoire §2.7/§2.7 "acquisition sequentielle").
// Chaque canal occupe ~20 ms minimum (un cycle secteur) ; un tour complet des
// 8 canaux prend donc environ 160 ms ou plus selon les echantillons perdus.
// ---------------------------------------------------------------------------
void TacheAcquisitionEtCalcul(void *param) {
  unsigned long dernierAffichage = 0;
  for (;;) {
    for (int i = 0; i < NUM_CANAUX; i++) {
      bool relaisFermeActuel;
      if (xSemaphoreTake(mutexCanaux, pdMS_TO_TICKS(20)) == pdTRUE) {
        relaisFermeActuel = canaux[i].relaisFerme;
        xSemaphoreGive(mutexCanaux);
      } else {
        relaisFermeActuel = true; // hypothese optimiste, sera corrigee au prochain cycle
      }

      if (!relaisFermeActuel) {
        // Relais ouvert = coupe physiquement : pas de mesure a faire, valeurs a 0
        // (cf. meme raisonnement que sur la maquette : eviter toute derive due au
        // bruit d'un capteur non alimente/non traverse par un courant reel).
        if (xSemaphoreTake(mutexCanaux, pdMS_TO_TICKS(20)) == pdTRUE) {
          canaux[i].courant_A = 0.0f;
          canaux[i].puissance_W = 0.0f;
          canaux[i].puissanceApparenteVA = 0.0f;
          canaux[i].puissanceReactiveVAR = 0.0f;
          canaux[i].cosPhi = 0.0f;
          canaux[i].dernierCycleMs = millis();
          xSemaphoreGive(mutexCanaux);
        }
        continue;
      }

      MesureCycle m;
      bool ok = acquerirCycleCanal(i, m);
      if (!ok) continue; // on garde la derniere valeur connue de ce canal

      float S = m.I_eff * m.V_eff;
      float P = m.P;
      float Q = sqrtf(fmaxf(S * S - P * P, 0.0f));

      if (xSemaphoreTake(mutexCanaux, pdMS_TO_TICKS(20)) == pdTRUE) {
        canaux[i].courant_A = m.I_eff;
        tensionSecteur_V = m.V_eff; // tension secteur commune, supposee stable sur le tour (§2.7)
        canaux[i].puissance_W = P;
        canaux[i].puissanceApparenteVA = S;
        canaux[i].puissanceReactiveVAR = Q;
        canaux[i].cosPhi = (S > 0.0001f) ? (P / S) : 0.0f;

        unsigned long maintenant = millis();
        if (canaux[i].dernierCycleMs != 0) {
          float dt_h = (maintenant - canaux[i].dernierCycleMs) / 1000.0f / 3600.0f;
          if (dt_h > 0.0f && dt_h < 1.0f) { // garde-fou : ecarte un Delta t aberrant (premier tour, overflow millis())
            canaux[i].energie_kWh += (P / 1000.0f) * dt_h; // E += P x dt (methode des rectangles, cf. §2.7)
          }
        }
        canaux[i].dernierCycleMs = maintenant;
        xSemaphoreGive(mutexCanaux);
      }
    }

    if (millis() - dernierAffichage >= PERIODE_AFFICHAGE_MS) {
      dernierAffichage = millis();
      Serial.println(F("\n--- Canal | V_secteur(V) | I(A) | P(W) | S(VA) | Q(VAR) | cos(phi) | E(kWh) | Credit(USD) | Relais ---"));
      if (xSemaphoreTake(mutexCanaux, pdMS_TO_TICKS(50)) == pdTRUE) {
        for (int i = 0; i < NUM_CANAUX; i++) {
          Serial.printf("%-6d| %-13.2f| %-6.3f| %-7.2f| %-7.2f| %-7.2f| %-9.3f| %-9.5f| %-12.4f| %s\n",
                        i, tensionSecteur_V, canaux[i].courant_A, canaux[i].puissance_W,
                        canaux[i].puissanceApparenteVA, canaux[i].puissanceReactiveVAR, canaux[i].cosPhi,
                        canaux[i].energie_kWh, canaux[i].credit_USD,
                        canaux[i].relaisFerme ? "FERME" : "OUVERT");
        }
        xSemaphoreGive(mutexCanaux);
      }
    }
  }
}

// ---------------------------------------------------------------------------
// Tache 2 - Gestion des credits et des relais (identique a la maquette)
// ---------------------------------------------------------------------------
void TacheGestionCredits(void *param) {
  for (;;) {
    if (xSemaphoreTake(mutexCanaux, pdMS_TO_TICKS(50)) == pdTRUE) {
      for (int i = 0; i < NUM_CANAUX; i++) {
        float delta_kWh = canaux[i].energie_kWh - canaux[i].energie_prev_kWh;
        if (delta_kWh > 0.0f) {
          canaux[i].credit_USD -= delta_kWh * tarifCourant;
          canaux[i].energie_prev_kWh = canaux[i].energie_kWh;
        }

        bool doitEtreFerme = canaux[i].credit_USD > 0.0f && !canaux[i].coupureVolontaire;
        if (doitEtreFerme != canaux[i].relaisFerme) {
          canaux[i].relaisFerme = doitEtreFerme;
          String evt = doitEtreFerme
              ? "retablissement"
              : (canaux[i].coupureVolontaire ? "coupure_volontaire" : "coupure_credit");
          canaux[i].dernierEvenement = evt;
          canaux[i].dernierHorodatageMs = millis();
          mettreEnAttente(i, evt, 0.0f);
        }
        digitalWrite(PIN_RELAIS[i], canaux[i].relaisFerme ? HIGH : LOW);
      }
      xSemaphoreGive(mutexCanaux);
    }
    vTaskDelay(pdMS_TO_TICKS(PERIODE_CREDITS_MS));
  }
}

// ---------------------------------------------------------------------------
// Tache 3 - Persistance LittleFS + NVS (identique a la maquette)
// ---------------------------------------------------------------------------
void TachePersistanceLittleFS(void *param) {
  for (;;) {
    vTaskDelay(pdMS_TO_TICKS(PERIODE_PERSISTANCE_MS));
    if (xSemaphoreTake(mutexCanaux, pdMS_TO_TICKS(100)) == pdTRUE) {
      for (int i = 0; i < NUM_CANAUX; i++) {
        sauverCanalDansNVS(i);

        JsonDocument doc;
        doc["canal"] = i;
        doc["energie_cumulee_kWh"] = canaux[i].energie_kWh;
        doc["credit_restant"] = canaux[i].credit_USD;
        doc["dernier_evenement"] = canaux[i].dernierEvenement;
        doc["horodatage_ms"] = canaux[i].dernierHorodatageMs;

        char path[24];
        snprintf(path, sizeof(path), "/canal%d.json", i);
        File f = LittleFS.open(path, "w");
        if (f) { serializeJson(doc, f); f.close(); }
      }
      xSemaphoreGive(mutexCanaux);
    }
  }
}

static String construireJsonEtat() {
  JsonDocument doc;
  doc["tension_secteur_V"] = tensionSecteur_V;
  doc["tarif_usd_par_kwh"] = tarifCourant;
  doc["maintenant_ms"] = millis();
  JsonArray arr = doc["canaux"].to<JsonArray>();
  if (xSemaphoreTake(mutexCanaux, pdMS_TO_TICKS(100)) == pdTRUE) {
    for (int i = 0; i < NUM_CANAUX; i++) {
      JsonObject c = arr.add<JsonObject>();
      c["canal"] = i;
      c["role"] = (i == 0) ? "bailleur" : "locataire";
      c["courant_A"] = canaux[i].courant_A;
      c["puissance_W"] = canaux[i].puissance_W;
      c["puissance_apparente_VA"] = canaux[i].puissanceApparenteVA;
      c["puissance_reactive_VAR"] = canaux[i].puissanceReactiveVAR;
      c["energie_kWh"] = canaux[i].energie_kWh;
      c["credit_USD"] = canaux[i].credit_USD;
      c["credit_kWh"] = (tarifCourant > 0.0f) ? (canaux[i].credit_USD / tarifCourant) : 0.0f;
      c["cos_phi"] = canaux[i].cosPhi;
      c["relais_ferme"] = canaux[i].relaisFerme;
      c["coupure_volontaire"] = canaux[i].coupureVolontaire;
      c["nom_affiche"] = canaux[i].nomAffiche;
      c["dernier_evenement"] = canaux[i].dernierEvenement;
      c["dernier_horodatage_ms"] = canaux[i].dernierHorodatageMs;
    }
    xSemaphoreGive(mutexCanaux);
  }
  String out;
  serializeJson(doc, out);
  return out;
}
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
void loop() {
  vTaskDelay(pdMS_TO_TICKS(1000));
}

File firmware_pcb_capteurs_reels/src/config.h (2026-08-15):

#pragma once

// =============================================================================
// Configuration - version "capteurs reels" (ACS712 + ZMPT101B), 8 canaux
// Cible : le PCB concu sous KiCad (chapitre 2 du memoire, module WROOM-32 nu).
//
// IMPORTANT : ce firmware n'a PAS ete teste sur le materiel reel - le PCB n'a
// pas encore ete fabrique ni assemble au moment de l'ecriture de ce code (cf.
// rapport, discussion des resultats §3.7 et README de ce dossier). Il traduit
// fidelement l'algorithme et le brochage decrits dans le memoire (§2.7,
// Tableau 2.2), mais les constantes de calibration (ACS712_SENSIBILITE_V_PAR_A,
// ZMPT_FACTEUR_CALIBRATION, offsets) sont des valeurs nominales de datasheet a
// verifier/ajuster sur le circuit reel avant toute mise en service.
//
// Cf. firmware/ (dossier voisin) pour la version validee sur la maquette
// physique reelle (4 canaux, potentiometres simulant les capteurs).
// =============================================================================

#define NUM_CANAUX 8

// --- Echantillonnage synchrone courant/tension (cf. memoire §2.7) ---
// N = 40 echantillons par periode secteur (50 Hz => cycle de 20 ms), un
// compromis entre fidelite de restitution de la forme d'onde et charge de
// calcul compatible avec les contraintes temps reel du firmware (§1.4.2).
static const int      FREQUENCE_SECTEUR_HZ      = 50;
static const uint32_t PERIODE_SECTEUR_US        = 1000000UL / FREQUENCE_SECTEUR_HZ; // 20000 us
static const int      N_ECHANTILLONS_CYCLE      = 40;
static const uint32_t INTERVALLE_ECHANTILLON_US = PERIODE_SECTEUR_US / N_ECHANTILLONS_CYCLE; // 500 us

// --- Broches ADC1 des capteurs de courant ACS712 (cf. Tableau 2.2) ---
// Canal 0 (bailleur) + canaux 3 a 7 (locataires 3 a 7) : ADC1, utilisable en
// continu meme Wi-Fi actif (§1.4.3).
// index canal ->broche : 0->GPIO36, 3->GPIO39, 4->GPIO32, 5->GPIO33, 6->GPIO34, 7->GPIO35
static const int PIN_COURANT_ADC1[NUM_CANAUX] = {
    36, // canal 0 (bailleur)      - ADC1_CH0
    -1, // canal 1 (locataire 1)   - sur ADC2, cf. PIN_COURANT_ADC2 ci-dessous
    -1, // canal 2 (locataire 2)   - sur ADC2, cf. PIN_COURANT_ADC2 ci-dessous
    39, // canal 3 (locataire 3)   - ADC1_CH3
    32, // canal 4 (locataire 4)   - ADC1_CH4
    33, // canal 5 (locataire 5)   - ADC1_CH5
    34, // canal 6 (locataire 6)   - ADC1_CH6
    35  // canal 7 (locataire 7)   - ADC1_CH7
};

// --- Broches ADC2 des capteurs de courant ACS712 pour les canaux 1 et 2 ---
// GPIO37/GPIO38 (Tableau 2.2 "ideal") ne sont PAS sortis sur le module
// ESP32-WROOM-32 : on utilise GPIO26/GPIO27 (ADC2_CH9/ADC2_CH7) a la place.
// ADC2 n'est PAS utilisable pendant que le pilote Wi-Fi l'occupe (limitation
// materielle bien documentee de l'ESP32) : cf. lireADC2Securise() dans
// main.cpp, qui gere ce cas plutot que de l'ignorer silencieusement (piege
// classique d'analogRead() sur ADC2, qui peut renvoyer 0 sans erreur).
static const int PIN_COURANT_ADC2[2] = {
    26, // canal 1 (locataire 1) - ADC2_CH9
    27  // canal 2 (locataire 2) - ADC2_CH7
};

// --- Broche ADC2 du capteur de tension ZMPT101B, commun a tous les canaux ---
// GPIO25 (ADC2_CH8, cf. Tableau 2.2). Meme contrainte ADC2/Wi-Fi que ci-dessus.
static const int PIN_TENSION_ADC2 = 25;

// --- Broches de commande des relais (cf. Tableau 2.2) ---
static const int PIN_RELAIS[NUM_CANAUX] = {4, 5, 13, 14, 16, 17, 18, 19};

// --- Calibration des capteurs (VALEURS NOMINALES DE DATASHEET - a verifier
//     sur le circuit reel avant mise en service, cf. remarque en tete de
//     fichier) ---
static const float ADC_VREF        = 3.3f;
static const int   ADC_RESOLUTION  = 4095;

// ACS712-20A : 100 mV par ampere (datasheet Allegro), sortie centree sur
// Vcc/2 au repos (0 A). Tolerance fabricant de l'ordre de quelques % - a
// recalibrer canal par canal si besoin de precision metrologique.
static const float ACS712_SENSIBILITE_V_PAR_A = 0.100f;

// ZMPT101B : le module de conditionnement (transformateur + pont diviseur)
// ramene le secteur 220V AC a une plage exploitable par l'ADC (0-3.3V), avec
// un rapport qui depend du montage exact (resistances du pont, cf. schema
// KiCad). FACTEUR_CALIBRATION_ZMPT convertit la tension RMS mesuree a l'ADC
// (apres retrait de l'offset Vcc/2) en tension secteur reelle. Valeur ici =
// PLACEHOLDER, a determiner par mesure comparative avec un multimetre/
// wattmetre sur le circuit reel (cf. GUIDE_ROUTAGE_20A.md, kicad/).
static const float ZMPT_FACTEUR_CALIBRATION = 300.0f; // A CALIBRER SUR LE MATERIEL REEL

// --- Nombre d'echantillons utilises pour l'auto-calibration des offsets DC
// (Vcc/2) au demarrage, cf. calibrerOffsets() dans main.cpp. Effectuee en
// supposant qu'aucun courant ne circule a l'allumage (mise sous tension du
// systeme avant celle des charges, cf. GUIDE_ASSEMBLAGE_ET_FLASH.md). ---
static const int N_ECHANTILLONS_CALIBRATION = 200;
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

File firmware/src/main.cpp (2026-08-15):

// TFC ULPGL - Systeme embarque IoT multicanal de sous-comptage
// Firmware de demonstration (maquette Wokwi / breadboard, cf. memoire S3.1-3.6)
//
// Reproduit l'architecture decrite au chapitre 2 : 5 taches FreeRTOS
// (Acquisition, Calcul, Credits, Persistance, ServeurAPI - cf. Annexe A.1),
// capteurs simules par des potentiometres, relais simules par des LED.

#include <Arduino.h>
#include <WiFi.h>
#include <AsyncTCP.h>
#include <ESPAsyncWebServer.h>
#include <ArduinoJson.h>
#include <LittleFS.h>
#include <Preferences.h>
#include <vector>

#include "config.h"

struct CanalEtat {
  float brutCourant;      // moyenne ADC brute (0-4095, en virgule flottante :
                           // cf. lireMoyenneADC, l'oversampling ne gagne en
                           // resolution que si la division n'est pas tronquee)
  float tensionADC_V;     // tension lue sur la broche (0-3.3V)
  float courant_A;        // courant simule (A)
  float puissance_W;      // puissance active (W)
  float cosPhi;           // facteur de puissance (cf. remarque dans TacheCalculPuissance)
  float energie_kWh;      // energie cumulee depuis la derniere recharge (kWh)
  float energie_prev_kWh; // valeur precedente, pour calculer le delta credit
  float credit_USD;       // credit restant
  bool  relaisFerme;      // etat du relais (true = alimente)
  bool  coupureVolontaire; // coupure demandee par le locataire lui-meme (absence, etc.)
  String nomAffiche;      // nom reel du locataire, saisi par le bailleur (facultatif)
  String dernierEvenement;
  unsigned long dernierHorodatageMs;
};

// Evenement pas encore recupere par une application (bailleur ou locataire).
// Cf. mettreEnAttente/route /api/historique/nouveaux : chaque canal "possede"
// sa portion de la file, purgee uniquement quand SON proprietaire (ou le
// bailleur pour son propre canal 0) la recupere - une simple consultation par
// le bailleur du canal d'un locataire ne purge pas la file de ce locataire.
struct EvenementEnAttente {
  int canal;
  String type;
  float valeur;
  unsigned long horodatageMs;
};

static CanalEtat canaux[NUM_CANAUX];
static float brutTension = 0.0f;
static float tensionSecteur_V = 0.0f;
static float tarifCourant = TARIF_USD_PAR_KWH;
static std::vector<EvenementEnAttente> evenementsEnAttente;

static SemaphoreHandle_t mutexCanaux;
static SemaphoreHandle_t mutexEvenements;
static AsyncWebServer server(80);

// ---------------------------------------------------------------------------
// Persistance NVS (Preferences) : credit + energie par canal (cf. S1.5.3)
// ---------------------------------------------------------------------------
static void chargerEtatDepuisNVS() {
  Preferences prefs;
  for (int i = 0; i < NUM_CANAUX; i++) {
    char ns[16];
    snprintf(ns, sizeof(ns), "canal%d", i);
    prefs.begin(ns, true);
    canaux[i].credit_USD      = prefs.getFloat("credit", CREDIT_INITIAL_USD);
    canaux[i].energie_kWh     = prefs.getFloat("energie", 0.0f);
    canaux[i].coupureVolontaire = prefs.getBool("coupvol", false);
    canaux[i].nomAffiche = prefs.getString("nom", "");
    prefs.end();
    canaux[i].energie_prev_kWh = canaux[i].energie_kWh;
    canaux[i].relaisFerme      = canaux[i].credit_USD > 0.0f && !canaux[i].coupureVolontaire;
    canaux[i].dernierEvenement = "demarrage";
    canaux[i].dernierHorodatageMs = millis();
  }

  Preferences config;
  config.begin("config", true);
  tarifCourant = config.getFloat("tarif", TARIF_USD_PAR_KWH);
  config.end();
}

static void sauverCanalDansNVS(int i) {
  char ns[16];
  snprintf(ns, sizeof(ns), "canal%d", i);
  Preferences prefs;
  prefs.begin(ns, false);
  prefs.putFloat("credit", canaux[i].credit_USD);
  prefs.putFloat("energie", canaux[i].energie_kWh);
  prefs.putBool("coupvol", canaux[i].coupureVolontaire);
  prefs.putString("nom", canaux[i].nomAffiche);
  prefs.end();
}

// ---------------------------------------------------------------------------
// Authentification par canal : renvoie l'index du canal dont les identifiants
// (login/mot de passe, cf. config.h) correspondent a la requete, ou -1 si
// aucun ne correspond. Utilise par toutes les routes protegees ci-dessous.
// ---------------------------------------------------------------------------
static int authentifierRequete(AsyncWebServerRequest *request) {
  for (int i = 0; i < NUM_CANAUX; i++) {
    if (request->authenticate(CANAL_USER[i], CANAL_PASSWORD[i])) {
      return i;
    }
  }
  return -1;
}

// Compte technicien (electricien) : role a part, non lie a un canal.
static bool authentifierElectricien(AsyncWebServerRequest *request) {
  return request->authenticate(ELECTRICIEN_USER, ELECTRICIEN_PASSWORD);
}

// ---------------------------------------------------------------------------
// File d'evenements en attente de recuperation par une application (cf.
// struct EvenementEnAttente). Purgee cote application par canal, pas cote
// firmware : l'ESP32 se contente d'empiler, bornee a MAX_EVENEMENTS_EN_ATTENTE
// (le plus ancien est abandonne si la file est pleine faute de recuperation).
// ---------------------------------------------------------------------------
static void mettreEnAttente(int canal, const String &type, float valeur) {
  if (xSemaphoreTake(mutexEvenements, pdMS_TO_TICKS(100)) == pdTRUE) {
    if (evenementsEnAttente.size() >= MAX_EVENEMENTS_EN_ATTENTE) {
      evenementsEnAttente.erase(evenementsEnAttente.begin());
    }
    evenementsEnAttente.push_back({canal, type, valeur, millis()});
    xSemaphoreGive(mutexEvenements);
  }
}

// ---------------------------------------------------------------------------
// Moyenne de plusieurs lectures ADC consecutives, pour lisser le bruit
// propre a l'ADC de l'ESP32 (cf. N_ECHANTILLONS_LISSAGE, config.h). Retournee
// en virgule flottante : avec un nombre d'echantillons suffisant, le bruit
// ADC lui-meme sert de dither et la moyenne peut tomber entre deux pas de
// l'ADC 12 bits - un gain reel de resolution qu'une division entiere (qui
// tronque au pas ADC natif) annulerait completement.
// ---------------------------------------------------------------------------
static float lireMoyenneADC(int pin, int nEchantillons) {
  long somme = 0;
  for (int k = 0; k < nEchantillons; k++) {
    somme += analogRead(pin);
  }
  return (float)somme / (float)nEchantillons;
}
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

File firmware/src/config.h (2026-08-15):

#pragma once

// NUM_CANAUX est un parametre, pas une valeur cablee en dur (cf. TFC S3.6.1).
// Maquette perfboard reelle : 4 canaux (1 bailleur + 3 locataires) - la carte
// soudee n'avait pas la place pour un 5e potentiometre/LED (locataire 4), qui
// a ete retire de la config (cf. GUIDE_MAQUETTE_BOITIER.md). La simulation
// Wokwi/breadboard visait 5 canaux ; la carte finale (PCB, chapitre 2) vise 8.
#define NUM_CANAUX 4

// --- Broches ADC1 des capteurs de courant (potentiometres simulant les ACS712) ---
// IMPORTANT : GPIO37 et GPIO38 (utilises dans le Tableau 2.2 du memoire) ne sont
// PAS sortis sur un ESP32 DevKitC standard (ni dans Wokwi) : ils existent sur la
// puce mais pas sur le connecteur du DevKitC. Ce mapping les evite. Le PCB final
// (module WROOM-32 nu, chapitre 2.5) peut conserver GPIO37/38 s'il les route
// explicitement sur son propre circuit imprime.
//
// Canaux 2 et 3 (locataire2/locataire3) : les potentiometres ont ete soudes
// inverses sur la carte perforee reelle (celui pose en position "locataire 2"
// est en fait cable sur la broche prevue pour "locataire 3", et vice versa).
// Plutot que de dessouder, on compense ici en inversant les deux broches -
// canal 2 lit la broche 35, canal 3 lit la broche 34.
static const int PIN_COURANT[NUM_CANAUX] = {
    36, // VP  - canal 0 : bailleur
    39, // VN  - canal 1 : locataire 1
    35, //     - canal 2 : locataire 2 (potentiometre soude a la place de loc.3)
    34  //     - canal 3 : locataire 3 (potentiometre soude a la place de loc.2)
};

// --- Broche ADC1 du capteur de tension (potentiometre simulant le ZMPT101B) ---
// Un seul capteur, commun a tous les canaux (cf. S1.3.2). Placee sur l'ADC1 (et
// non l'ADC2 comme dans le Tableau 2.2 du PCB final) car le point d'acces WiFi
// de la maquette est actif en permanence : l'ADC2 est alors inutilisable en
// continu (contrairement au PCB final ou seules de courtes fenetres ponctuelles
// sont concernees, cf. S1.4.3). GPIO33 est libre sur le DevKitC (ADC1_CH5).
static const int PIN_TENSION = 33;

// --- Broches de commande des relais (simulees par des LED) ---
// Canaux 0/1 (bailleur/locataire1) et 2/3 (locataire2/locataire3) : les LED
// ont ete soudees inversees deux a deux sur la carte perforee reelle. Compense
// ici plutot que de dessouder (meme logique que PIN_COURANT ci-dessus).
static const int PIN_RELAIS[NUM_CANAUX] = {5, 4, 14, 13};

// --- Constantes de conversion pour la simulation (a ajuster / etalonner sur le
//     vrai capteur ACS712 20A + diviseur 5V->3.3V lors du prototype physique) ---
static const float ADC_VREF = 3.3f;
static const int   ADC_RESOLUTION = 4095;
static const float COURANT_MAX_A = 20.0f;     // pleine echelle simulee (ACS712 20A)
static const float TENSION_MAX_V = 250.0f;    // pleine echelle simulee du secteur

// --- Lissage des lectures ADC : moyenne de N echantillons consecutifs au
// lieu d'une seule lecture, pour attenuer le bruit propre a l'ADC de l'ESP32
// (cf. TacheAcquisitionCapteurs). N=64 : au-dela du simple lissage, cet
// oversampling combine a une moyenne gardee en virgule flottante (et non
// tronquee a l'entier) gagne en resolution sous le pas natif de l'ADC 12 bits
// - necessaire pour tenir la tolerance de +/-0.01 (A ou V) demandee quand le
// potentiometre est immobile. 64 lectures ADC prennent encore largement moins
// de 10 ms au total, negligeable devant PERIODE_ACQUISITION_MS.
static const int N_ECHANTILLONS_LISSAGE = 64;
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

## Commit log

2026-07-18 Sauvegarde initiale du projet TFC multicanal Goma
    Schema/PCB KiCad complets et routes, firmware ESP32/FreeRTOS,
    application Flutter, memoire (rapport), presentation.
    [energie_locatif(1).kicad_sch, energie_locatif.kicad_sch, esp32-4-channel-relays.kicad_pcb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]
2026-07-18 Retire les fichiers de verrouillage LibreOffice du suivi
2026-07-27 Ajoute 3 profils app (bailleur/locataire/electricien), historique local, graphiques et corrige des bugs firmware/app
    - Firmware : lissage ADC (moyenne 8 echantillons), file d'evenements en attente
    (purge a la recuperation), fiche locataire (nom), cos(phi) expose, correction
    du bruit ADC sur canal coupe (credit qui derivait vers le negatif), tension
    deplacee sur ADC1/GPIO33 (bug ADC2 + WiFi permanent)
    - App Flutter : refonte en 3 profils avec authentification par canal
    (bailleur/locataire/electricien), coupure volontaire, historique local
    SQLite (plus de dependance au stockage firmware), graphiques de
    consommation jour/semaine/mois, resume bailleur, tarif et fiche editables,
    cor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
    [bom.csv]
2026-08-15 Maquette a 4 canaux : compense le cablage inverse, courant lineaire, reduction du bruit ADC
    - NUM_CANAUX 5->4 (locataire4 retire, pas de place sur la carte perforee)
    - PIN_COURANT/PIN_RELAIS compenses pour le cablage reellement soude
    (LED bailleur/locataire1 et locataire2/locataire3 inversees, potentiometre
    locataire2/locataire3 inverse)
    - courant_A lineaire (0-20A) au lieu de la forme en V precedente
    - 64 echantillons ADC moyennes en virgule flottante + filtre EMA entre
    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
2026-08-15 Met a jour le rapport TFC pour la maquette a 4 canaux
    - Tableau 3.4 (cablage) et 3.5 (mesures) corriges/completes avec les
    vraies valeurs relevees sur la maquette physique (butees min/max)
    - Tableau 3.6 (coupure/retablissement) complete avec les observations
    reelles testees sur l'application mobile
    - Figures 3.1/3.2 (photos du prototype assemble) inserees
    - Toutes les mentions "5 canaux"/"cinq canaux" corrigees en "4 canaux"
    dans le texte, les legendes et le devis (Tableau 3.3)
    - Note ajoutee sur la variation du courant/tension en position
    intermediaire du potentiometre (bruit ADC residuel)
    - PDF regenere
2026-08-15 Ajoute le firmware cible pour le PCB (8 canaux, capteurs reels) et un README de depot
    - firmware_pcb_capteurs_reels/ : firmware pour le PCB 8 canaux avec
    ACS712 + ZMPT101B (echantillonnage synchrone 40 pts/cycle 50Hz, RMS,
    P/S/Q/cos(phi) reellement calcules, cf. memoire S2.7 et Tableau 2.2).
    PCB pas encore fabrique : code compile mais non teste sur materiel reel
    (cf. README du dossier). A cote de firmware/, la version maquette
    validee (potentiometres, 4 canaux).
    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
2026-08-15 Precise l'etat du routage PCB dans le README et exclut les guides/sauvegardes locales
    - README : mentionne qu'il reste 10 pistes a tracer sur le PCB (routage non termine)
    - .gitignore : exclut les fichiers .bak, les temporaires drawio et
    GUIDE_EXPLICATION_CODE.md/pdf (guide personnel, pas destine au depot public)
2026-08-15 Routage PCB 20A, schema de branchement et mise a jour de la presentation
    - kicad/ : outils et guide de routage pour tenir 20A (GUIDE_ROUTAGE_20A,
    fix_dsn_widths_20A.py, replan_pcb_20A.py, strip_tracks.py), PCB/schema
    mis a jour en consequence. Routage non termine : il reste 10 pistes a
    tracer (cf. README racine).
    - schema_branchement.png et diagramme_cas_utilisation.drawio ajoutes
    - presentation de soutenance et GUIDE_MAQUETTE_BOITIER mis a jour
    - retire l'ancienne sauvegarde du rapport (avant corrections)
    [multical.dsn, multical.kicad_pcb, multical.kicad_sch]
2026-08-15 Corrige la legende de la Figure 3.2 (LED reellement allumees)
    Locataire 1 et locataire 3 etaient allumes (canaux fermes) sur la photo,
    pas bailleur et locataire 1 comme indique precedemment ; bailleur et
    locataire 2 etaient eteints a cet instant.
